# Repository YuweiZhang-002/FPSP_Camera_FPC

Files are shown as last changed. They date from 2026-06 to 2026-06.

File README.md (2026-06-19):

# FPSP_Camera_FPC

This repo contains FPC schematics of the newly developed FPSP camera project on an FPC board, aiming for super-high-speed parallel image processing.

## Repository Structure
| Directory | Use |
| --- | --- |
| archive_old/ | Archived initial design (**not working**) |
| custom_fp/ | Footprint from external libraries |
| docs/ | Documentation gathered from external sources |
| camera_bringup_min/ | RP2350 firmware: OV5640 driver and PIO heartbeat |

## TODO
- [x] RP2350 Power Supply Layout
- [ ] Add Proper Power Sequencing
- [ ] Source RP2354 A4
- [ ] Source B2B Connector
- [x] B2B Connector Pinout + Layout
- [x] HSTX Layout

## 12/12/2025 PCB ordering notes

- order FR-4 board with SMT assembly, run thru **functionality tests**
- order FPC without SMT assembly, test the **FPC characteristics and stiffener position**
- RP2345A and ICM45686 IMU ordered separately to test the functionality. Once it passes the prototype test, order at JLCPCB via **global sourcing** and prep for next assembly

### TODO
 - [x] Place JLCPCB order
 - [ ] functionality test, FR4 prototype
 - [ ] functionality test, FPC stiffener position
------ 
 - [ ] sourcing RP2345A
 - [ ] sourcing ICM45686
 - [ ] sourcing board-to-board connectors from Molex 

## Firmware

Camera (OV5640) bring-up firmware for the Raspberry Pi RP2350 (pico2 board).

### Build

Standard Raspberry Pi Pico SDK CMake project. Open it with the
**Raspberry Pi Pico** VS Code extension, or configure manually:

```sh
cmake -B build -G Ninja
cmake --build build
```

Target platform: `rp2350` / board `pico2` (set in `CMakeLists.txt`).

Key files: `main.c`, `camera_bringup_min/` (OV5640 driver + PIO heartbeat),
`CMakeLists.txt`, `pico_sdk_import.cmake`.

### Firmware dependencies

Depends on the [Raspberry Pi Pico SDK](https://github.com/raspberrypi/pico-sdk)
(v2.2.0), licensed under BSD-3-Clause. The SDK is **not** included in this
repository — install it via the Pico VS Code extension or set the
`PICO_SDK_PATH` environment variable to your local SDK checkout.

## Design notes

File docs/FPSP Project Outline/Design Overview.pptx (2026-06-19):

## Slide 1

Design Overview: one processing unit

Industrial CMOS sensor

(front-end integrated)

Options:
Sony: IMX273 / IMX287
OnSemi: python series
Teledyne: EV76C560 / EV76C570

one “pixel”

Vdd

MSPM0C1104 microcontroller

comp flag

global I/O

registers

enable flag

E

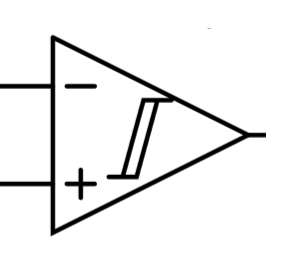
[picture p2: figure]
enter image description here

neighbour I/O & register values

A/D bus

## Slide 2

Design Overview: overall architecture

pixel unit

pixel processor

N pixels

···

···

···

···

···

···

Pixel array

···

···

N pixels

Himax HX6537-A
Pixel Array Microprocessor

···

···

A/D bus 1

···

A/D bus k

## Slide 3

Model | Resolution (pixels) | Pixel Size (µm) | Optical Format | Max Frame Rate (fps) | Output Interface(s) | Notes
Sony IMX273 | 1456 × 1088 (~1.58 MP) | 3.45 × 3.45 | 1/2.9″ (~6.3 mm) | ~226.5 (10-bit mode) | Sub-LVDS / MIPI (varies) | Low-noise, high-speed, common in inspection
Sony IMX287 | 728 × 544 (~0.4 MP) | 6.9 × 6.9 | 1/2.9″ (~6.3 mm) | ~436.9 (10-bit mode) | Sub-LVDS / MIPI (varies) | Large pixels, high sensitivity, good in NIR / low light
OnSemi PYTHON1300 | 1280 × 1024 (1.3 MP) | 4.8 × 4.8 | 1/2″ | ~210 (LVDS) / ~43 (parallel) | LVDS (multi-lane) / parallel | supports ROI, programmable gain, CDS.
OnSemi PYTHON5000 | 2592 × 2048 (~5.3 MP) | 4.8 × 4.8 | ~1″ | Up to ~100 (Zero ROT mode) | LVDS (e.g., 8-lane) | Higher resolution, suited for machine vision with high data bandwidth.
Teledyne EV76C560 | 1280 × 1024 (1.31 MP) | 5.3 × 5.3 | 1/1.8″ | ~60 full res (VGA/cropped >100) | Parallel 10-bit | Dual shutter modes, WDR/HDR, ROI, defect correction.
Teledyne EV76C570 | 1600 × 1200 (~2.0 MP) | 4.5 × 4.5 | 1/1.8″ | ~50 full res | Parallel 10-bit | 2 MP variant, good low-light and dynamic range features.

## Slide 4

Design Overview: overall architecture v2.0

OV5640

···

FPC

DVP

PIO

···

RP2354A

Inter-FPC connection

Strengthened FPC

Pin Header

FPGA board
(pynq / zynq)

PL: data receive
PS: data process

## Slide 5

Layout Overview

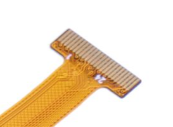
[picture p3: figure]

Main FPC

Strengthened FPC

BUCK/LDO

Pin Header to FPGA

OV5640
(front)

ZIF Connector

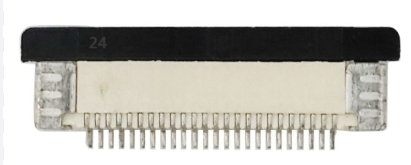
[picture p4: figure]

Vin

···

···

RP2354A
(back)

ASM330LHH
(back)

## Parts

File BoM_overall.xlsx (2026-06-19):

Part Name | Series Number / Description | Quantity | Source | Unit Price (GBP) | Order Code / Mouser No | Link
USB_B_Micro | USB_Micro-B_Molex_47346-0001 | 5 | Farnell | 1.2 | 1568026 | https://uk.farnell.com/molex/47346-0001/micro-usb-conn-2-0-type-b-r-a/dp/1568026
Conn_02x04_Counter_Clockwise | Molex_SlimStack_502430-0822_2x04_P0.40mm_Vertical | 5 | Mouser | 0.52 | 538-50243-00822 | https://www.mouser.co.uk/ProductDetail/Molex/502430-0822?qs=byeeYqUIh0ORWNduRUQWFQ%3D%3D
Conn_02x07_Counter_Clockwise | Molex_SlimStack_502430-1430_2x07_P0.40mm_Vertical | 10 | Farnell | 0.465 | 3911710 | https://uk.farnell.com/molex/502430-1430/mezzanine-conn-hdr-14pos-2row/dp/3911710
Conn_02x04_Counter_Clockwise | Molex_SlimStack_502426-0812_2x04_P0.40mm_Vertical | 5 | Mouser | 0.55 | 538-50242-60812 | https://www.mouser.co.uk/ProductDetail/Molex/502426-0812?qs=byeeYqUIh0O%252BW14PukUHXw%3D%3D
Conn_02x07_Counter_Clockwise | Molex_SlimStack_502426-1430_2x07_P0.40mm_Vertical | 10 | Farnell | 0.868 | 3500584 | https://uk.farnell.com/molex/502426-1430/mezzanine-conn-rcpt-14pos-2row/dp/3500584
SM03B-SRSS-TB | JST_SH_SM03B-SRSS-TB_1x03-1MP_P1.00mm_Horizontal | 5 | Farnell | 0.52 | 1679118 | https://uk.farnell.com/jst-japan-solderless-terminals/sm03b-srss-tb-lf-sn/header-r-a-3way/dp/1679118
IMU | ICM-45686 | 5 | Farnell | 7.884 | 4572492 | https://uk.farnell.com/tdk/icm-45686/mems-module-6-axis-1-71v-3-6v/dp/4572492
LDO | TLV73315PDRV | 5 | Mouser | 0.44 | 595-TLV73315PQDRVRQ1 | https://www.mouser.co.uk/ProductDetail/Texas-Instruments/TLV73315PQDRVRQ1?qs=Euq2YPj5ArIsMkihzFWY8w%3D%3D
MCU | RP2354A | 5 | Mouser | 0.751 | 358-SC151113 | https://www.mouser.co.uk/ProductDetail/Raspberry-Pi/SC151113-A4?qs=4dK74SdgGtxoqGOrTUEtvA%3D%3D
Mems | SiT8008BI-13-33E-12.000000G | 5 | Mouser | 0.721 | 788-8008BI1333E12G | https://www.mouser.co.uk/ProductDetail/SiTime/SiT8008BI-13-33E-12.000000G?qs=dMZC7um9hO8fSmv9H8HgEQ%3D%3D
FPC socket | molex 52435-2471 | 10 | Farnell | 2.352 | 2396220 | https://uk.farnell.com/molex/52435-2471/connector-ffc-fpc-24pos-1row-0/dp/2396220
Camera | OV5640 - 24pin fpc | 2 | Ali | N/A | N/A | https://www.aliexpress.com/p/tesla-landing/index.html?UTABTest=aliabtest125094_24784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
2.54mm pin header: from UCL
0603 R&C: from UCL

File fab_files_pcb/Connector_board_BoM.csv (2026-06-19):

Reference | Qty | Value | DNP | Exclude from BOM | Exclude from Board | Footprint | Datasheet
D1 | 1 | LED |  |  |  | Diode_SMD:D_0603_1608Metric | ~
J1 | 1 | USB_B_Micro |  |  |  | Connector_USB:USB_Micro-B_Molex_47346-0001 | ~
J2 | 1 | Conn_02x04_Counter_Clockwise |  |  |  | Connector_Molex:Molex_SlimStack_502430-0820_2x04_P0.40mm_Vertical | ~
J3 | 1 | Conn_02x06_Counter_Clockwise |  |  |  | Connector_PinHeader_2.54mm:PinHeader_2x06_P2.54mm_Vertical | ~
J4 | 1 | Conn_02x07_Counter_Clockwise |  |  |  | Connector_Molex:Molex_SlimStack_502430-1410_2x07_P0.40mm_Vertical | ~
J5 | 1 | SM03B-SRSS-TB |  |  |  | Connector_JST:JST_SH_SM03B-SRSS-TB_1x03-1MP_P1.00mm_Horizontal | ~
R1 | 1 | 10k |  |  |  | Resistor_SMD:R_0603_1608Metric_Pad0.98x0.95mm_HandSolder | ~

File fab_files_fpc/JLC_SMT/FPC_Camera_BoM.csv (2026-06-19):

Comment | Designator | Footprint | LCSC Part Number | Qty | DNP | Exclude from BOM | Exclude from Board
0.1u | C1,C2,C15,C16,C21,C22,C23 | Capacitor_SMD:C_0402_1005Metric | C60474 | 7
100n | C3,C5,C6,C7,C8,C9,C10,C11,C12,C13,C14,C25,C32 | Capacitor_SMD:C_0402_1005Metric | C60474 | 13
4.7u | C4,C17,C18,C19 | Capacitor_SMD:C_0402_1005Metric | C106859 | 4
100n | C20 | Capacitor_SMD:C_0603_1608Metric_Pad1.08x0.95mm_HandSolder | C1590 | 1 | DNP |  | Excluded from board
22pF | C24 | Capacitor_SMD:C_0402_1005Metric | C106203 | 1
1u | C26,C27,C28,C29,C30,C31 | Capacitor_SMD:C_0402_1005Metric | C106253 | 6
LED | D1,D2,D3,D4 | Diode_SMD:D_0603_1608Metric | C2286 | 4
MountingHole | H1,H2,H3,H4 | MountingHole:MountingHole_2.7mm_M2.5 | N/A | 4
Conn_01x24_Socket | J1 | Connector_FFC-FPC:TE_2-1734839-3_1x23-1MP_P0.5mm_Horizontal | C6668214 | 1
Conn_02x04_Counter_Clockwise | J2 | Connector_Molex:Molex_SlimStack_502426-0810_2x04_P0.40mm_Vertical | C563931 | 1
Conn_02x07_Counter_Clockwise | J3 | Connector_Molex:Molex_SlimStack_502426-1410_2x07_P0.40mm_Vertical | C563932 | 1
SM03B-SRSS-TB | J4 | Connector_JST:JST_SH_SM03B-SRSS-TB_1x03-1MP_P1.00mm_Horizontal | N/A | 1 | DNP |  | Excluded from board
USB_B_Micro | J5 | RP2350_60QFN_minimal:USB_Micro-B_Amphenol_10103594-0001LF_Horizontal_modified | N/A | 1 | DNP |  | Excluded from board
Conn_02x06_Odd_Even | J6 | Connector_PinHeader_2.54mm:PinHeader_2x06_P2.54mm_Vertical | N/A | 1 | DNP |  | Excluded from board
Conn_01x02 | J7 | Connector_PinHeader_2.54mm:PinHeader_1x02_P2.54mm_Vertical | C492401 | 1
SolderJumper_2_Open | JP1,JP2,JP3 | Jumper:SolderJumper-2_P1.3mm_Open_RoundedPad1.0x1.5mm | N/A | 3 |  | Excluded from BOM
3.3u | L1 | Inductor_SMD:L_pol_2016 | C42411119 | 1
10k | R1 | Resistor_SMD:R_0402_1005Metric_Pad0.72x0.64mm_HandSolder | C60489 | 1
33 | R2 | Resistor_SMD:R_0402_1005Metric | C15011 | 1
27 | R3,R4 | Resistor_SMD:R_0402_1005Metric | C15011 | 2
DNF | R5,R8 | Resistor_SMD:R_0603_1608Metric_Pad0.98x0.95mm_HandSolder | N/A | 2 | DNP |  | Excluded from board
1k | R6,R15 | Resistor_SMD:R_0402_1005Metric | C105637 | 2
0 | R7 | Resistor_SMD:R_0603_1608Metric_Pad0.98x0.95mm_HandSolder | N/A | 1 | DNP |  | Excluded from board
0R | R9,R11,R13 | Resistor_SMD:R_0402_1005Metric | C60485 | 3
DNF | R10 | Resistor_SMD:R_0402_1005Metric | N/A | 1
10k | R12,R14,R16,R17,R18,R19,R20,R21 | Resistor_SMD:R_0402_1005Metric | C60489 | 8
TestPoint | TP1 | TestPoint:TestPoint_Pad_D1.0mm | N/A | 1
ICM-45686 | U1 | ICM_45686:IC_ICM-45686 | N/A | 1
W25Q128JVS | U2 | Package_SO:SOIC-8_5.3x5.3mm_P1.27mm | N/A | 1 | DNP |  | Excluded from board
RP2354A_60QFN | U3 | projLib:RP2350-QFN-60-1EP_7x7_P0.4mm_EP3.4x3.4mm_ThermalVias | C41378174 | 1
TLV75533PDRV | U4 | Package_SON:WSON-6-1EP_2x2mm_P0.65mm_EP1x1.6mm | C2861750 | 1
TLV73328PDRV | U5 | Package_SON:WSON-6-1EP_2x2mm_P0.65mm_EP1x1.6mm | N/A | 1
TLV73315PDRV | U6 | Package_SON:WSON-6-1EP_2x2mm_P0.65mm_EP1x1.6mm | N/A | 1
SiT8008xx-1x-xxE | Y1 | Oscillator:Oscillator_SMD_SiT_PQFN-4Pin_2.5x2.0mm | C825127 | 1

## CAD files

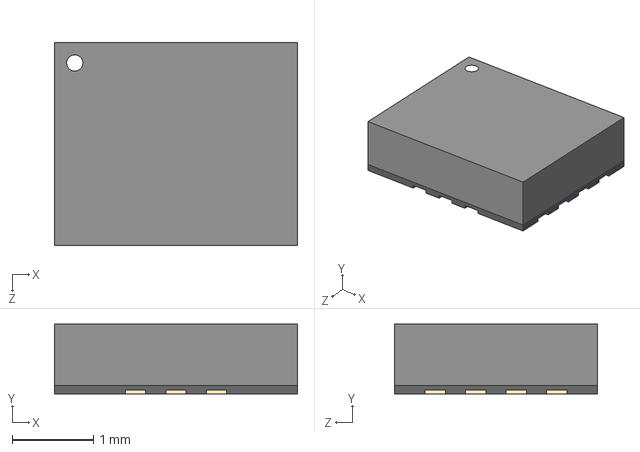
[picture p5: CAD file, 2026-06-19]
custom_fp/ICM_45686/ICM-45686.step
3.00 x 0.86 x 2.50 mm

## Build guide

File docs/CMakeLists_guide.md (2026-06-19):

# CMakeLists 编写与模块化构建指南

> 工程根目录：`D:\Cursor\New_Tests`
> 目标芯片：RP2350（Pico 2）
> SDK：本地路径 `pico-sdk-master`（version 2.2.0）
> 构建系统：CMake + Ninja，由 VS Code Raspberry Pi Pico 扩展驱动

---

## 1. 核心概念：CMake Target 导入机制（为什么能用 hardware_i2c）

这是理解整个 Pico SDK 构建的关键。

### 1.1 不是"#include 头文件"就能用库 —— 是"链接一个 CMake target"

用户容易混淆两个概念：

**❌ 错误认知：**
```
#include "hardware/i2c.h"        ← 这只是让 C 预处理器找到头文件
→ 系统就能用 i2c 库了
```

**✅ 正确流程：**
```
第1步（CMake 配置阶段）：
  └─ pico_sdk_init() 
     └─ 读取 pico-sdk-master/ 内部的 CMake 脚本
        └─ 定义一个虚拟的"target"叫 hardware_i2c
           ├─ 这个 target 包含：
           │   ├─ 源文件在哪（<SDK>/src/rp2_common/hardware_i2c/...）
           │   ├─ 头文件目录在哪（指向 hardware_i2c.h）
           │   └─ 依赖什么其他库（hardware_base, hardware_gpio, ...）
           └─ 在 CMake 全局作用域注册这个 target 的定义

第2步（编译阶段）：
  └─ 你写 target_link_libraries(new_tests_app PUBLIC hardware_i2c)
     └─ CMake 查全局 target 表，找到 hardware_i2c 的定义
        └─ 提取该 target 的：源文件 → 编译、头文件路径 → -I 选项、依赖 → 递归链接
        └─ 把这些信息传给编译器

第3步（代码编译）：
  └─ 编译 main.c
     └─ C 预处理器执行 #include "hardware/i2c.h"
        └─ 使用第2步 CMake 提供的 -I<path-to-header> 找到它
```

**一句话：** `target_link_libraries()` 是 CMake 层面的"声明依赖"，`#include` 是 C 层面的"查找头文件"，两者缺一不可，但发生在不同阶段。

### 1.2 pico-sdk-master 的三层结构

```
pico-sdk-master/
│
├─ pico_sdk_init.cmake           ← 核心：定义所有 target（hardware_i2c、pico_stdlib 等）
│  （被 pico_sdk_import.cmake 的 include() 语句触发）
│
├─ pico_sdk_import.cmake         ← 定位脚本：告诉 CMake "SDK 根在哪"
│  （你的工程根目录有一份副本，你 include() 的是那一份）
│
├─ CMakeLists.txt                ← 仅当 SDK 作为独立 CMake 项目时用
│  （你的工程不用它；它让 SDK 开发者能 cd pico-sdk-master && cmake . && make）
│
├─ src/rp2_common/
│  ├─ hardware_i2c/
│  │  ├─ i2c.c
│  │  └─ include/hardware/i2c.h
│  ├─ hardware_gpio/
│  │  ├─ gpio.c
│  │  └─ include/hardware/gpio.h
│  └─ ...
│
├─ external/
│  └─ pico_sdk_import.cmake       ← 模板原件（供用户复制）
│
└─ cmake/
   ├─ hardware_i2c.cmake          ← 定义 hardware_i2c target 的脚本
   ├─ hardware_gpio.cmake
   └─ ...（pico_sdk_init.cmake 会遍历这些文件）
```

### 1.3 执行流程图（从你的根 CMakeLists 到系统识别 hardware_i2c）

```mermaid
flowchart TD
    A["根 CMakeLists.txt<br/>include pico_sdk_import.cmake"] -->|1. 此时寻找 SDK 路径| B["pico_sdk_import.cmake<br/>读 PICO_SDK_PATH 环境变量/缓存"]
    B -->|2. 定位成功| C["pico_sdk_import.cmake<br/>include ${PICO_SDK_PATH}/pico_sdk_init.cmake"]
    C -->|3. 进入 SDK 初始化| D["pico_sdk_init.cmake<br/>遍历 cmake/ 目录"]
    D -->|4. 发现 hardware_i2c.cmake| E["hardware_i2c.cmake<br/>执行 add_library + include_dirs + source_dir"]
    E -->|5. 在全局 target 表注册| F["CMake 全局作用域<br/>现在有 hardware_i2c target"]
    
    G["后续你的代码<br/>target_link_libraries app hardware_i2c"] -->|6. 查询全局表| F
    F -->|7. 找到 target| H["CMake 提取：<br/>- 源文件位置<br/>- 头文件路径<br/>- 依赖关系"]
    H -->|8. 传给编译器| I["clang/gcc<br/>-I&lt;i2c.h 路径&gt; -l&lt;i2c lib&gt;"]
    
    J["你的 main.c<br/>#include 'hardware/i2c.h'"] -->|9. C 预处理| K["预处理器<br/>查找 -I 指定的路径"]
    K -->|10. 命中| L["找到文件<br/>include/hardware/i2c.h"]
```

---

## 2. 目录结构与分层职责

```text
New_Tests/                         ← 工程根
├─ CMakeLists.txt                  ← 顶层：定义最终可执行文件 + 组装模块
├─ pico_sdk_import.cmake           ← 工程自己的 SDK 定位脚本（从 SDK/external/ 复制）
├─ main.c                          ← 应用入口
│
├─ build/                          ← CMake 构建产物（可删）
│  └─ new_tests_app.uf2
│
├─ docs/
│  └─ CMakeLists_guide.md          ← 本文件
│
├─ camera_bringup_min/             ← 驱动层模块 1
│  ├─ CMakeLists.txt               ← 模块构建脚本
│  ├─ ov5640.c / ov5640.h
│  └─ heartbeat.pio
│
├─ imu_driver/                     ← 驱动层模块 2（示例）
│  ├─ CMakeLists.txt               ← 模块构建脚本
│  ├─ mpu6050.c / mpu6050.h
│  └─ ...
│
└─ pico-sdk-master/                ← Pico SDK（第三方，不动）
   ├─ pico_sdk_init.cmake          ← 定义所有 hardware_* target
   ├─ pico_sdk_import.cmake        ← 定位脚本副本
   ├─ CMakeLists.txt               ← SDK 自己的构建（你不用）
   ├─ src/rp2_common/
   └─ cmake/
```

| 层级 | CMakeLists 职责 | 禁忌 |
|---|---|---|
| **顶层（New_Tests/）** | ① 找 SDK (`include(pico_sdk_import.cmake)`) ② 初始化 SDK (`pico_sdk_init()`) ③ 注册所有子模块 (`add_subdirectory`) ④ 定义最终可执行文件 (`add_executable`) ⑤ 链接库 | 不要在这里写 `add_library(驱动库 ...)` |
| **模块层（camera_bringup_min/ 等）** | ① 定义该模块是静态库还是对象库 (`add_library`) ② 暴露自己的头文件目录 (`target_include_directories PUBLIC`) ③ 声明自己的依赖 (`target_link_libraries PUBLIC`) | 不要 `include(pico_sdk_import.cmake)` / `project()` / `pico_sdk_init()` |
| **SDK（pico-sdk-master/）** | 不写 | 完全不动 |

---

## 3. 顶层 `CMakeLists.txt` 完整模板与逐行解读

```cmake
# ========== 区块 A：VS Code 扩展样板（保持不动）==========
if(WIN32)
    set(USERHOME $ENV{USERPROFILE})
else()
    set(USERHOME $ENV{HOME})
endif()
set(sdkVersion 2.2.0)
set(toolchainVersion 14_2_Rel1)
set(picotoolVersion 2.2.0-a4)
set(picoVscode ${USERHOME}/.pico-sdk/cmake/pico-vscode.cmake)
if (EXISTS ${picoVscode})
    include(${picoVscode})
endif()
# 说明：VS Code 扩展启动时自动补充此段，包含交叉编译工具链路径
# ============================================================

# ========== 区块 B：CMake 基础设定 ==========
cmake_minimum_required(VERSION 3.13...3.27)

# 关键：在 project() 之前 include SDK 定位脚本
# 这样工具链才能及时切到 ARM 交叉编译
include(pico_sdk_import.cmake)

# 声明项目名 + 支持的语言
# C：C 代码
# CXX：C++ 代码  
# ASM：ARM 汇编（必要，不是可选）
project(new_tests C CXX ASM)

# 设置代码标准
set(CMAKE_C_STANDARD 11)
set(CMAKE_CXX_STANDARD 17)

# ========== 区块 C：芯片 / 板型选择（pico_sdk_init 之前）==========
if(NOT DEFINED PICO_PLATFORM)
    set(PICO_PLATFORM rp2350)  # RP2040 / RP2350 / RP2350-arm-s / RP2350-riscv
endif()
if(NOT DEFINED PICO_BOARD)
    set(PICO_BOARD pico2)      # pico / pico_w / pico2 / pico2_w
endif()

# ========== 区块 D：初始化 SDK（在这里把所有 target 导入到全局作用域）==========
# 这个函数会：
# 1. 遍历 pico-sdk-master/cmake/ 目录下所有 .cmake
# 2. 逐个执行，每个都调用 add_library() 定义一个 target
#    → hardware_i2c target、hardware_gpio target、pico_stdlib target ...
# 3. 把这些 target 注册到 CMake 全局 target 表
# 4. 后续 add_subdirectory() 和 add_executable() 都能看到这些 target
pico_sdk_init()

# ========== 区块 E：组装模块层（此时所有 SDK target 已就位）==========
# 每个 add_subdirectory() 都会：
# 1. 切换到那个目录的 CMakeLists.txt
# 2. 执行其中的 add_library()，新增一个用户定义的 target
# 3. 回到根 CMakeLists 继续
add_subdirectory(camera_bringup_min)
add_subdirectory(imu_driver)         # 新增模块示例

# ========== 区块 F：定义最终可执行文件 ==========
add_executable(new_tests_app
    main.c
)

# 处理 .pio 文件：编译为 .pio.h 并加入 include 路径
pico_generate_pio_header(new_tests_app
    ${CMAKE_CURRENT_LIST_DIR}/camera_bringup_min/heartbeat.pio
)

# 声明本 executable 的 include 搜索路径
# PRIVATE：这个 include 路径不会传递给链接本 target 的上游
# （这里用 PRIVATE 是对的，因为 main 是最终目标，没有上游）
target_include_directories(new_tests_app PRIVATE
    ${CMAKE_CURRENT_LIST_DIR}/camera_bringup_min
    ${CMAKE_CURRENT_LIST_DIR}/imu_driver
)

# ========== 区块 G：链接依赖（核心）==========
# target_link_libraries 是 CMake 从 target 表里提取依赖信息的地方
# PUBLIC：依赖会传递给链接本 target 的上游（新_tests_app 是最终目标，实际没上游）
# PRIVATE：依赖只给自己用，不向外传播
target_link_libraries(new_tests_app
    # SDK 标准库
    pico_stdlib                      # stdio_init_all, sleep_ms, printf 重定向
    
    # 硬件库（由 pico_sdk_init() 导入）
    hardware_pio                      # PIO 状态机
    
    # 用户定义的驱动模块（由 add_subdirectory() 注册）
    camera_bringup_min               # 调用其 CMakeLists 中的 add_library()
    imu_driver
)

# ========== 区块 H：stdio 配置 ==========
pico_enable_stdio_uart(new_tests_app 1)  # 1 = 启用；0 = 禁用
pico_enable_stdio_usb(new_tests_app 0)   # 本工程用 UART，不用 USB CDC

# ========== 区块 I：生成附加产物 ==========
# 只有 ELF 满足调试需求，还要生成：
# - .uf2：烧录格式（Pico 的 UF2 bootloader 认这个）
# - .hex：十六进制（某些烧录工具用）
# - .bin：纯二进制（无 header）
# - .map：链接器 map，看符号地址和段布局
# - .dis：反汇编，看生成的 arm 指令
pico_add_extra_outputs(new_tests_app)
```

### 关键顺序约束（红线规则）

```
❌ WRONG                          ✅ CORRECT
───────────────────────────────────────────────────────
project()                         include(pico_sdk_import.cmake)
include(sdk)                      project()
PICO_PLATFORM = ...               PICO_PLATFORM = ...
pico_sdk_init()                   pico_sdk_init()
                                  add_subdirectory()
pico_sdk_init()                   add_executable()
add_subdirectory()
```

---

## 4. 模块层 `CMakeLists.txt` 完整模板

**场景：** 你在 `camera_bringup_min/` 下写 CMakeLists.txt

```cmake
# ========== 模块基本信息 ==========
# 通常写成注释说明这个模块的用途
# camera_bringup_min: OV5640 相机 SCCB 初始化 + RGB565 配置
# 依赖：hardware_gpio, hardware_i2c, hardware_pwm, hardware_clocks

# ========== 定义静态库 ==========
# add_library(<库名> <库类型> <源文件>...)
# 库名：必须和顶层 CMakeLists 中 target_link_libraries 写的名字一致
# 库类型：
#   STATIC  - 静态库 .a（编译时链接，不是 DLL）
#   SHARED  - 动态库 .so/.dll（运行时加载）
#   OBJECT  - 对象库（仅作中间产物，不生成 .a）
#   INTERFACE - 仅头文件，不编译源代码
add_library(camera_bringup_min STATIC
    ov5640.c
)

# ========== 暴露头文件目录 ==========
# 目的：让调用方能写 #include "ov5640.h"（而不是 #include "camera_bringup_min/ov5640.h"）
# 作用域：
#   PUBLIC   - 调用方也能用这个 include 路径
#              （假设 ov5640.h 里有调用方需要的类型定义）
#   PRIVATE  - 只给自己用，不向外暴露
#   INTERFACE - 不给自己用，只暴露给调用方（纯头文件库用这个）
target_include_directories(camera_bringup_min PUBLIC
    ${CMAKE_CURRENT_LIST_DIR}
)

# ========== 声明依赖关系 ==========
# 目的：告诉 CMake 这个库需要什么
# 作用：
#   1. 编译 camera_bringup_min 时会获得这些依赖的编译选项（-I / -D 等）
#   2. 当上层 target_link_libraries(app camera_bringup_min) 时，
#      这些依赖会自动"传播"给 app（因为用的是 PUBLIC）
target_link_libraries(camera_bringup_min PUBLIC
    pico_stdlib                    # 使用 printf、sleep_ms
    hardware_gpio                  # gpio_init、gpio_set_dir
    hardware_i2c                   # i2c_init、i2c_write_blocking
    hardware_pwm                   # pwm_init（XCLK 输出）
    hardware_clocks                # clock_get_hz
)
```

### 为什么模块层不需要 `include(pico_sdk_import.cmake)`？

因为这个脚本只需要执行一次，就能把所有 target 注册到全局作用域。一旦执行过，所有 `add_subdirectory()` 的子模块都能看到。

```
顶层 CMakeLists：
  include(pico_sdk_import.cmake)    ← 一次性，全局生效
  pico_sdk_init()                   ← 把 hardware_i2c 等 target 写进全局表
  add_subdirectory(camera_bringup_min)
    ↓
    camera_bringup_min/CMakeLists：
      （不需要 include，hardware_i2c 已在全局表）
      target_link_libraries(camera_bringup_min PUBLIC hardware_i2c)
      ✅ 能找到 hardware_i2c
```

---

## 5. PUBLIC / PRIVATE / INTERFACE 三大作用域

这是 CMake 最容易踩坑的地方。表格说明：

| 关键字 | 自己编译时用 | 链接进自己时用 | 上游链接自己时用 |
|---|---|---|---|
| **PRIVATE** | ✅ | ✅ | ❌ |
| **PUBLIC** | ✅ | ✅ | ✅ |
| **INTERFACE** | ❌ | ❌ | ✅ |

### 实战例子

**模块 `camera_bringup_min`：**
```cmake
target_include_directories(camera_bringup_min PUBLIC
    ${CMAKE_CURRENT_LIST_DIR}
)
```
→ 为什么 PUBLIC？
  - camera_bringup_min 自己用 ov5640.h，需要这个 include 路径 ✅
  - main.c（上游）也要 `#include "ov5640.h"`，也需要这个路径 ✅
  - 所以必须是 PUBLIC

```cmake
target_link_libraries(camera_bringup_min PUBLIC
    hardware_i2c
)
```
→ 为什么 PUBLIC？
  - camera_bringup_min 编译时需要 hardware_i2c 的源文件和头文件 ✅
  - ov5640.h 里如果暴露了 i2c_inst_t 类型给调用方，main.c 包含它时编译器需要找到 hardware/i2c.h ✅
  - 所以必须是 PUBLIC

**应用 `new_tests_app`：**
```cmake
target_include_directories(new_tests_app PRIVATE
    ${CMAKE_CURRENT_LIST_DIR}/camera_bringup_min
)
```
→ 为什么 PRIVATE？
  - new_tests_app 本身是最终目标，没有上游链接它 ✅ PRIVATE 足矣
  - （即便用 PUBLIC，也不会有不同，因为没人链接 new_tests_app）

```cmake
target_link_libraries(new_tests_app
    camera_bringup_min
)
```
→ 作用域选择？
  - new_tests_app 是最终可执行文件，不会被其他 target 链接
  - 使用 PRIVATE 或 PUBLIC 都行，通常用 PRIVATE 表示"这是内部细节"

---

## 6. Pico SDK 核心函数速查

| 函数 | 何时用 | 用在哪 |
|---|---|---|
| `pico_sdk_init()` | 初始化 SDK，导入所有 hardware_* target | 顶层 CMakeLists，`project()` 之后 |
| `pico_generate_pio_header(<target> <file.pio>)` | 把 .pio 编译成 .pio.h | 顶层 CMakeLists，`add_executable()` 之后 |
| `pico_enable_stdio_uart(<target> 0/1)` | printf 走 UART 还是禁用 | 顶层 CMakeLists，`target_link_libraries()` 之后 |
| `pico_enable_stdio_usb(<target> 0/1)` | printf 走 USB CDC 还是禁用 | 同上 |
| `pico_add_extra_outputs(<target>)` | 生成 .uf2 / .hex / .bin / .map / .dis | 顶层 CMakeLists 末尾 |
| `pico_set_program_name(<target> <name>)` | 写名字到 ELF | 可选，`add_executable()` 之后 |

### 常用 SDK 库名

```cmake
target_link_libraries(app
    # 基础
    pico_stdlib           # printf, sleep_ms, stdio_init_all, stdlib 函数
    
    # GPIO / 时钟 / 电源
    hardware_gpio         # gpio_init, gpio_set_dir, gpio_get, gpio_put
    hardware_clocks       # clock_get_hz, set_sys_clock_*
    hardware_pll          # PLL 配置
    
    # 通信
    hardware_i2c          # I²C / SCCB
    hardware_spi          # SPI
    hardware_uart         # 直接 UART 控制（如果不用 stdio_uart）
    
    # 计时
    hardware_pwm          # PWM（包括 XCLK）
    hardware_timer        # 定时器中断
    
    # 数据搬运
    hardware_dma          # DMA 加速数据转移
    hardware_pio          # PIO 状态机（本工程的 heartbeat）
    
    # 其他
    hardware_adc          # ADC / 温度传感器
    pico_multicore        # 多核支持（core0 / core1）
    hardware_watchdog     # 看门狗
)
```

---

## 7. 一个完整的"生产级"多模块工程模板

### 目录结构

```
my_firmware/
├─ CMakeLists.txt                    (顶层)
├─ pico_sdk_import.cmake             (从 SDK 复制)
├─ src/
│   ├─ main.c                        (应用入口)
│   └─ app_config.h
│
├─ drivers/                          (驱动层)
│   ├─ CMakeLists.txt                (组织子模块)
│   ├─ camera/
│   │   ├─ CMakeLists.txt
│   │   ├─ ov5640.c
│   │   ├─ ov5640.h
│   │   └─ ov5640_regs.h
│   │
│   └─ imu/
│       ├─ CMakeLists.txt
│       ├─ mpu6050.c
│       ├─ mpu6050.h
│       └─ mpu6050_regs.h
│
├─ utils/                           (工具库)
│   ├─ CMakeLists.txt
│   ├─ ring_buffer.c
│   ├─ ring_buffer.h
│   └─ crc.c
│
├─ pio/
│   ├─ heartbeat.pio
│   └─ pwm_blink.pio
│
├─ build/                           (CMake 产物)
│   └─ firmware.uf2
│
└─ docs/
    └─ CMakeLists_guide.md
```

### 顶层 CMakeLists.txt

```cmake
cmake_minimum_required(VERSION 3.13...3.27)

if(WIN32)
    set(USERHOME $ENV{USERPROFILE})
else()
    set(USERHOME $ENV{HOME})
endif()
set(sdkVersion 2.2.0)
set(toolchainVersion 14_2_Rel1)
set(picoVscode ${USERHOME}/.pico-sdk/cmake/pico-vscode.cmake)
if (EXISTS ${picoVscode})
    include(${picoVscode})
endif()

include(pico_sdk_import.cmake)
project(my_firmware C CXX ASM)

set(CMAKE_C_STANDARD 11)
set(CMAKE_CXX_STANDARD 17)

set(PICO_PLATFORM rp2350)
set(PICO_BOARD pico2)

pico_sdk_init()

# 添加驱动层和工具层
add_subdirectory(drivers)
add_subdirectory(utils)

# 定义最终应用
add_executable(firmware
    src/main.c
)

pico_generate_pio_header(firmware
    ${CMAKE_CURRENT_LIST_DIR}/pio/heartbeat.pio
    ${CMAKE_CURRENT_LIST_DIR}/pio/pwm_blink.pio
)

target_include_directories(firmware PRIVATE
    ${CMAKE_CURRENT_LIST_DIR}/src
    ${CMAKE_CURRENT_LIST_DIR}/drivers
    ${CMAKE_CURRENT_LIST_DIR}/utils
    ${CMAKE_CURRENT_LIST_DIR}/pio
)

target_link_libraries(firmware
    pico_stdlib
    hardware_pio
    camera_driver
    imu_driver
    utils_lib
)

pico_enable_stdio_uart(firmware 1)
pico_enable_stdio_usb(firmware 0)

pico_add_extra_outputs(firmware)
```

### drivers/CMakeLists.txt（驱动层组织脚本）

```cmake
# drivers/ 本身不定义库，只是组织子模块
add_subdirectory(camera)
add_subdirectory(imu)
```

### drivers/camera/CMakeLists.txt

```cmake
add_library(camera_driver STATIC
    ov5640.c
)

target_include_directories(camera_driver PUBLIC
    ${CMAKE_CURRENT_LIST_DIR}
)

target_link_libraries(camera_driver PUBLIC
    pico_stdlib
    hardware_gpio
    hardware_i2c
    hardware_pwm
    hardware_clocks
)
```

### drivers/imu/CMakeLists.txt

```cmake
add_library(imu_driver STATIC
    mpu6050.c
)

target_include_directories(imu_driver PUBLIC
    ${CMAKE_CURRENT_LIST_DIR}
)

target_link_libraries(imu_driver PUBLIC
    pico_stdlib
    hardware_i2c
    hardware_gpio
)
```

### utils/CMakeLists.txt

```cmake
add_library(utils_lib STATIC
    ring_buffer.c
    crc.c
)

target_include_directories(utils_lib PUBLIC
    ${CMAKE_CURRENT_LIST_DIR}
)

target_link_libraries(utils_lib PUBLIC
    pico_stdlib
)
```

---

## 8. 常见扩展场景

### 场景 A：在已有模块里加新的 .c

修改 `drivers/camera/CMakeLists.txt`：
```cmake
add_library(camera_driver STATIC
    ov5640.c
    ov5640_calib.c      # ← 新增
    ov5640_colorbar.c   # ← 新增
)
```

### 场景 B：增加新驱动模块

1. 创建目录：`drivers/codec/`
2. 添加文件：`drivers/codec/CMakeLists.txt`、`drivers/codec/wm8960.c`、`drivers/codec/wm8960.h`
3. 编写 `drivers/codec/CMakeLists.txt`（照搬模板）
4. 修改 `drivers/CMakeLists.txt`：
   ```cmake
   add_subdirectory(camera)
   add_subdirectory(imu)
   add_subdirectory(codec)    # ← 新增
   ```
5. 修改根 `CMakeLists.txt`：
   ```cmake
   target_link_libraries(firmware
       ...
       codec_driver           # ← 新增
   )
   ```

### 场景 C：换芯片 / 板型

修改根 CMakeLists：
```cmake
set(PICO_PLATFORM rp2040)      # 改成 rp2040
set(PICO_BOARD pico)           # 改成 pico
```

**重要：** 删除 `build/` 目录重新 configure，否则 CMake 缓存会卡住。

### 场景 D：添加新的 .pio 文件

修改根 CMakeLists：
```cmake
pico_generate_pio_header(firmware
    ${CMAKE_CURRENT_LIST_DIR}/pio/heartbeat.pio
    ${CMAKE_CURRENT_LIST_DIR}/pio/pwm_blink.pio
    ${CMAKE_CURRENT_LIST_DIR}/pio/spi_master.pio    # ← 新增
)
```

### 场景 E：多个独立可执行文件（main + 测试工具）

```cmake
# 主程序
add_executable(firmware src/main.c)
target_link_libraries(firmware pico_stdlib camera_driver imu_driver)
pico_add_extra_outputs(firmware)

# I²C 扫描工具
add_executable(i2c_scan tools/i2c_scan.c)
target_link_libraries(i2c_scan pico_stdlib hardware_i2c)
pico_add_extra_outputs(i2c_scan)

# UART 回环测试
add_executable(uart_test tools/uart_test.c)
target_link_libraries(uart_test pico_stdlib hardware_uart)
pico_add_extra_outputs(uart_test)
```

每个都会生成独立的 .uf2，可以分别烧录。

---

## 9. CMake 变量速查表

| 变量 | 作用 | 设置时机 |
|---|---|---|
| `PICO_PLATFORM` | `rp2040` / `rp2350` 等芯片选择 | 顶层 CMakeLists，`pico_sdk_init()` 之前 |
| `PICO_BOARD` | `pico` / `pico2` / `pico_w` 等板型 | 同上 |
| `PICO_SDK_PATH` | SDK 根目录路径 | 环境变量或 VS Code 扩展注入（通常不手改） |
| `CMAKE_CURRENT_LIST_DIR` | 当前 CMakeLists 所在目录 | 自动 |
| `CMAKE_BUILD_TYPE` | `Debug` / `Release` / `MinSizeRel` | VS Code 扩展 UI 选择 |
| `CMAKE_C_STANDARD` | C 标准（11 / 99 / 17） | 顶层 CMakeLists，`project()` 之后 |
| `CMAKE_CXX_STANDARD` | C++ 标准 | 同上 |
| `CMAKE_C_COMPILER` | C 编译器路径 | 交叉编译工具链自动设置 |

---

## 10. 故障排查

| 症状 | 原因 | 修法 |
|---|---|---|
| `undefined reference to gpio_init` | 模块没链接 `hardware_gpio` | 检查 target_link_libraries PUBLIC 是否有 hardware_gpio |
| `pico_sdk_init: command not found` | SDK 没初始化，或顺序错了 | 确保 `include(pico_sdk_import.cmake)` 和 `pico_sdk_init()` 在正确位置 |
| `cannot open source file: "ov5640.h"` | include 路径不对 | 检查模块 CMakeLists 的 `target_include_directories PUBLIC` |
| `heartbeat.pio.h: No such file` | 没调用 `pico_generate_pio_header` | 在根 CMakeLists add_executable 后加上 pico_generate_pio_header |
| 改板子型号后还用旧工具链 | CMake 缓存 | `rm -rf build && cmake ..`（完全重新配置） |
| `target "camera_bringup_min" not found` | 模块没被 add_subdirectory | 检查根 CMakeLists 是否有 `add_subdirectory(camera_bringup_min)` |

---

## 11. 一句话原则

> **顶层负责"初始化 SDK + 组装模块"，模块负责"定义自己是什么库 + 暴露 API"，PUBLIC 关键字代表"这个依赖/路径会传给使用我的人"，删掉 build/ 重来是解决 99% 配置问题的万能药。**

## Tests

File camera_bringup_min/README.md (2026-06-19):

# camera_bringup_min

这是一个面向 RP2354 + OV5640 的最小化 Camera Bring-up 工程，目标不是完整图像接收，而是验证以下信号链是否工作：

- RP2354 是否正常运行
- SCCB(I2C) 是否可以成功配置 OV5640
- OV5640 是否输出 PCLK
- VSYNC / HREF 是否出现跳变
- D0 是否存在数据跳变

## 工程特点

- 使用 Pico SDK
- 不使用 DMA
- 不使用 FIFO
- 不实现完整 RGB565 图像接收
- 不依赖 Linux / OpenCV / V4L2
- 通过 `printf` 输出 bring-up 结果

## 目录说明

- `main.c`：主程序，负责 XCLK、GPIO 输入检测和状态打印
- `ov5640.c` / `ov5640.h`：OV5640 的 SCCB(I2C) 初始化、上电时序、ID 读取、最小 RGB565/DVP 配置
- `heartbeat.pio`：PIO 单引脚心跳，用于验证 RP2354 + PIO 子系统正常运行
- `CMakeLists.txt`：Pico SDK 构建入口

## 正确的运行方式

这个工程不是直接在 bash 里执行一个 `.exe`。Pico SDK 工程通常要先编译，再把生成的 `.uf2` 烧录到开发板。

推荐流程如下：

```bash
cmake -S . -B build
cmake --build build
```

编译完成后，会在 `build/` 下生成 `.uf2` / `.elf` 等文件。把 `.uf2` 拖到 RP2354 的 USB 盘里即可运行。

## 常见错误

如果你在终端里看到类似下面的报错：

```text
bash: enter program name, for example D:\Cursor\project\pico-sdk-master/a.exe: No such file or directory
```

这表示你把 VS Code / 终端里的占位提示当成了真实命令。它不是程序名，也不是可执行文件路径。

原因通常是：

- 还没有完成编译
- 运行配置里的 program 路径为空
- 把提示文本原样输入到了终端

## 默认引脚

引脚已依据 `docs/FPSP Camera.kicad_sch` 实际网表对齐。如果板级连线不同，请修改 `main.c` 和 `ov5640.h` 中的宏定义。

- XCLK: `GPIO26`（INT_XCLK，经 R13 接到相机 XCLK；GP21 实为 DATA6 数据线）
- VSYNC: `GPIO7`
- HREF: `GPIO16`（HSYNC）
- PCLK: `GPIO27`
- D0 差分（IMAGE_OUT_1）正极: `GPIO15` / 负极: `GPIO12`
- D1 差分（IMAGE_OUT_2）正极: `GPIO14` / 负极: `GPIO13`
- I2C SDA: `GPIO10`
- I2C SCL: `GPIO9`
- RESETB: `GPIO8`
- PWDN: 未接到 RP2354（硬件固定到 GND），软件不控制
- 心跳/指示: `GPIO5`（空闲脚；本板无 GPIO 用户 LED，D1~D4 为电源指示灯）

## 串口输出

工程默认启用 UART stdio。上电后可看到类似输出：

- `camera detected`
- `pclk active`
- `href detected`
- `vsync detected`
- `data toggling`

## 备注

当前实现使用了内置 color bar 测试图样，目的是让 DVP 输出更容易被观察和验证。如果你希望改成真实图像输出，可以再把测试图样关闭。

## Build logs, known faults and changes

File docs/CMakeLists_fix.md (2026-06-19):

# CMakeLists & VS Code 配置修复说明（方法 B：CMakeLists 单一事实来源）

修改日期：2026-05-26
项目目标硬件：**Pico 2（RP2350，Cortex-M33 / Arm Secure）**

本次修复采用「方法 B」：把目标芯片/板子的选择权固化在 `CMakeLists.txt` 里，让 Pi Pico VS Code 插件的状态栏选择无法静默覆盖编译目标，彻底消除「json 显示一套、CMake 实际编另一套」的不同步问题。

---

## 一、CMake 配置失败 `exited with code: 1` 的根因分析

CMake Tools 触发的命令（节选）：
```
cmake -DCMAKE_BUILD_TYPE=Debug
      -DCMAKE_C_COMPILER=.../arm-none-eabi-gcc.exe
      -DCMAKE_CXX_COMPILER=.../arm-none-eabi-g++.exe
      -DPython3_EXECUTABLE=d:/Python/python.exe
      -S D:/Cursor/New_Tests  -B d:/Cursor/New_Tests/build  -G Ninja
```
注意：**这条命令没有传 `-DPICO_PLATFORM` 也没有传 `-DPICO_BOARD`**。

### 直接证据：`build/CMakeCache.txt` 与 `build_rp2350/CMakeCache.txt` 对比

| 变量 | `build/`（失败的那个） | `build_rp2350/`（健康的） |
|---|---|---|
| `PICO_PLATFORM` | `rp2350`（未解析为具体子目标） | `rp2350-arm-s`（正确） |
| `PICO_BOARD` | `pico2` | `pico2` |
| `CMAKE_C_FLAGS` | **`-mcpu=cortex-m0plus -mthumb`** ← RP2040 标志 | `-mcpu=cortex-m33 -mthumb -march=armv8-m.main+fp+dsp -mfloat-abi=softfp -mcmse` |
| `CMAKE_CXX_FLAGS` | 同上，cortex-m0plus | 同上，cortex-m33 |
| `CMAKE_ASM_FLAGS` | 同上，cortex-m0plus | 同上，cortex-m33 |
| `CMAKE_BUILD_TYPE` | Debug | Release |

### 失败链路

1. `build/` 这个目录最早是在 `PICO_PLATFORM` 还是 RP2040（默认或被插件初始化为 RP2040）时第一次 configure 出来的，因此 CMake 把 `-mcpu=cortex-m0plus -mthumb` **写进了缓存**。
2. 后来 `CMakeLists.txt` 改成了 `set(PICO_PLATFORM rp2350)`，再次 configure 时：
   - `PICO_PLATFORM` 局部变量更新为 `rp2350`
   - 但缓存里的 `CMAKE_C_FLAGS / CMAKE_CXX_FLAGS / CMAKE_ASM_FLAGS` 是 **CMake 顶级缓存条目，不会因为 `PICO_PLATFORM` 改变而自动重置**（Pico SDK 只在「第一次」根据平台决定这些 flags）
3. CMake 用旧的 cortex-m0plus 标志去编 RP2350 的 SDK 源码 → 编译期断言 / 头文件条件编译失败 / `try_compile` 不通过 → configure 阶段直接退出 `1`。
4. 又因为 `CMake Tools` 子进程**不继承** `settings.json → terminal.integrated.env.windows` 里的 `PICO_SDK_PATH / PICO_TOOLCHAIN_PATH`，依赖这些环境变量的辅助逻辑也可能再绊一脚（但本次主因是上面的 flags 失配）。

### 修复

- **必做**：删除 `build/` 目录（缓存已损坏，无法自愈），让下一次 configure 从零生成。
- **配套**：本次把 `CMakeLists.txt` 里的 `set(PICO_PLATFORM …)` 改成 `CACHE STRING … FORCE`，并放在 `pico_sdk_import.cmake` **之前**，这样以后即使再次出现缓存值漂移，每次 configure 都会被强制刷回正确值。

> 顺手把 `build_pico2/` 也删了；它和 `build_rp2350/` 一样是历史残留，统一构建目录之后不需要保留。如果想留一份能用的 uf2 当备份，先把 `build_rp2350/new_tests_app.uf2` 复制到别处再删。

---

## 二、本次修改的文件清单

### 1. `CMakeLists.txt`
**变更内容**：把 `set(PICO_PLATFORM ...)` 和 `set(PICO_BOARD ...)` 提前到 `include(pico_sdk_import.cmake)` 之前，并改成 `CACHE STRING ... FORCE`。

```cmake
# === Single source of truth for target chip / board (Plan B) ===
# Hardcoded BEFORE pico_sdk_import so the SDK's toolchain selection picks the
# correct cortex-m33 / armv8-m.main flags on first configure.
# CACHE ... FORCE re-asserts the value on every configure, so a stale cache
# entry (e.g. from a previous rp2040 build) cannot win.
# Do NOT use `if(NOT DEFINED ...)` guards here: a stale CACHE value counts as
# defined and would silently keep the wrong target.
set(PICO_PLATFORM rp2350 CACHE STRING "Pico Platform" FORCE)
set(PICO_BOARD    pico2  CACHE STRING "Pico Board"    FORCE)

include(pico_sdk_import.cmake)

project(new_tests C CXX ASM)
```

为什么这样写：
- 必须在 `include(pico_sdk_import.cmake)` 和 `project()` **之前**——SDK 是在 `project()` 触发的工具链初始化阶段读 `PICO_PLATFORM` 来决定 `-mcpu` 等编译参数的，晚于这个时刻设值就来不及。
- 用 `CACHE ... FORCE` 而不是简单 `set(PICO_PLATFORM rp2350)`：FORCE 每次 configure 都会把缓存条目改写成我们要的值，不会被「上一次 configure 把脏值写进 CMakeCache」长期污染。
- **明确不加 `if(NOT DEFINED PICO_PLATFORM)` 守卫**：缓存里有值就算 "defined"，守卫会让脏缓存继续生效——和我们 plan B 的初衷相反。

### 2. `.vscode/settings.json`
**变更内容**：新增一行
```json
"cmake.buildDirectory": "${workspaceFolder}/build",
```
原本没有显式设置 `cmake.buildDirectory`，CMake Tools 走默认 `${workspaceFolder}/build`，但 `tasks.json` / `launch.json` 都指向 `build_rp2350`，IntelliSense (`c_cpp_properties.json`) 又指向 `build` —— 形成三套构建目录互相错位。显式设置以后所有工具都从同一个目录读写。

### 3. `.vscode/tasks.json`
**变更内容**：
- 把所有 `build_rp2350` 替换为 `build`（统一构建目录）
- `Run Project` 任务的主 `command` 字段把 `${env:HOME}` 改成 `${userHome}`（Windows 下 `HOME` 通常未定义，会让 picotool 启动直接失败；虽然 `windows` 字段会兜底，但主字段是无效占位符就不应保留）
- `Flash` 任务里 `target/${command:raspberry-pi-pico.getTarget}.cfg` 替换为字面量 `target/rp2350.cfg`
- `Rescue Reset` 任务里 `target/${command:raspberry-pi-pico.getChip}-rescue.cfg` 替换为字面量 `target/rp2350-rescue.cfg`
- 删掉了 `Flash` / `Rescue Reset` 中尾随的多余逗号（JSON 严格语法虽然 VS Code 容忍，但有些 CI 工具会报错）

为什么把 `${command:...}` 改字面量：这些命令本质上读插件状态栏的当前选择，正好就是「json 和 cmake 不同步」的另一半根源。Plan B 既然钉死了硬件，这里也跟着钉死。

### 4. `.vscode/launch.json`
**变更内容**：
- 所有 `build_rp2350` → `build`
- `${command:raspberry-pi-pico.getGDBPath}` → `${userHome}/.pico-sdk/toolchain/14_2_Rel1/bin/arm-none-eabi-gdb.exe`
- `${command:raspberry-pi-pico.getChipUppercase}` → `RP2350`
- `${command:raspberry-pi-pico.getTarget}` → `rp2350`
- `${command:raspberry-pi-pico.getChip}` → `rp2350`（SVD 路径里）

理由同 `tasks.json`：调试器目标 / SVD 文件 / GDB 路径都钉死在 RP2350 Arm 工具链。

### 5. `.vscode/c_cpp_properties.json`
**变更内容**：`cppStandard` 从 `c++14` 改为 `c++17`，与 `CMakeLists.txt` 里 `set(CMAKE_CXX_STANDARD 17)` 一致。`compileCommands` 和 `forcedInclude` 已经指向 `${workspaceFolder}/build/...`，统一构建目录之后无需再改。

### 6. 未改动但要留意的文件
- `.vscode/cmake-kits.json`：仍使用 `${command:raspberry-pi-pico.getCompilerPath}` 等。当前 toolchain 目录是 `14_2_Rel1`（ARM 工具链），插件命令返回的就是 `arm-none-eabi-gcc`，与 Plan B 一致，因此**不动**。如果未来想完全脱离插件，可再把 `cmake-kits.json` 里的 `${command:...}` 也替换为字面路径。
- `pico_sdk_import.cmake`：SDK 标准模板，不动。

---

## 三、修复后必须执行的操作

> 这一步是为了清掉那个污染的 build 缓存。**直到你做完这步，CMake configure 仍然会失败。**

PowerShell：
```powershell
Remove-Item -Recurse -Force D:\Cursor\New_Tests\build
Remove-Item -Recurse -Force D:\Cursor\New_Tests\build_pico2
# build_rp2350 可选：如果你想保留上次的 uf2，先复制再删
Remove-Item -Recurse -Force D:\Cursor\New_Tests\build_rp2350
```

然后在 VS Code 里：
1. `Ctrl+Shift+P` → **CMake: Delete Cache and Reconfigure** （触发一次干净的 configure）
2. 或者直接重新跑 `Compile Project` 任务

预期：configure 通过，生成 `D:/Cursor/New_Tests/build/new_tests_app.{elf,uf2,bin,hex,dis,map}`，且 `build/CMakeCache.txt` 里 `PICO_PLATFORM=rp2350-arm-s`、`CMAKE_C_FLAGS` 含 `cortex-m33`。

---

## 四、回滚指引

如果将来想换回「跟随插件」模式（方法 A），步骤反过来即可：
1. `CMakeLists.txt`：删除 `set(PICO_PLATFORM ... FORCE)` 和 `set(PICO_BOARD ... FORCE)` 两行
2. `.vscode/tasks.json` / `launch.json`：把 `rp2350` / `RP2350` / 显式 GDB 路径恢复成 `${command:raspberry-pi-pico.getTarget}` / `${command:raspberry-pi-pico.getChipUppercase}` / `${command:raspberry-pi-pico.getGDBPath}`
3. `.vscode/settings.json`：可选删除 `cmake.buildDirectory`（让插件管）
4. 删 `build/`，重新 configure

---

## 五、Run Project 报 `No accessible RP-series devices in BOOTSEL mode were found` 的解决

这个错和 CMake 配置无关，是 picotool 找不到设备。最稳的恢复路径：

1. **按住板上的 BOOTSEL 键，插 USB，松开**——设备直接进入 BOOTSEL 模式
2. 用 Zadig 把 `RP2 Boot` 接口装成 WinUSB 驱动（只需要做一次，之后系统都认）
3. 再次执行 `Run Project` 任务

之后只要你刷入的固件里启用了 `pico_enable_stdio_usb(... 1)`（本项目已启用），picotool 就能通过 USB 重启接口自动把设备切到 BOOTSEL，下次起不再需要手按按键。

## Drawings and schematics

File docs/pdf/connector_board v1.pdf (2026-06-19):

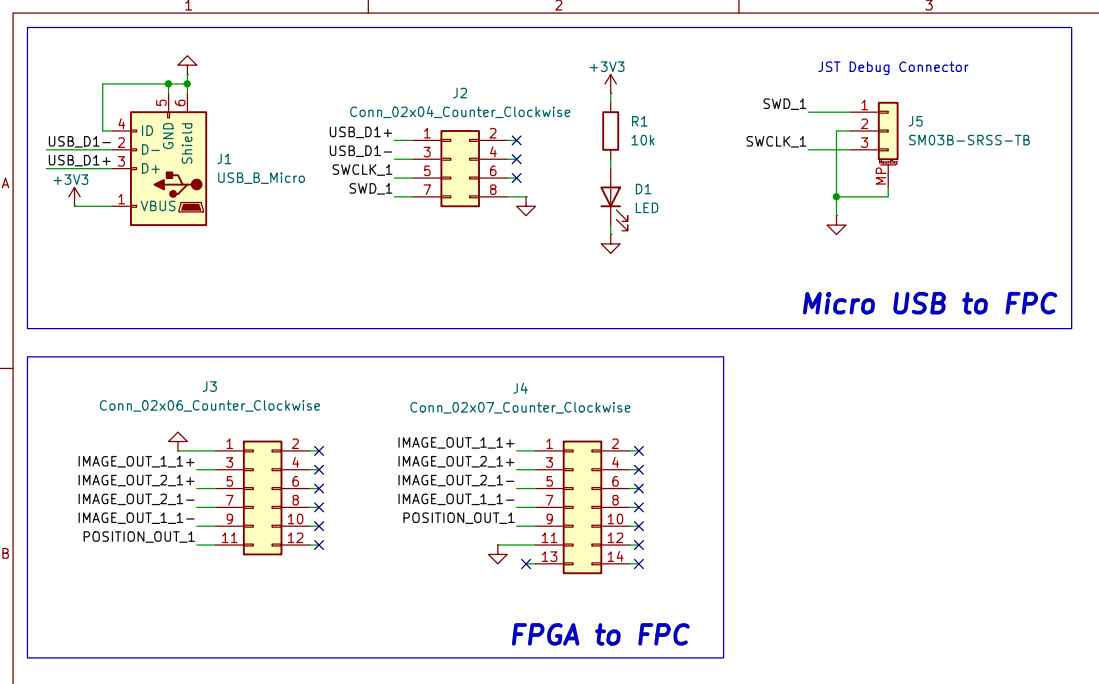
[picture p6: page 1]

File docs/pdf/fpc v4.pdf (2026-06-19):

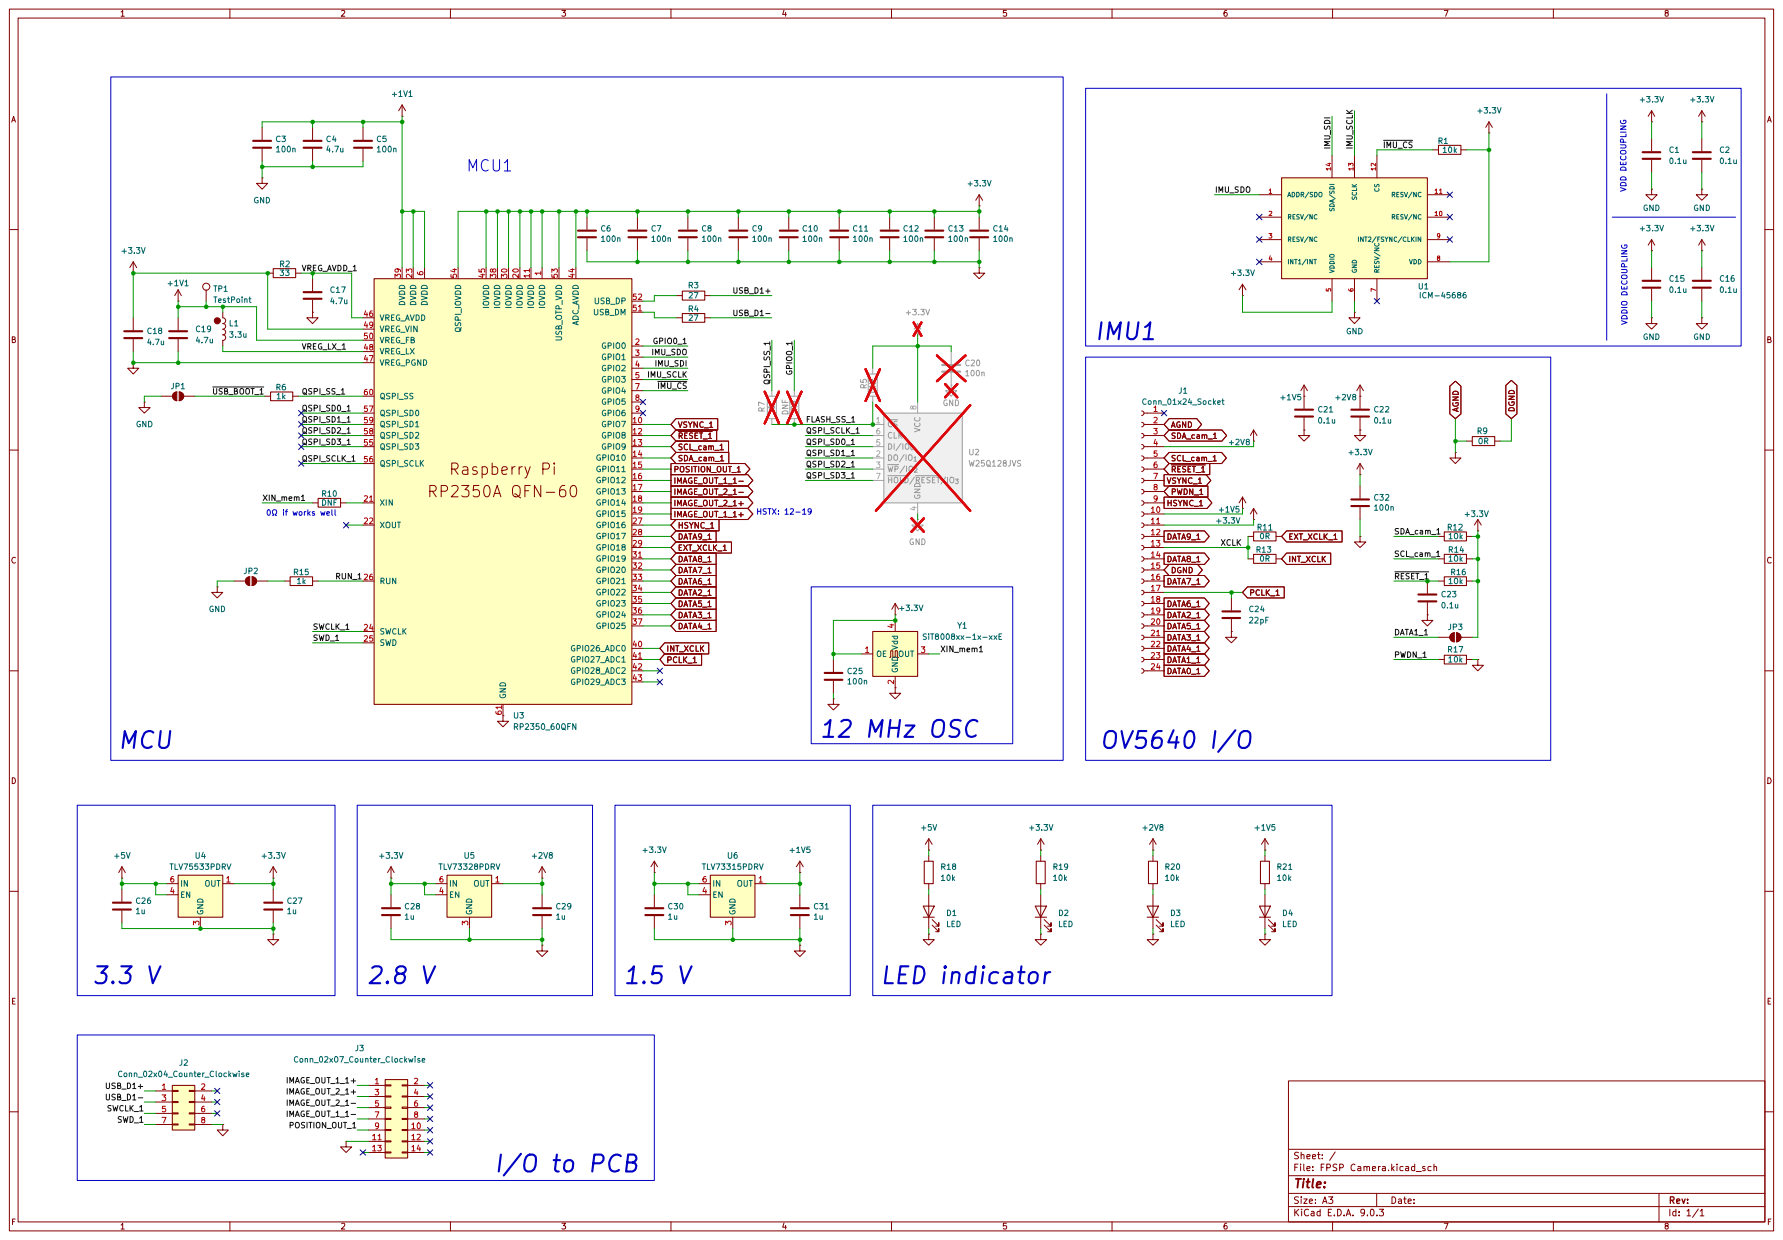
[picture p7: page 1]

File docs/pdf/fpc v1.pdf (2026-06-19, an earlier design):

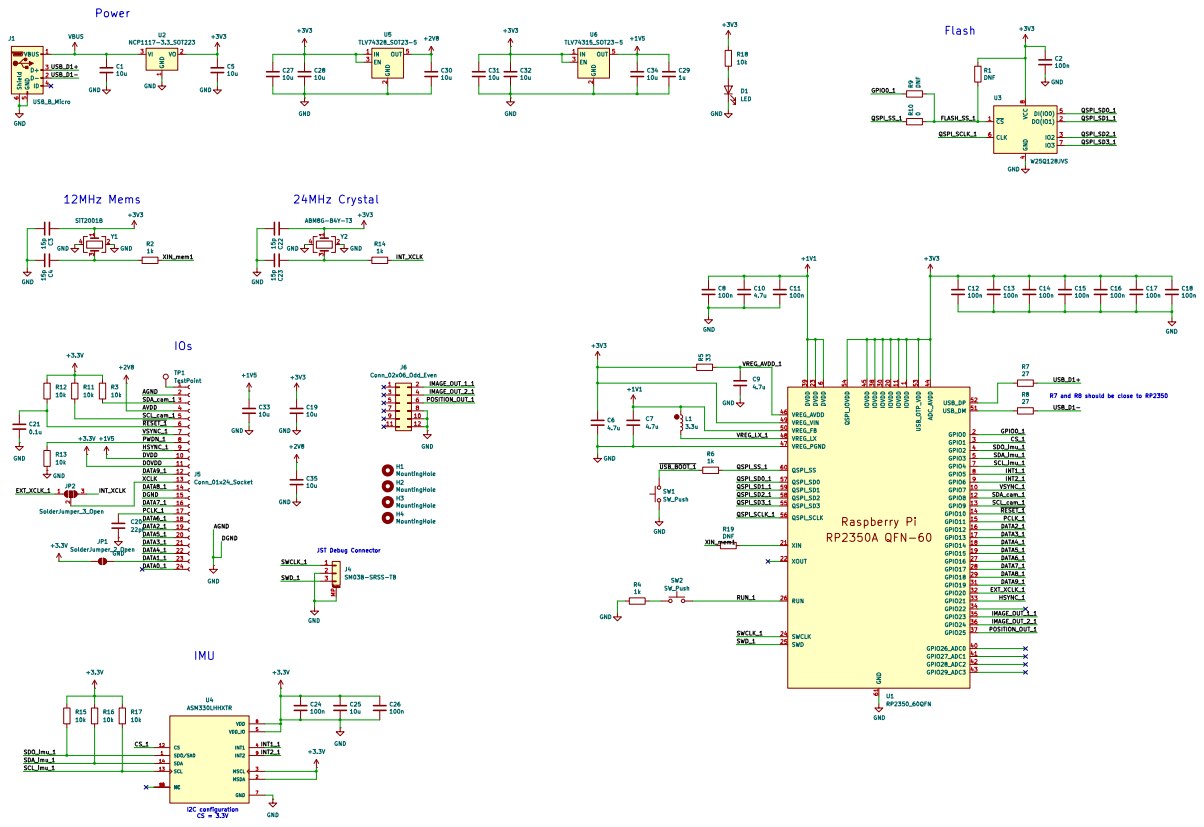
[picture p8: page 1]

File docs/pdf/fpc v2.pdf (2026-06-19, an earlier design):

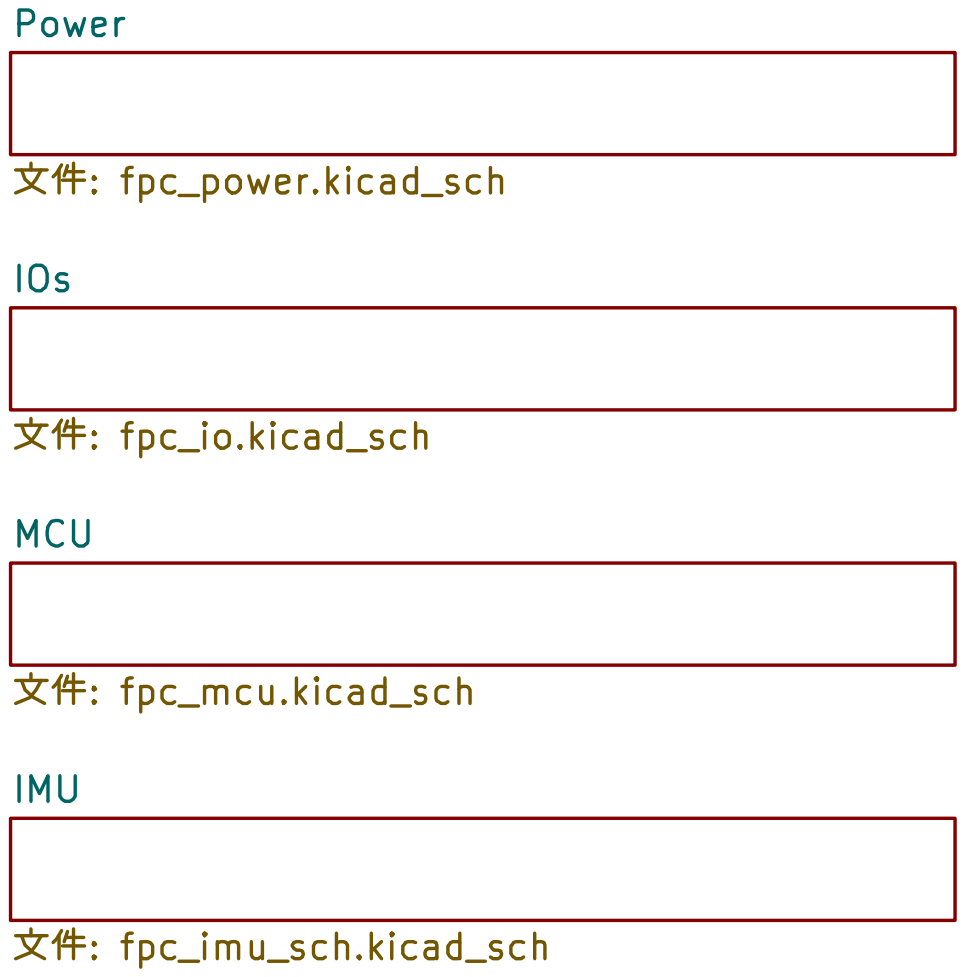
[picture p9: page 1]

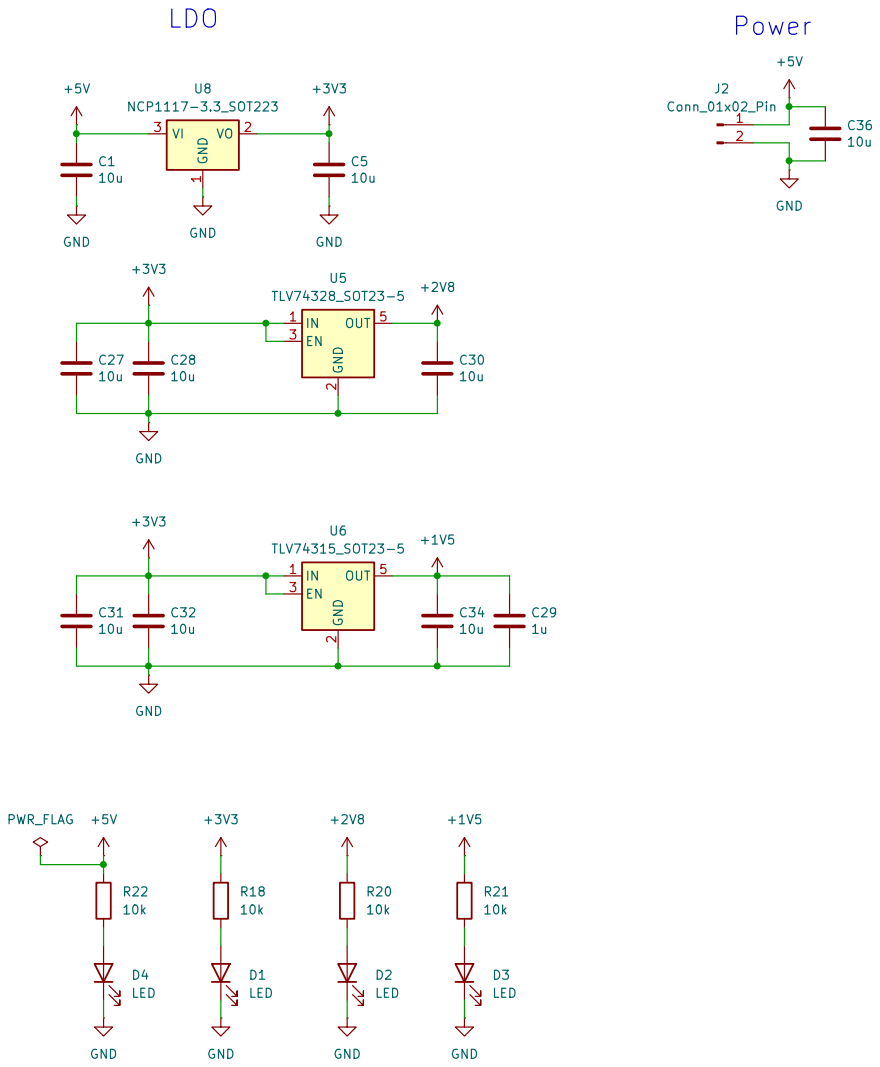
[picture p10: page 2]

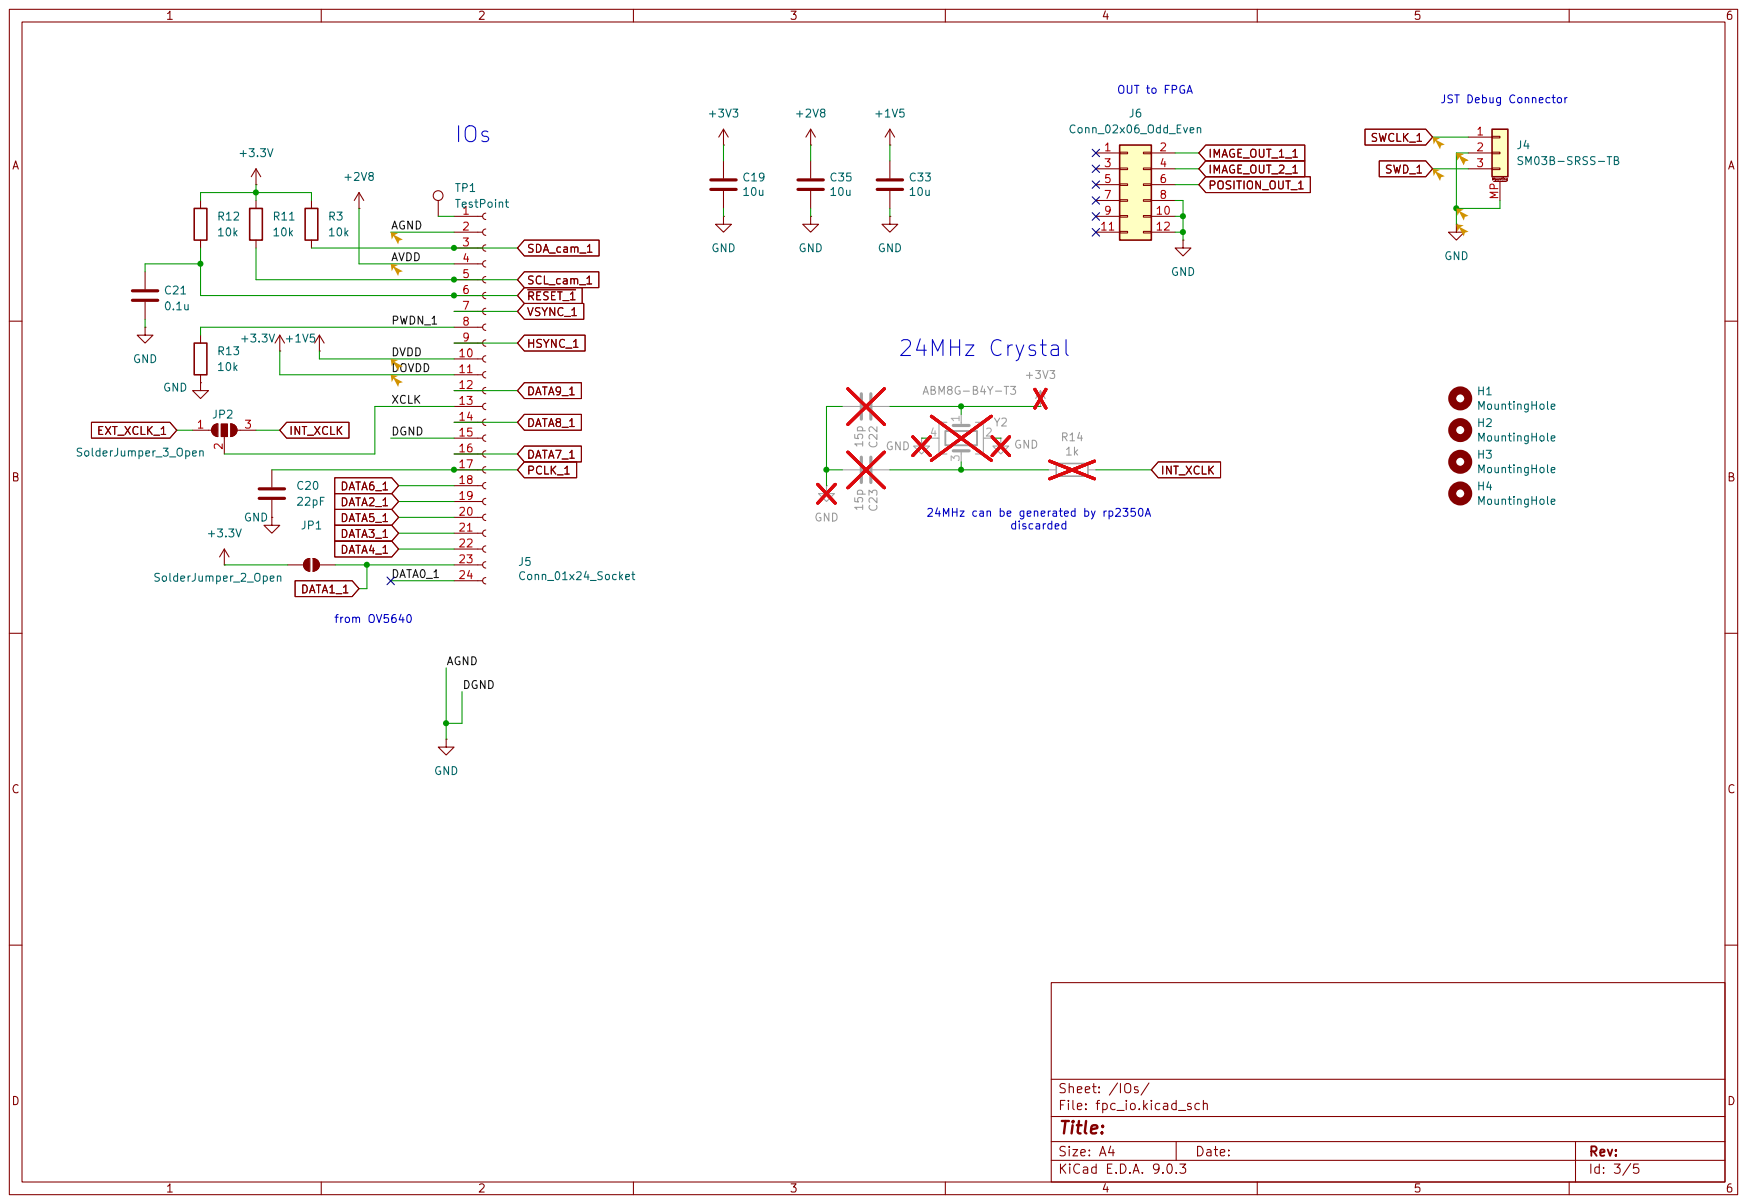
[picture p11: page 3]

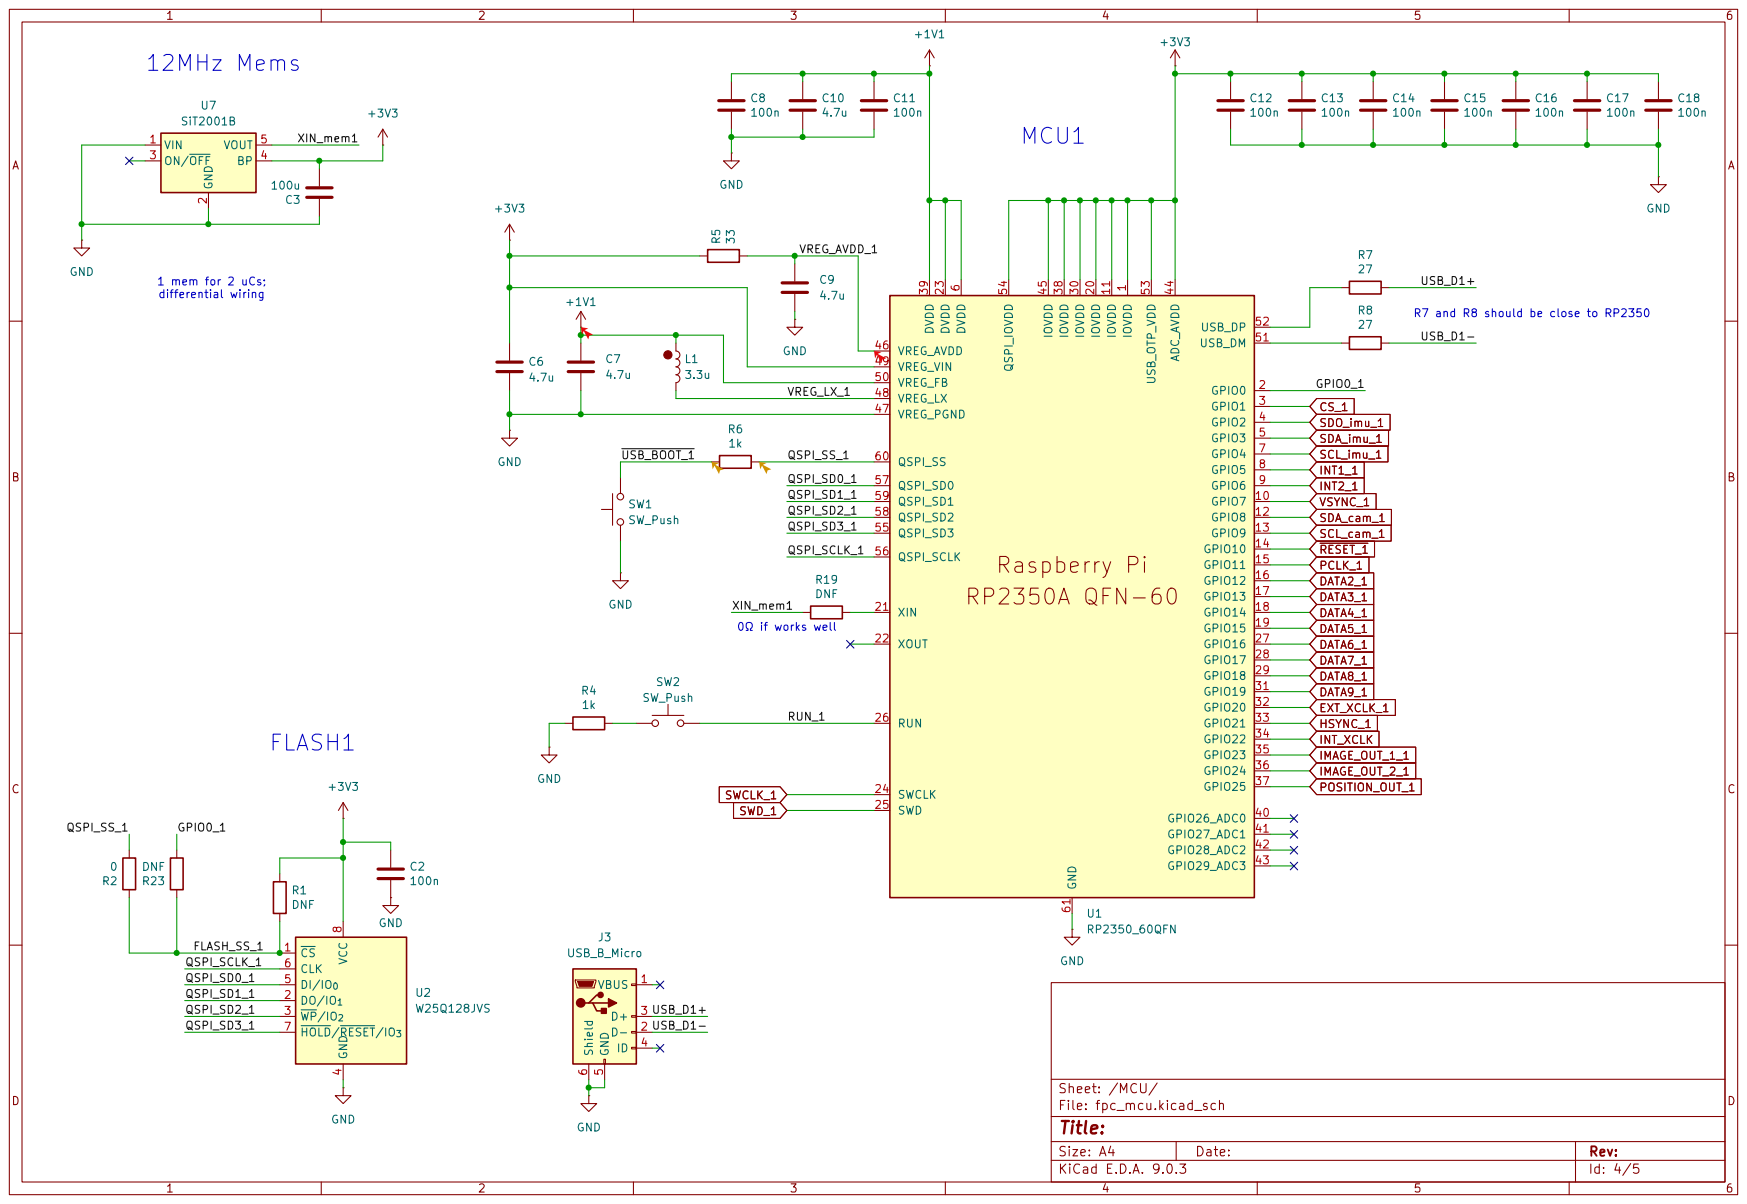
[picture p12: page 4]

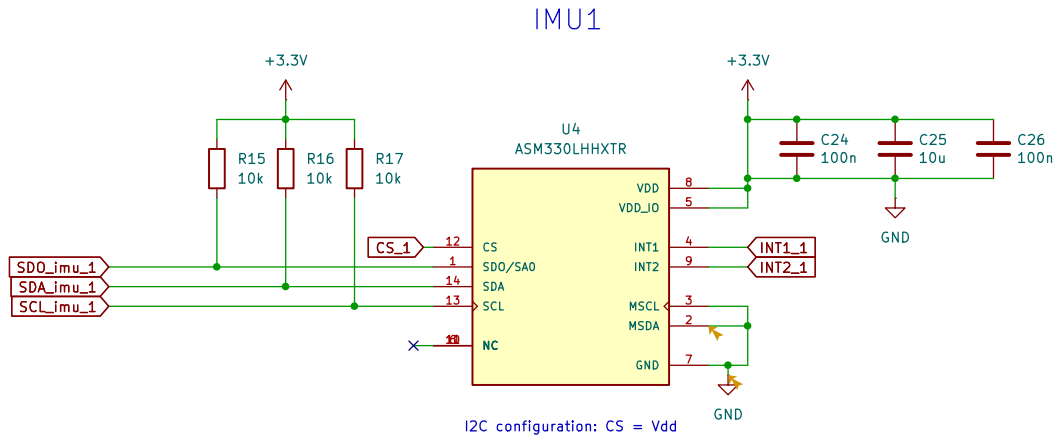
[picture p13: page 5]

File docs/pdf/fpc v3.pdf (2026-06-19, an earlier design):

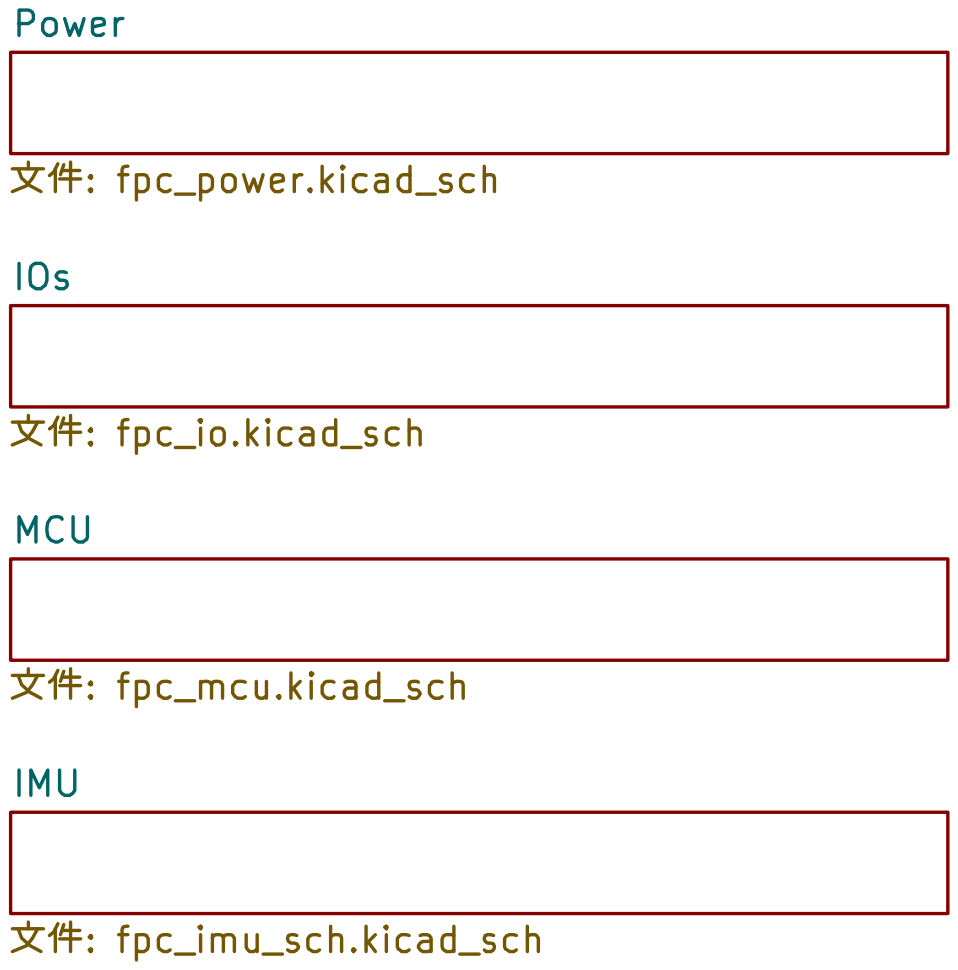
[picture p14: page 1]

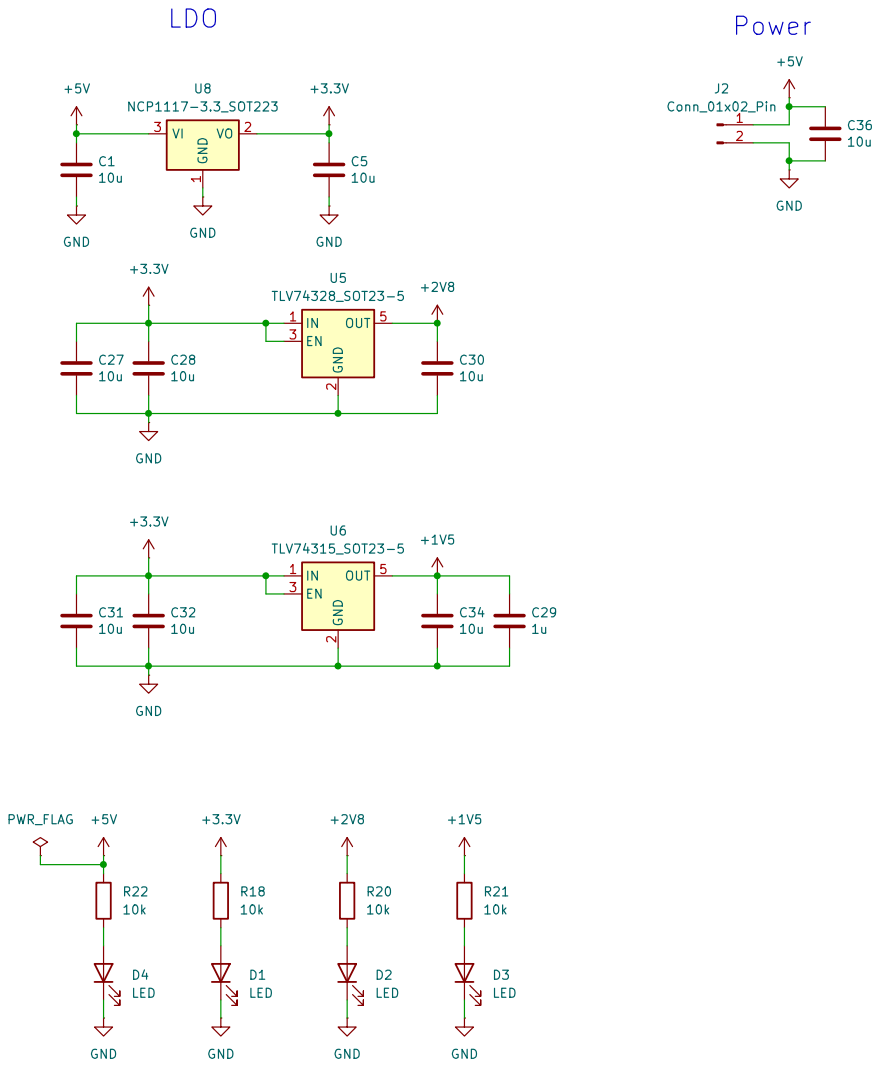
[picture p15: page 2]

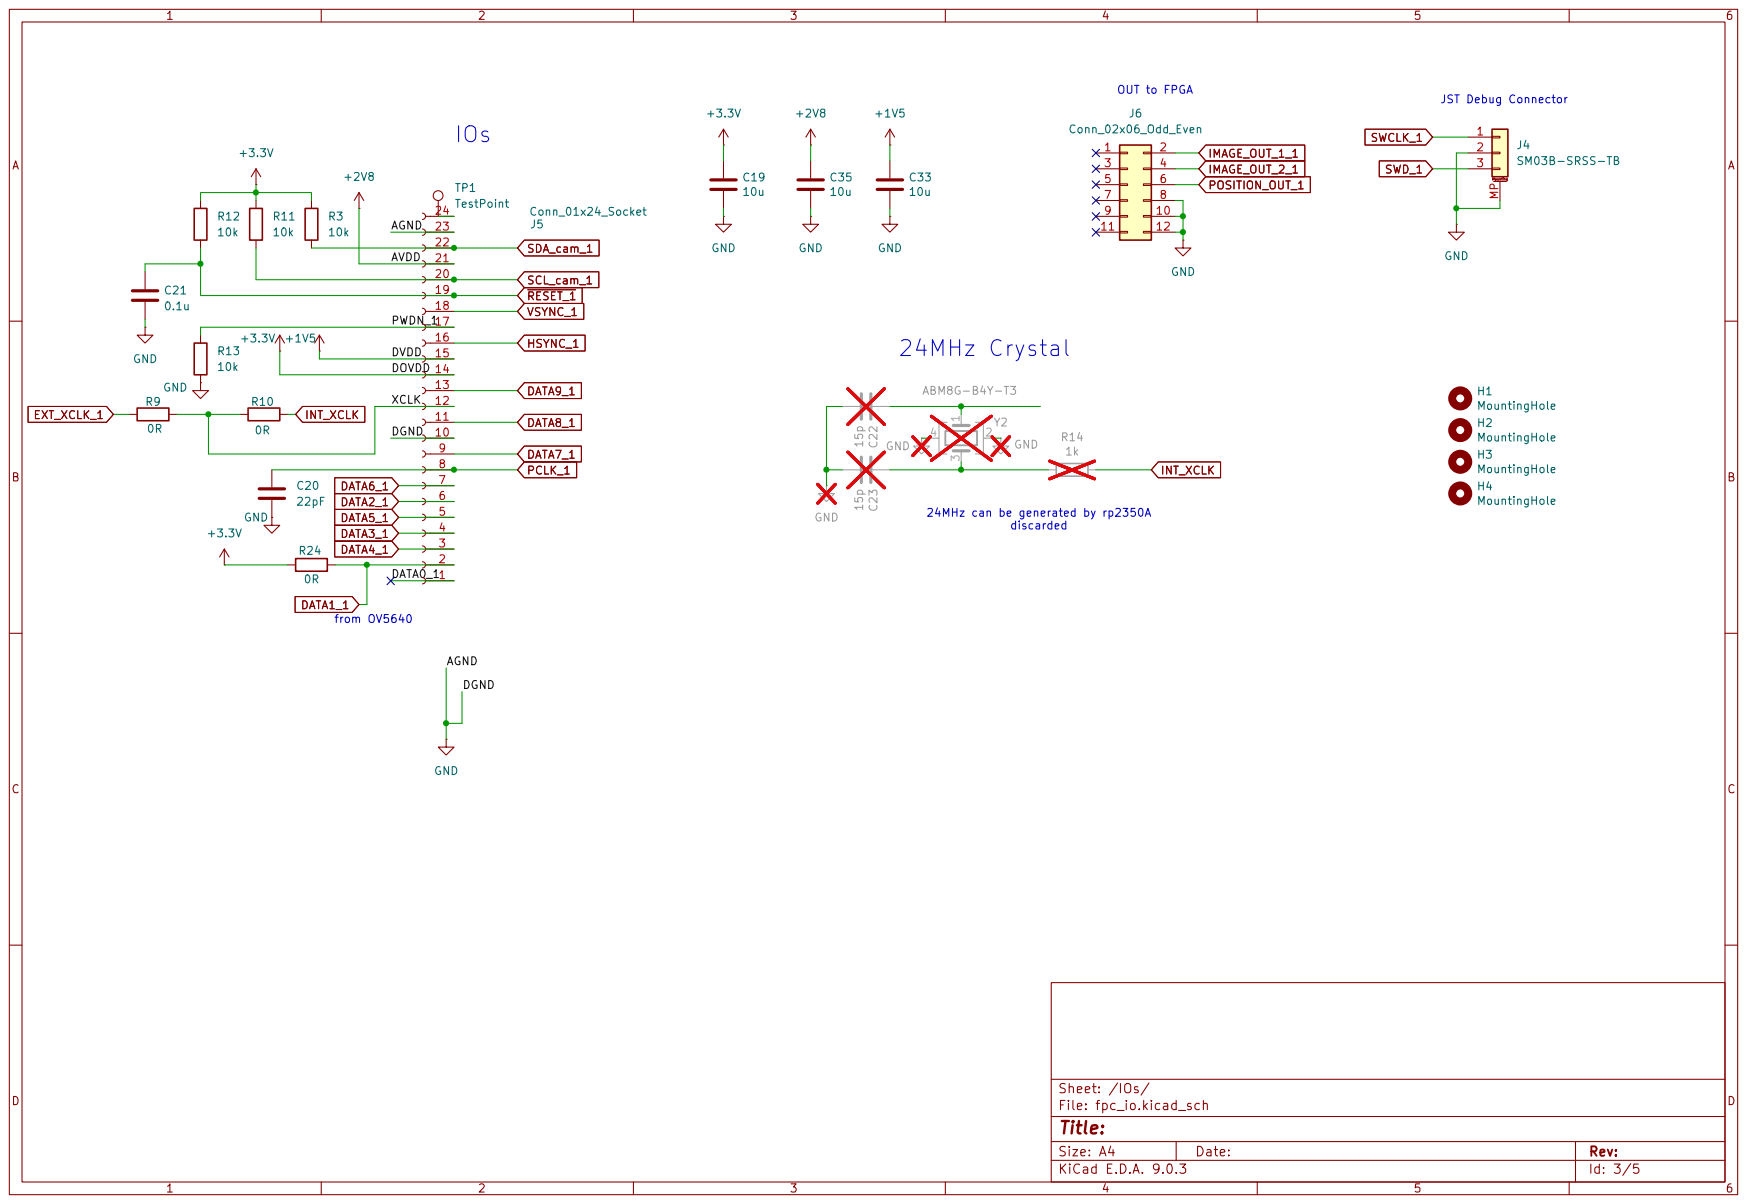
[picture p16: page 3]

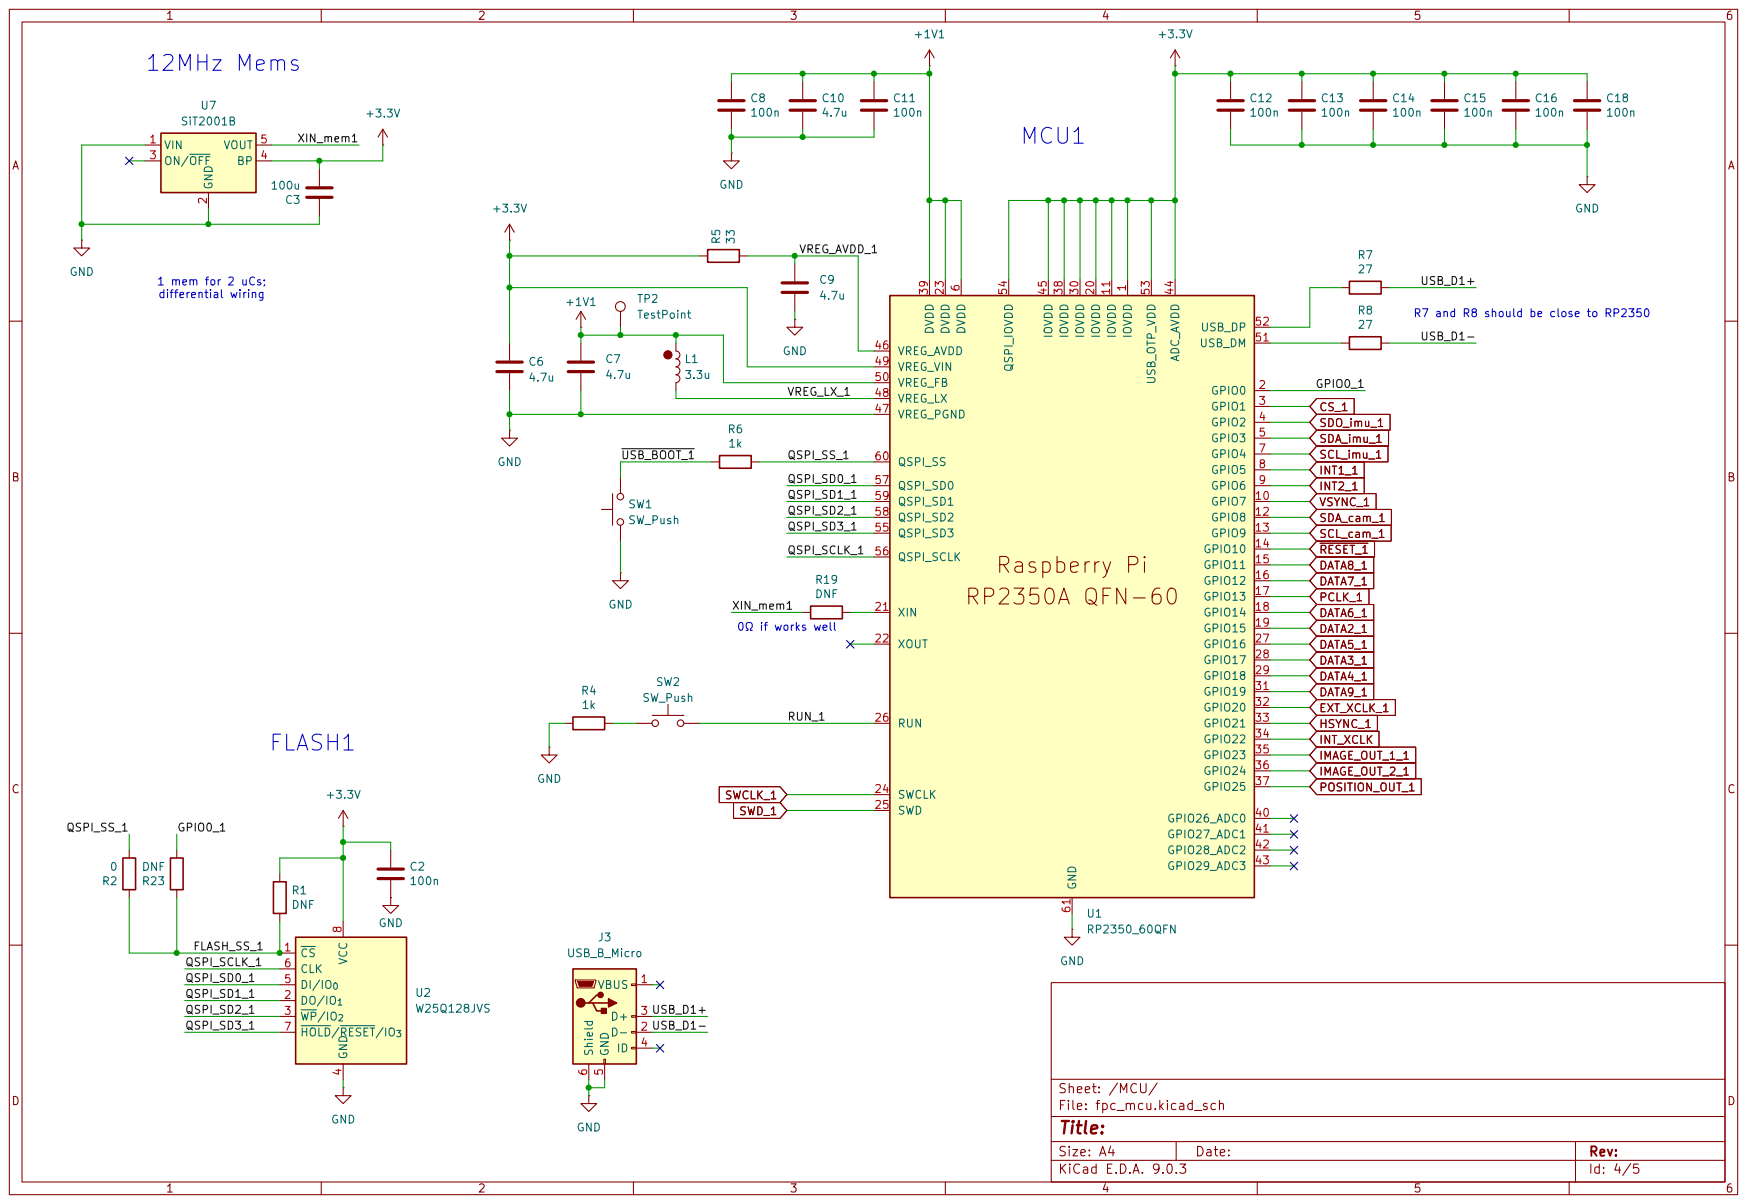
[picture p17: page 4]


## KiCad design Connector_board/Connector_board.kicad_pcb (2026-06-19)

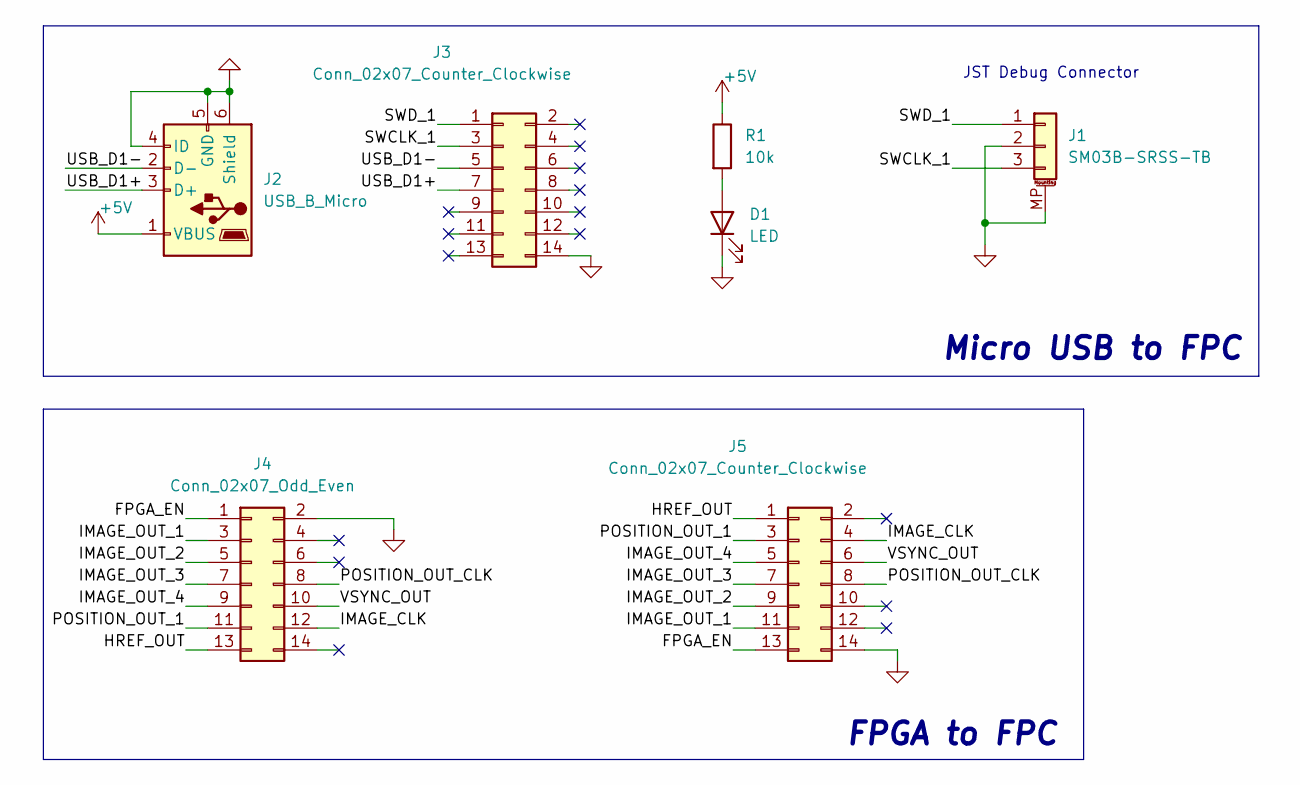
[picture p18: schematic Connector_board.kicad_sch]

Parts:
D1: LED; D_0603_1608Metric
J1: SM03B-SRSS-TB; JST_SH_SM03B-SRSS-TB_1x03-1MP_P1.00mm_Horizontal
J2: USB_B_Micro; USB_Micro-B_Molex_47346-0001
J3, J5: Conn_02x07_Counter_Clockwise; Molex_SlimStack_502430-1410_2x07_P0.40mm_Vertical
J4: Conn_02x07_Odd_Even; PinHeader_2x07_P2.54mm_Vertical
R1: 10k; R_0603_1608Metric_Pad0.98x0.95mm_HandSolder

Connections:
+5V: J2.1 (VBUS), R1.1
/FPGA_EN: J4.1, J5.13
/HREF_OUT: J4.13, J5.1
/IMAGE_CLK: J4.12, J5.4
/IMAGE_OUT_1: J4.3, J5.11
/IMAGE_OUT_2: J4.5, J5.9
/IMAGE_OUT_3: J4.7, J5.7
/IMAGE_OUT_4: J4.9, J5.5
/POSITION_OUT_1: J4.11, J5.3
/POSITION_OUT_CLK: J4.8, J5.8
/SWCLK_1: J1.3, J3.3
/SWD_1: J1.1, J3.1
/USB_D1+: J2.3 (D+), J3.7
/USB_D1-: J2.2 (D-), J3.5
/VSYNC_OUT: J4.10, J5.6
GND: D1.1 (K), J1.2, J1.MP (MountPin), J2.4 (ID), J2.5 (GND), J2.6 (Shield), J3.14, J3.15, J4.2, J5.14, J5.15
unnamed: D1.2 (A), R1.2

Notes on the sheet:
FPGA to FPC
Micro USB to FPC
JST Debug Connector

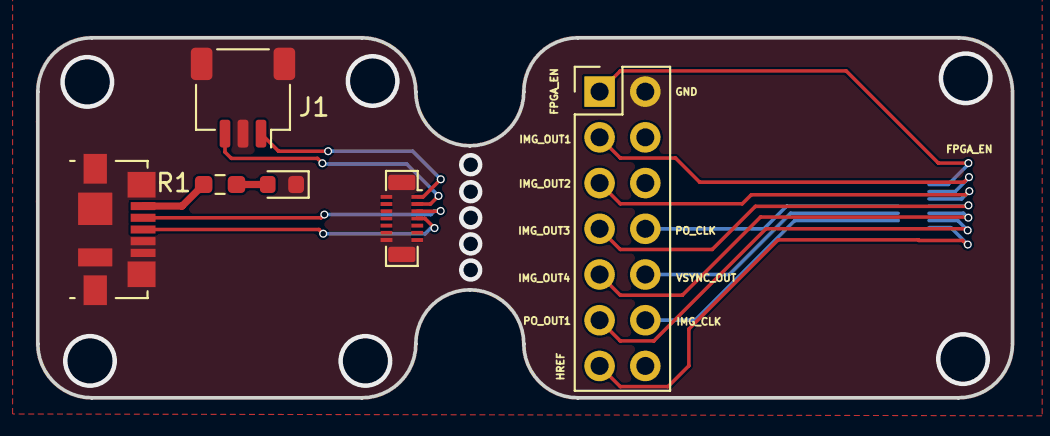
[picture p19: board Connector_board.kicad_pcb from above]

Board: 2 copper layers, 54.2 x 20.0 mm, 7 parts (1 on the bottom side), 17 nets.

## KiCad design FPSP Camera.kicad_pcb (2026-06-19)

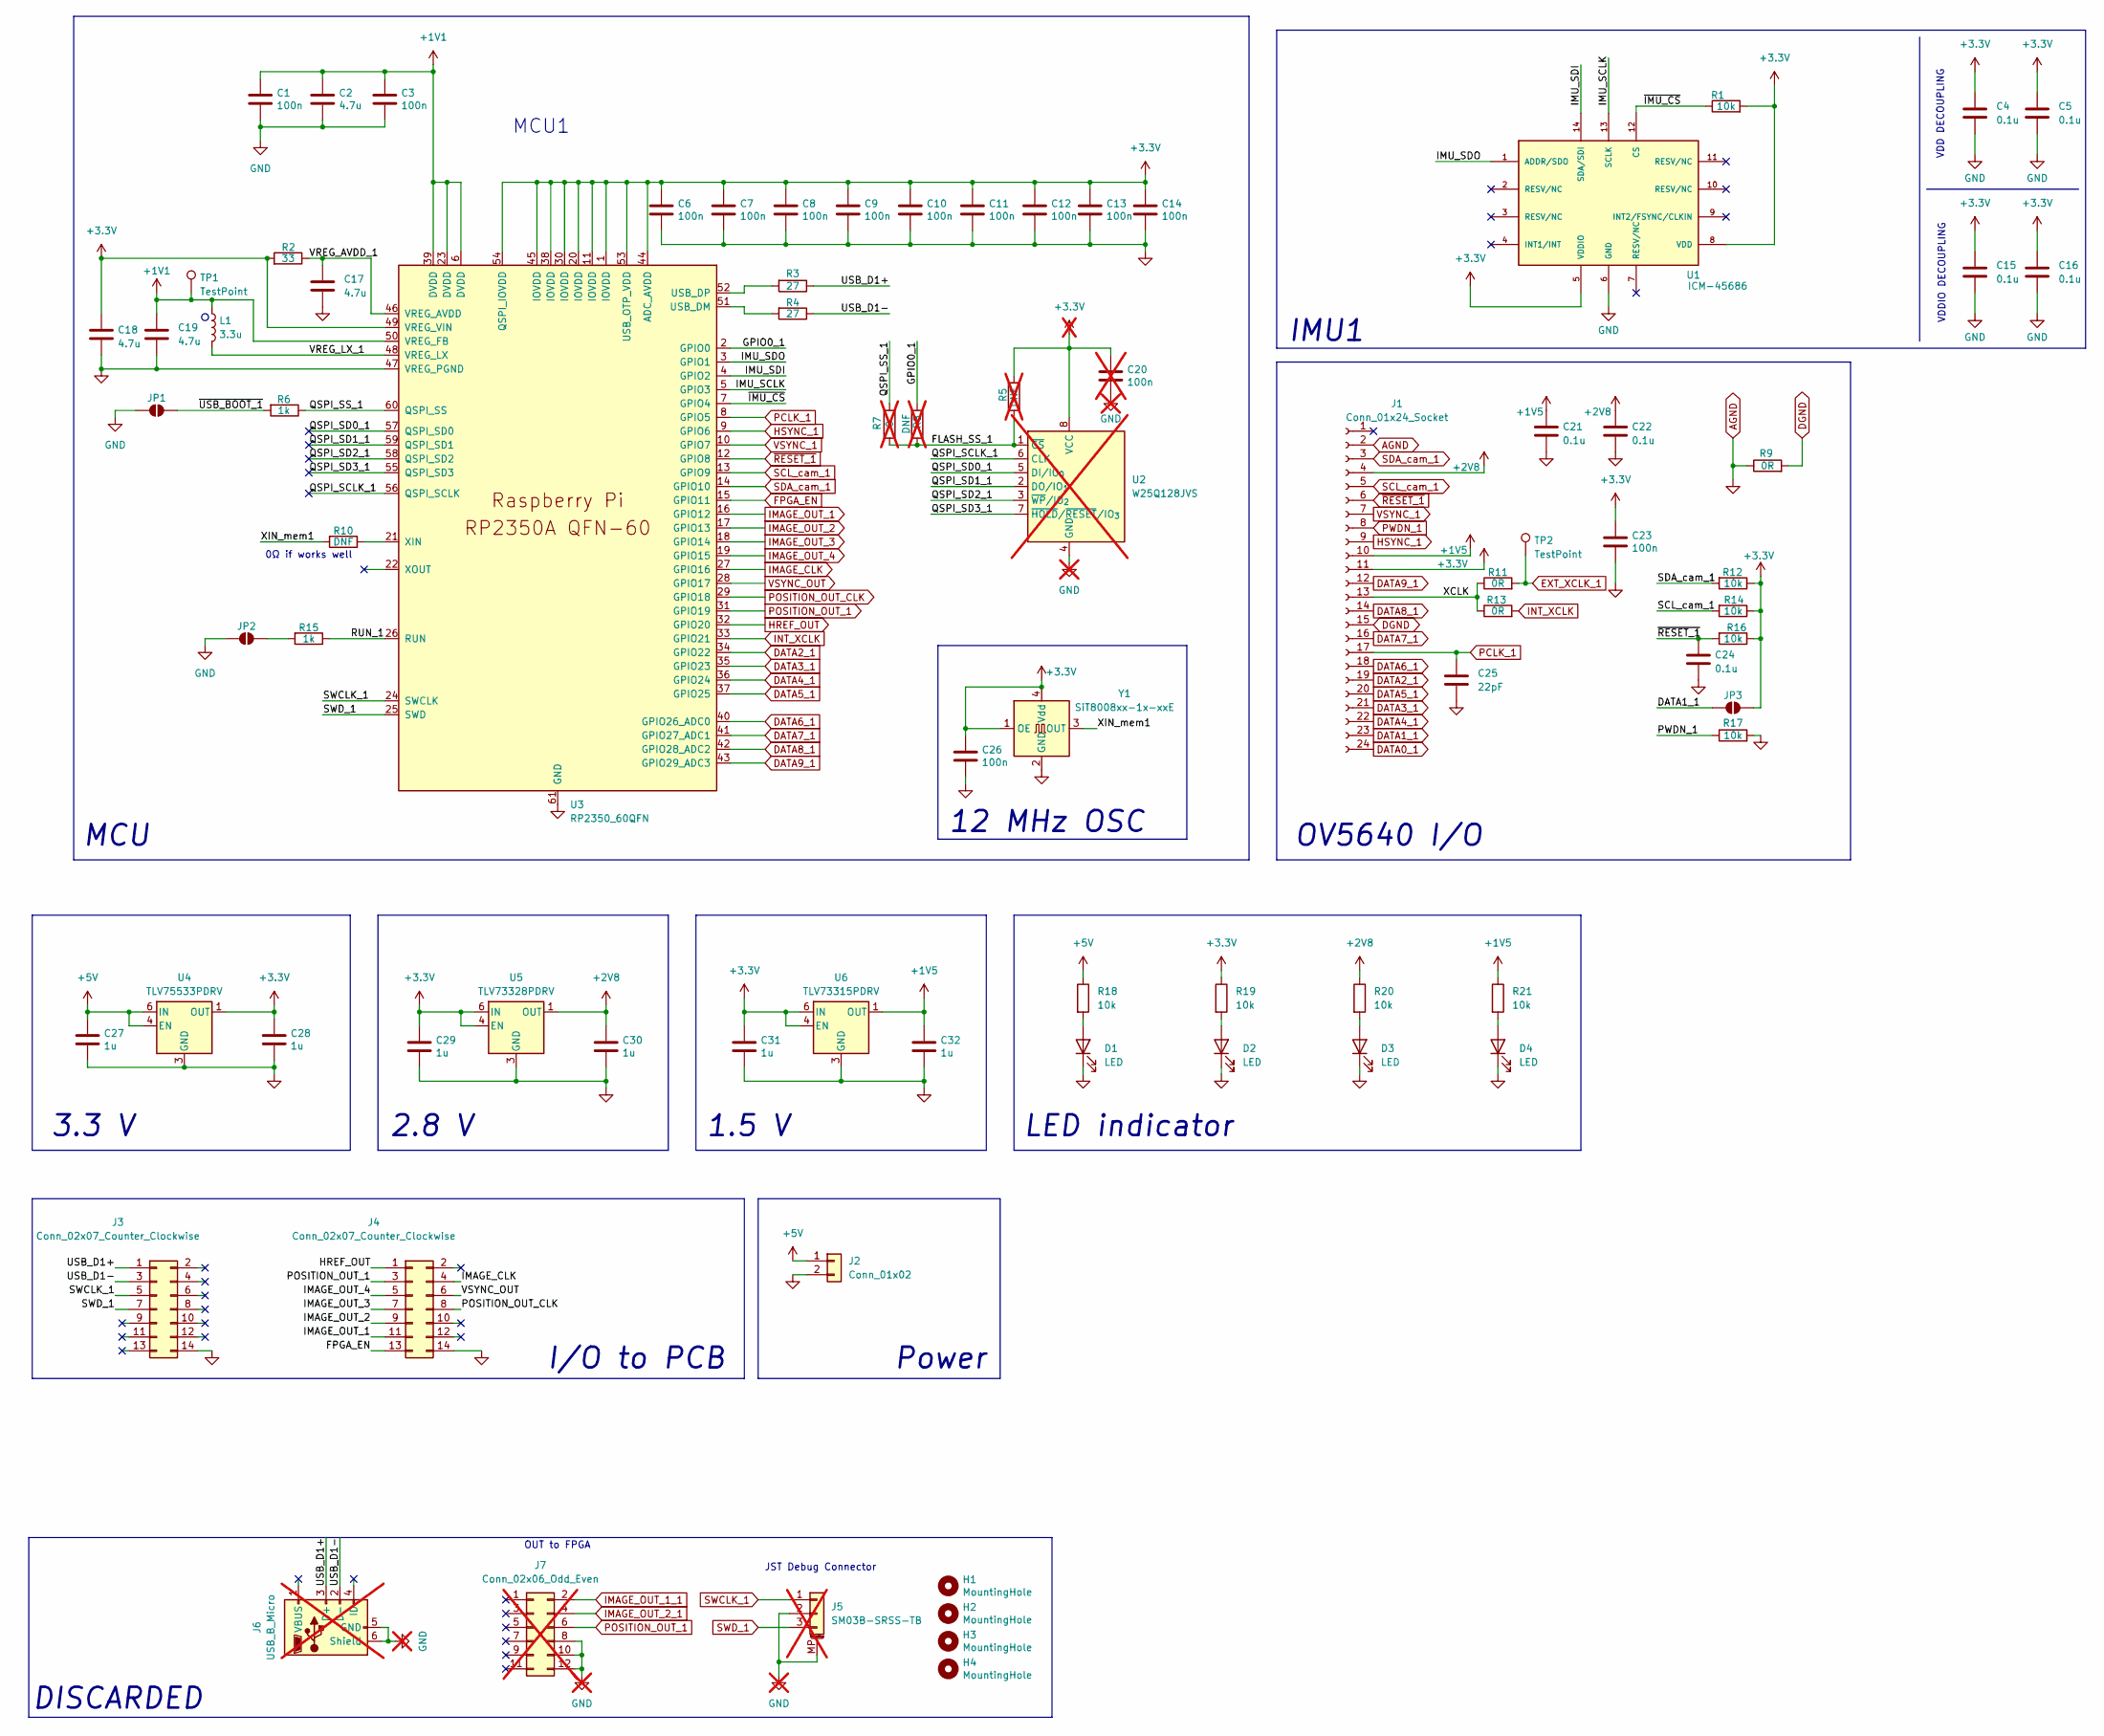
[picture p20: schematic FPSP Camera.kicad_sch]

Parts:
C1, C3, C6, C7, C8, C9, C10, C11, C12, C13, C14, C23, C26: 100n; C_0402_1005Metric
C2, C17, C18, C19: 4.7u; C_0402_1005Metric
C4, C5, C15, C16, C21, C22, C24: 0.1u; C_0402_1005Metric
C20: 100n; C_0603_1608Metric_Pad1.08x0.95mm_HandSolder; not fitted
C25: 22pF; C_0402_1005Metric
C27, C28, C29, C30, C31, C32: 1u; C_0402_1005Metric
D1, D2, D3, D4: LED; D_0603_1608Metric
H1, H2, H3, H4: MountingHole; MountingHole_2.7mm_M2.5
J1: Conn_01x24_Socket; MOLEX_52435-2471
J2: Conn_01x02; PinHeader_1x02_P2.54mm_Vertical
J3, J4: Conn_02x07_Counter_Clockwise; Molex_SlimStack_502426-1410_2x07_P0.40mm_Vertical
J5: SM03B-SRSS-TB; JST_SH_SM03B-SRSS-TB_1x03-1MP_P1.00mm_Horizontal; not fitted
J6: USB_B_Micro; USB_Micro-B_Amphenol_10103594-0001LF_Horizontal_modified; not fitted
J7: Conn_02x06_Odd_Even; PinHeader_2x06_P2.54mm_Vertical; not fitted
JP1, JP2, JP3: SolderJumper_2_Open; SolderJumper-2_P1.3mm_Open_RoundedPad1.0x1.5mm
L1: 3.3u; L_pol_2016
R1: 10k; R_0402_1005Metric_Pad0.72x0.64mm_HandSolder
R2: 33; R_0402_1005Metric
R3, R4: 27; R_0402_1005Metric
R5, R8: DNF; R_0603_1608Metric_Pad0.98x0.95mm_HandSolder; not fitted
R6, R15: 1k; R_0402_1005Metric
R7: 0; R_0603_1608Metric_Pad0.98x0.95mm_HandSolder; not fitted
R9, R11, R13: 0R; R_0402_1005Metric
R10: DNF; R_0402_1005Metric
R12, R14, R16, R17, R18, R19, R20, R21: 10k; R_0402_1005Metric
TP1, TP2: TestPoint; TestPoint_Pad_D1.0mm
U1: ICM-45686; IC_ICM-45686; PARTREV 0.2
U2: W25Q128JVS; SOIC-8_5.3x5.3mm_P1.27mm; not fitted
U3: RP2350_60QFN; RP2350-QFN-60-1EP_7x7_P0.4mm_EP3.4x3.4mm_ThermalVias
U4: TLV75533PDRV; WSON-6-1EP_2x2mm_P0.65mm_EP1x1.6mm
U5: TLV73328PDRV; WSON-6-1EP_2x2mm_P0.65mm_EP1x1.6mm
U6: TLV73315PDRV; WSON-6-1EP_2x2mm_P0.65mm_EP1x1.6mm
Y1: SiT8008xx-1x-xxE; Oscillator_SMD_SiT_PQFN-4Pin_2.5x2.0mm

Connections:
+1V1: C1.1, C2.1, C3.1, C19.1, L1.1, TP1.1 (1_1), U3.6 (DVDD), U3.23 (DVDD), U3.39 (DVDD), U3.50 (VREG_FB)
+1V5: C21.1, C32.1, J1.10, R21.1, U6.1 (OUT)
+2V8: C22.1, C30.1, J1.4, R20.1, U5.1 (OUT)
+3.3V: C4.1, C5.1, C6.1, C7.1, C8.1, C9.1, C10.1, C11.1, C12.1, C13.1, C14.1, C15.1, C16.1, C18.1, C20.1, C23.1, C26.1, C28.1, C29.1, C31.1, J1.11, JP3.2 (B), R1.2, R2.2, R5.1, R12.1, R14.1, R16.1, R19.1, U1.5 (VDDIO), U1.8 (VDD), U2.8 (VCC), U3.1 (IOVDD), U3.11 (IOVDD), U3.20 (IOVDD), U3.30 (IOVDD), U3.38 (IOVDD), U3.44 (ADC_AVDD), U3.45 (IOVDD), U3.49 (VREG_VIN), U3.53 (USB_OTP_VDD), U3.54 (QSPI_IOVDD), U4.1 (OUT), U5.4 (EN), U5.6 (IN), U6.4 (EN), U6.6 (IN), Y1.1 (OE), Y1.4 (Vdd)
+5V: C27.1, J2.1, R18.1, U4.4 (EN), U4.6 (IN)
/GPIO0_1: R8.2, U3.2 (GPIO0)
/IMU_SCLK: U1.13 (SCLK), U3.5 (GPIO3)
/IMU_SDI: U1.14 (SDA/SDI), U3.4 (GPIO2)
/IMU_SDO: U1.1 (ADDR/SDO), U3.3 (GPIO1)
/QSPI_SCLK_1: U2.6 (CLK), U3.56 (QSPI_SCLK)
/QSPI_SD0_1: U2.5 (DI/IO_{0}), U3.57 (QSPI_SD0)
/QSPI_SD1_1: U2.2 (DO/IO_{1}), U3.59 (QSPI_SD1)
/QSPI_SD2_1: U2.3 (~WP/IO_{2}), U3.58 (QSPI_SD2)
/QSPI_SD3_1: U2.7 (~HOLD/~RESET/IO_{3}), U3.55 (QSPI_SD3)
/QSPI_SS_1: R6.1, R7.2, U3.60 (QSPI_SS)
/RUN_1: R15.1, U3.26 (RUN)
/USB_D1+: J3.1, J6.3 (D+), R3.1
/USB_D1-: J3.3, J6.2 (D-), R4.1
/VREG_AVDD_1: C17.1, R2.1, U3.46 (VREG_AVDD)
/VREG_LX_1: L1.2, U3.48 (VREG_LX)
/XCLK: J1.13, R11.1, R13.1
/XIN_mem1: R10.2, Y1.3 (OUT)
/~IMU_CS: R1.1, U1.12 (CS), U3.7 (GPIO4)
/~USB_BOOT_1: JP1.2 (B), R6.2
AGND: C1.2, C2.2, C3.2, C4.2, C5.2, C6.2, C7.2, C8.2, C9.2, C10.2, C11.2, C12.2, C13.2, C14.2, C15.2, C16.2, C17.2, C18.2, C19.2, C20.2, C21.2, C22.2, C23.2, C24.2, C25.2, C26.2, C27.2, C28.2, C29.2, C30.2, C31.2, C32.2, D1.1 (K), D2.1 (K), D3.1 (K), D4.1 (K), J1.2, J1.MP, J2.2, J3.14, J3.15, J3.16, J4.14, J4.15, J4.16, J5.2, J5.MP (MountPin), J6.5 (GND), J6.6 (Shield), J7.8, J7.10, J7.12, JP1.1 (A), JP2.1 (A), R9.1, R17.2, U1.6 (GND), U2.4 (GND), U3.47 (VREG_PGND), U3.61 (GND), U4.3 (GND), U4.7 (GND), U5.3 (GND), U5.7 (GND), U6.3 (GND), U6.7 (GND), Y1.2 (GND)
DATA0_1: J1.24
DATA1_1: J1.23, JP3.1 (A)
DATA2_1: J1.19, U3.34 (GPIO22)
DATA3_1: J1.21, U3.35 (GPIO23)
DATA4_1: J1.22, U3.36 (GPIO24)
DATA5_1: J1.20, U3.37 (GPIO25)
DATA6_1: J1.18, U3.40 (GPIO26_ADC0)
DATA7_1: J1.16, U3.41 (GPIO27_ADC1)
DATA8_1: J1.14, U3.42 (GPIO28_ADC2)
DATA9_1: J1.12, U3.43 (GPIO29_ADC3)
DGND: J1.15, R9.2
EXT_XCLK_1: R11.2, TP2.1 (1_1)
FPGA_EN: J4.13, U3.15 (GPIO11)
HREF_OUT: J4.1, U3.32 (GPIO20)
HSYNC_1: J1.9, U3.9 (GPIO6)
IMAGE_CLK: J4.4, U3.27 (GPIO16)
IMAGE_OUT_1: J4.11, U3.16 (GPIO12)
IMAGE_OUT_2: J4.9, U3.17 (GPIO13)
IMAGE_OUT_3: J4.7, U3.18 (GPIO14)
IMAGE_OUT_4: J4.5, U3.19 (GPIO15)
INT_XCLK: R13.2, U3.33 (GPIO21)
unnamed: D1.2 (A), R18.2
unnamed: D2.2 (A), R19.2
unnamed: D3.2 (A), R20.2
unnamed: D4.2 (A), R21.2
unnamed: JP2.2 (B), R15.2
unnamed: R5.2, R7.1, R8.1, U2.1 (~CS)
unnamed: R4.2, U3.51 (USB_DM)
unnamed: R3.2, U3.52 (USB_DP)
unnamed: R10.1, U3.21 (XIN)
PCLK_1: C25.1, J1.17, U3.8 (GPIO5)
POSITION_OUT_1: J4.3, J7.6, U3.31 (GPIO19)
POSITION_OUT_CLK: J4.8, U3.29 (GPIO18)
PWDN_1: J1.8, R17.1
SCL_cam_1: J1.5, R14.2, U3.13 (GPIO9)
SDA_cam_1: J1.3, R12.2, U3.14 (GPIO10)
SWCLK_1: J3.5, U3.24 (SWCLK)
SWD_1: J3.7, U3.25 (SWD)
VSYNC_1: J1.7, U3.10 (GPIO7)
VSYNC_OUT: J4.6, U3.28 (GPIO17)
~RESET_1: C24.1, J1.6, R16.2, U3.12 (GPIO8)

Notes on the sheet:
I/O to PCB
0Ω if works well
IMU1
3.3 V
MCU
MCU1
12 MHz OSC
Power
2.8 V
VDD DECOUPLING
LED indicator
1.5 V
VDDIO DECOUPLING
OV5640 I/O
DISCARDED
JST Debug Connector
OUT to FPGA

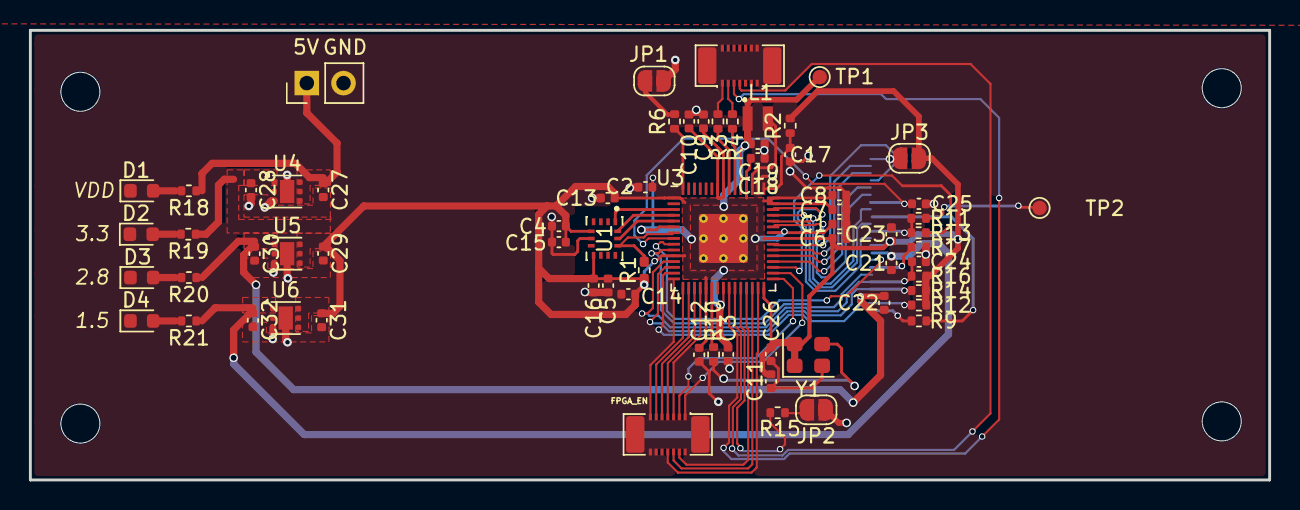
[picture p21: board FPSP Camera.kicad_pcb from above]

Board: 4 copper layers, 85.7 x 31.1 mm, 73 parts (1 on the bottom side), 58 nets.

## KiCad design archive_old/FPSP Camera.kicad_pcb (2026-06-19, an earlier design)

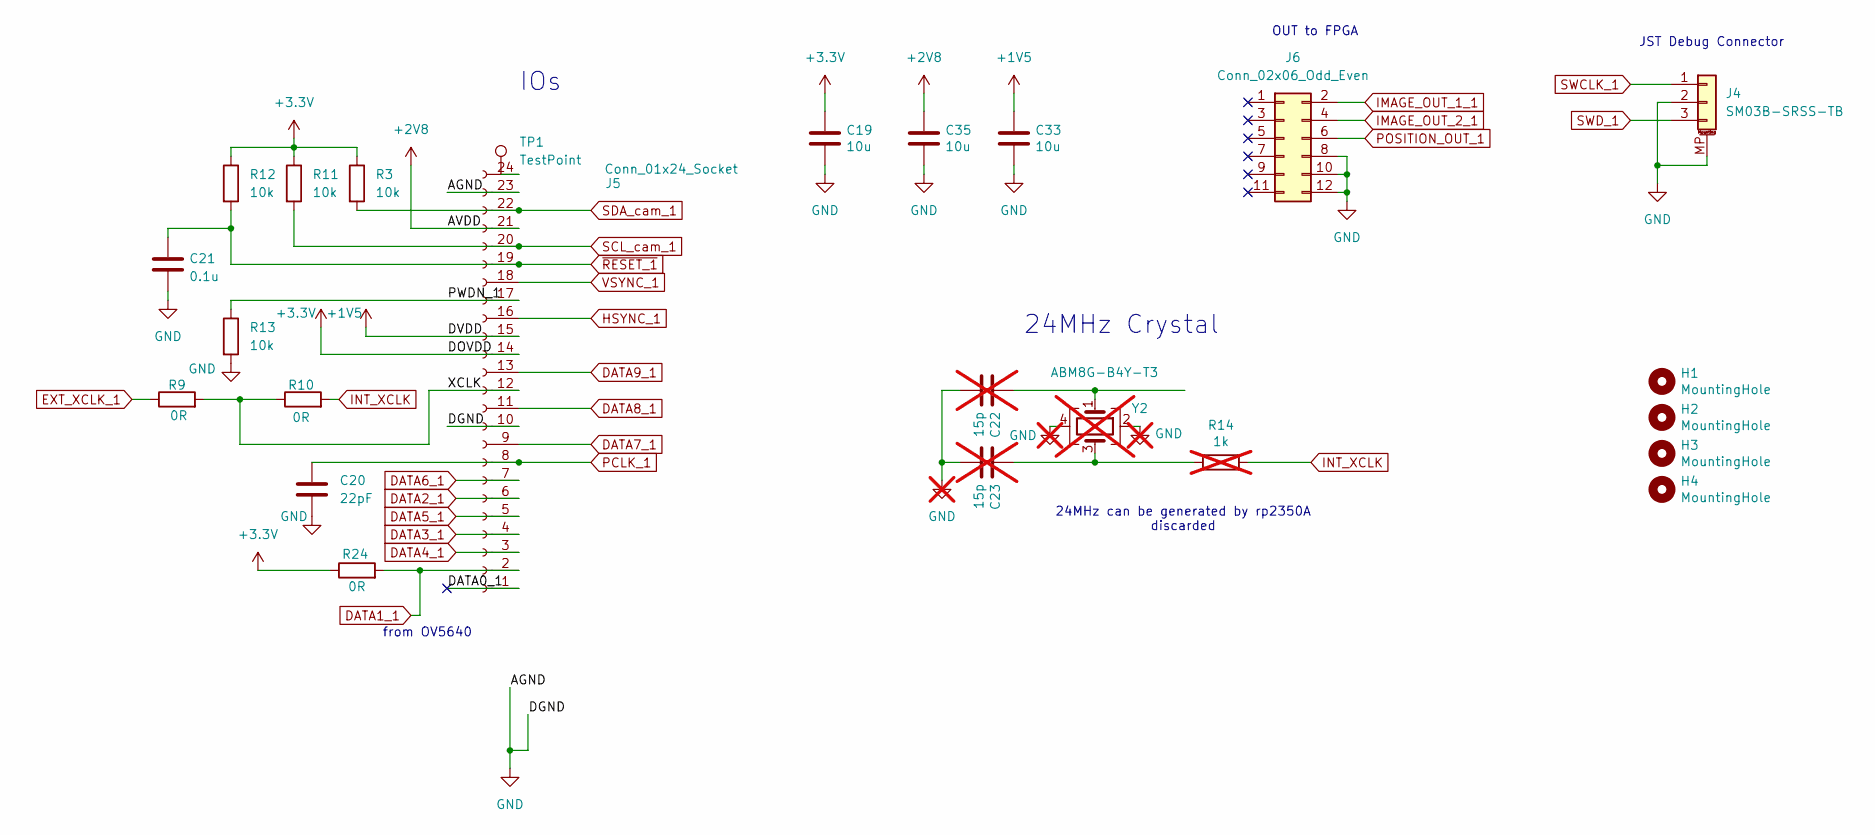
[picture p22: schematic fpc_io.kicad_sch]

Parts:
C19, C33, C35: 10u; C_0603_1608Metric_Pad1.08x0.95mm_HandSolder
C20: 22pF; C_0603_1608Metric_Pad1.08x0.95mm_HandSolder
C21: 0.1u; C_0603_1608Metric_Pad1.08x0.95mm_HandSolder
C22, C23: 15p; C_0603_1608Metric_Pad1.08x0.95mm_HandSolder; not fitted
H1, H2, H3, H4: MountingHole; MountingHole_2.7mm_M2.5
J4: SM03B-SRSS-TB; JST_SH_SM03B-SRSS-TB_1x03-1MP_P1.00mm_Horizontal
J5: Conn_01x24_Socket; TE_2-84952-4_1x24-1MP_P1.0mm_Horizontal
J6: Conn_02x06_Odd_Even; PinHeader_2x06_P2.54mm_Vertical
R3, R11, R12, R13: 10k; R_0603_1608Metric_Pad0.98x0.95mm_HandSolder
R9, R10, R24: 0R; R_0603_1608Metric_Pad0.98x0.95mm_HandSolder
R14: 1k; R_0603_1608Metric_Pad0.98x0.95mm_HandSolder; not fitted
TP1: TestPoint; TestPoint_Pad_D1.0mm
Y2: ABM8G-B4Y-T3; Crystal_SMD_3225-4Pin_3.2x2.5mm; not fitted

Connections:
+1V5: C33.1, J5.15; also elsewhere on the board
+2V8: C35.1, J5.21; also elsewhere on the board
+3.3V: C19.1, J5.14, R3.1, R11.1, R12.1, R24.1; also elsewhere on the board
/IOs/DATA0_1: J5.1
/IOs/PWDN_1: J5.17, R13.1
/IOs/XCLK: J5.12, R9.2, R10.1
DATA1_1: J5.2, R24.2
DATA2_1: J5.6; also elsewhere on the board
DATA3_1: J5.4; also elsewhere on the board
DATA4_1: J5.3; also elsewhere on the board
DATA5_1: J5.5; also elsewhere on the board
DATA6_1: J5.7; also elsewhere on the board
DATA7_1: J5.9; also elsewhere on the board
DATA8_1: J5.11; also elsewhere on the board
DATA9_1: J5.13; also elsewhere on the board
EXT_XCLK_1: R9.1; also elsewhere on the board
GND: C19.2, C20.2, C21.2, C22.2, C23.2, C33.2, C35.2, J4.2, J4.MP (MountPin), J5.10, J5.23, J6.8, J6.10, J6.12, R13.2, Y2.2, Y2.4; also elsewhere on the board
HSYNC_1: J5.16; also elsewhere on the board
IMAGE_OUT_1_1: J6.2; also elsewhere on the board
IMAGE_OUT_2_1: J6.4; also elsewhere on the board
INT_XCLK: R10.2, R14.1; also elsewhere on the board
unnamed: C22.1, Y2.1
unnamed: C23.1, R14.2, Y2.3
unnamed: J5.24, TP1.1
PCLK_1: C20.1, J5.8; also elsewhere on the board
POSITION_OUT_1: J6.6; also elsewhere on the board
SCL_cam_1: J5.20, R11.2; also elsewhere on the board
SDA_cam_1: J5.22, R3.2; also elsewhere on the board
SWCLK_1: J4.1; also elsewhere on the board
SWD_1: J4.3; also elsewhere on the board
VSYNC_1: J5.18; also elsewhere on the board
~RESET_1: C21.1, J5.19, R12.2; also elsewhere on the board

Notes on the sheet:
from OV5640
24MHz Crystal
24MHz can be generated by rp2350A discarded
OUT to FPGA
IOs
JST Debug Connector

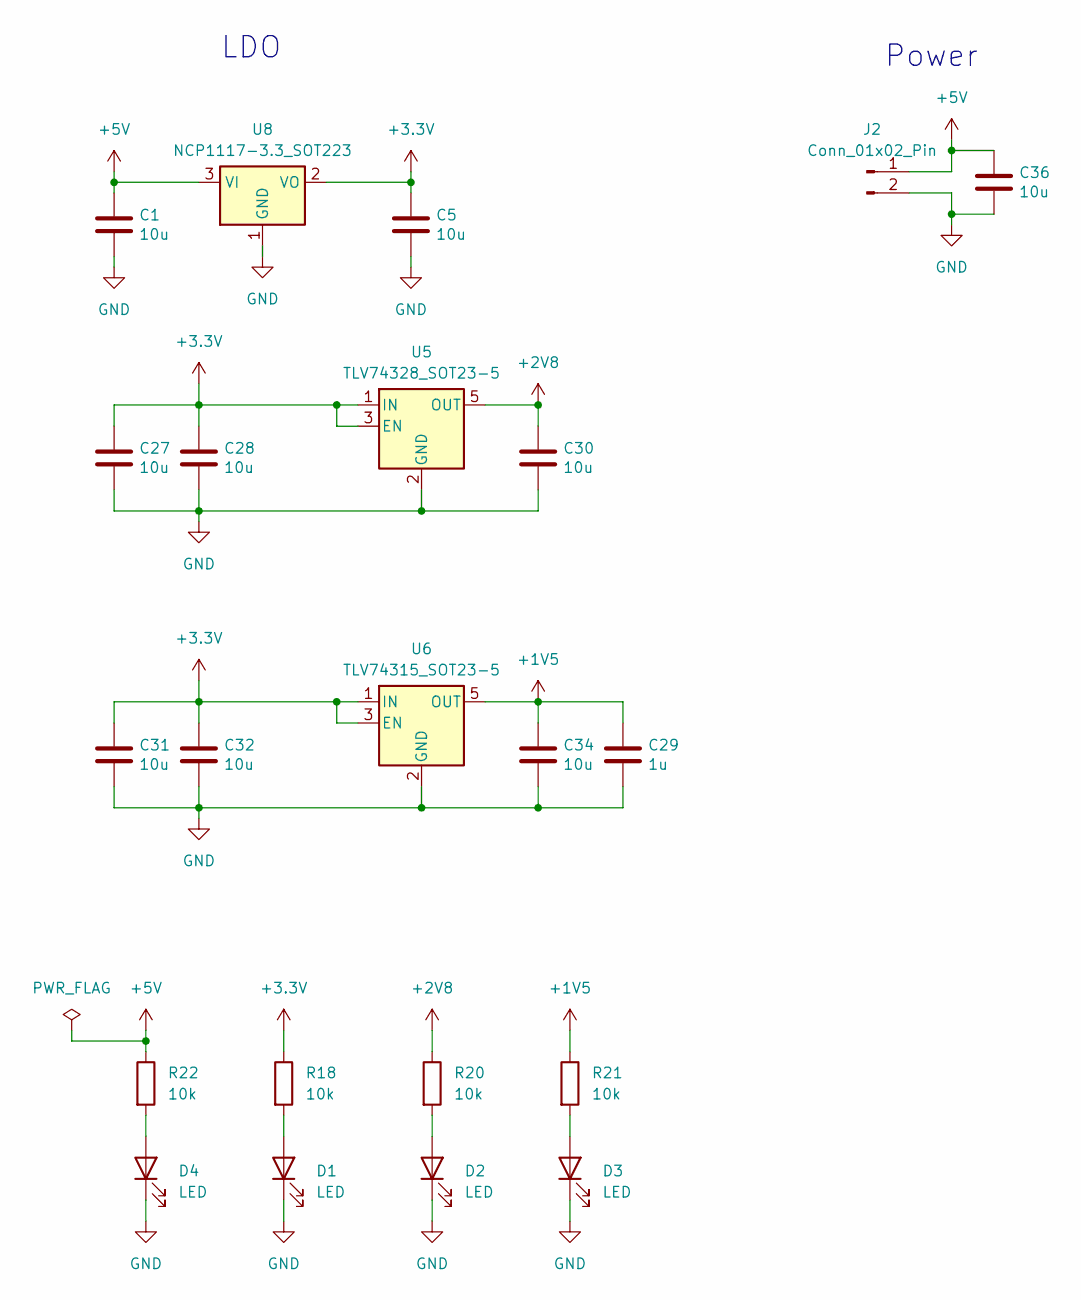
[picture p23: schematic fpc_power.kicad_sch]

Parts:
C1, C5, C27, C28, C30, C31, C32, C34: 10u; C_0603_1608Metric_Pad1.08x0.95mm_HandSolder
C29: 1u; C_0603_1608Metric_Pad1.08x0.95mm_HandSolder
C36: 10u; CP_Radial_D8.0mm_P2.50mm
D1, D2, D3, D4: LED; D_0603_1608Metric
J2: Conn_01x02_Pin; TerminalBlock_MaiXu_MX126-5.0-02P_1x02_P5.00mm
R18, R20, R21, R22: 10k; R_0603_1608Metric_Pad0.98x0.95mm_HandSolder
U5: TLV74328_SOT23-5; SOT-23-5
U6: TLV74315_SOT23-5; SOT-23-5
U8: NCP1117-3.3_SOT223; SOT-223-3_TabPin2

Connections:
+1V5: C29.1, C34.1, R21.1, U6.5 (OUT); also elsewhere on the board
+2V8: C30.1, R20.1, U5.5 (OUT); also elsewhere on the board
+3.3V: C5.1, C27.1, C28.1, C31.1, C32.1, R18.1, U5.1 (IN), U5.3 (EN), U6.1 (IN), U6.3 (EN), U8.2 (VO); also elsewhere on the board
+5V: C1.1, C36.1, J2.1, R22.1, U8.3 (VI)
GND: C1.2, C5.2, C27.2, C28.2, C29.2, C30.2, C31.2, C32.2, C34.2, C36.2, D1.1 (K), D2.1 (K), D3.1 (K), D4.1 (K), J2.2, U5.2 (GND), U6.2 (GND), U8.1 (GND); also elsewhere on the board
unnamed: D1.2 (A), R18.2
unnamed: D2.2 (A), R20.2
unnamed: D3.2 (A), R21.2
unnamed: D4.2 (A), R22.2

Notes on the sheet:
LDO
Power

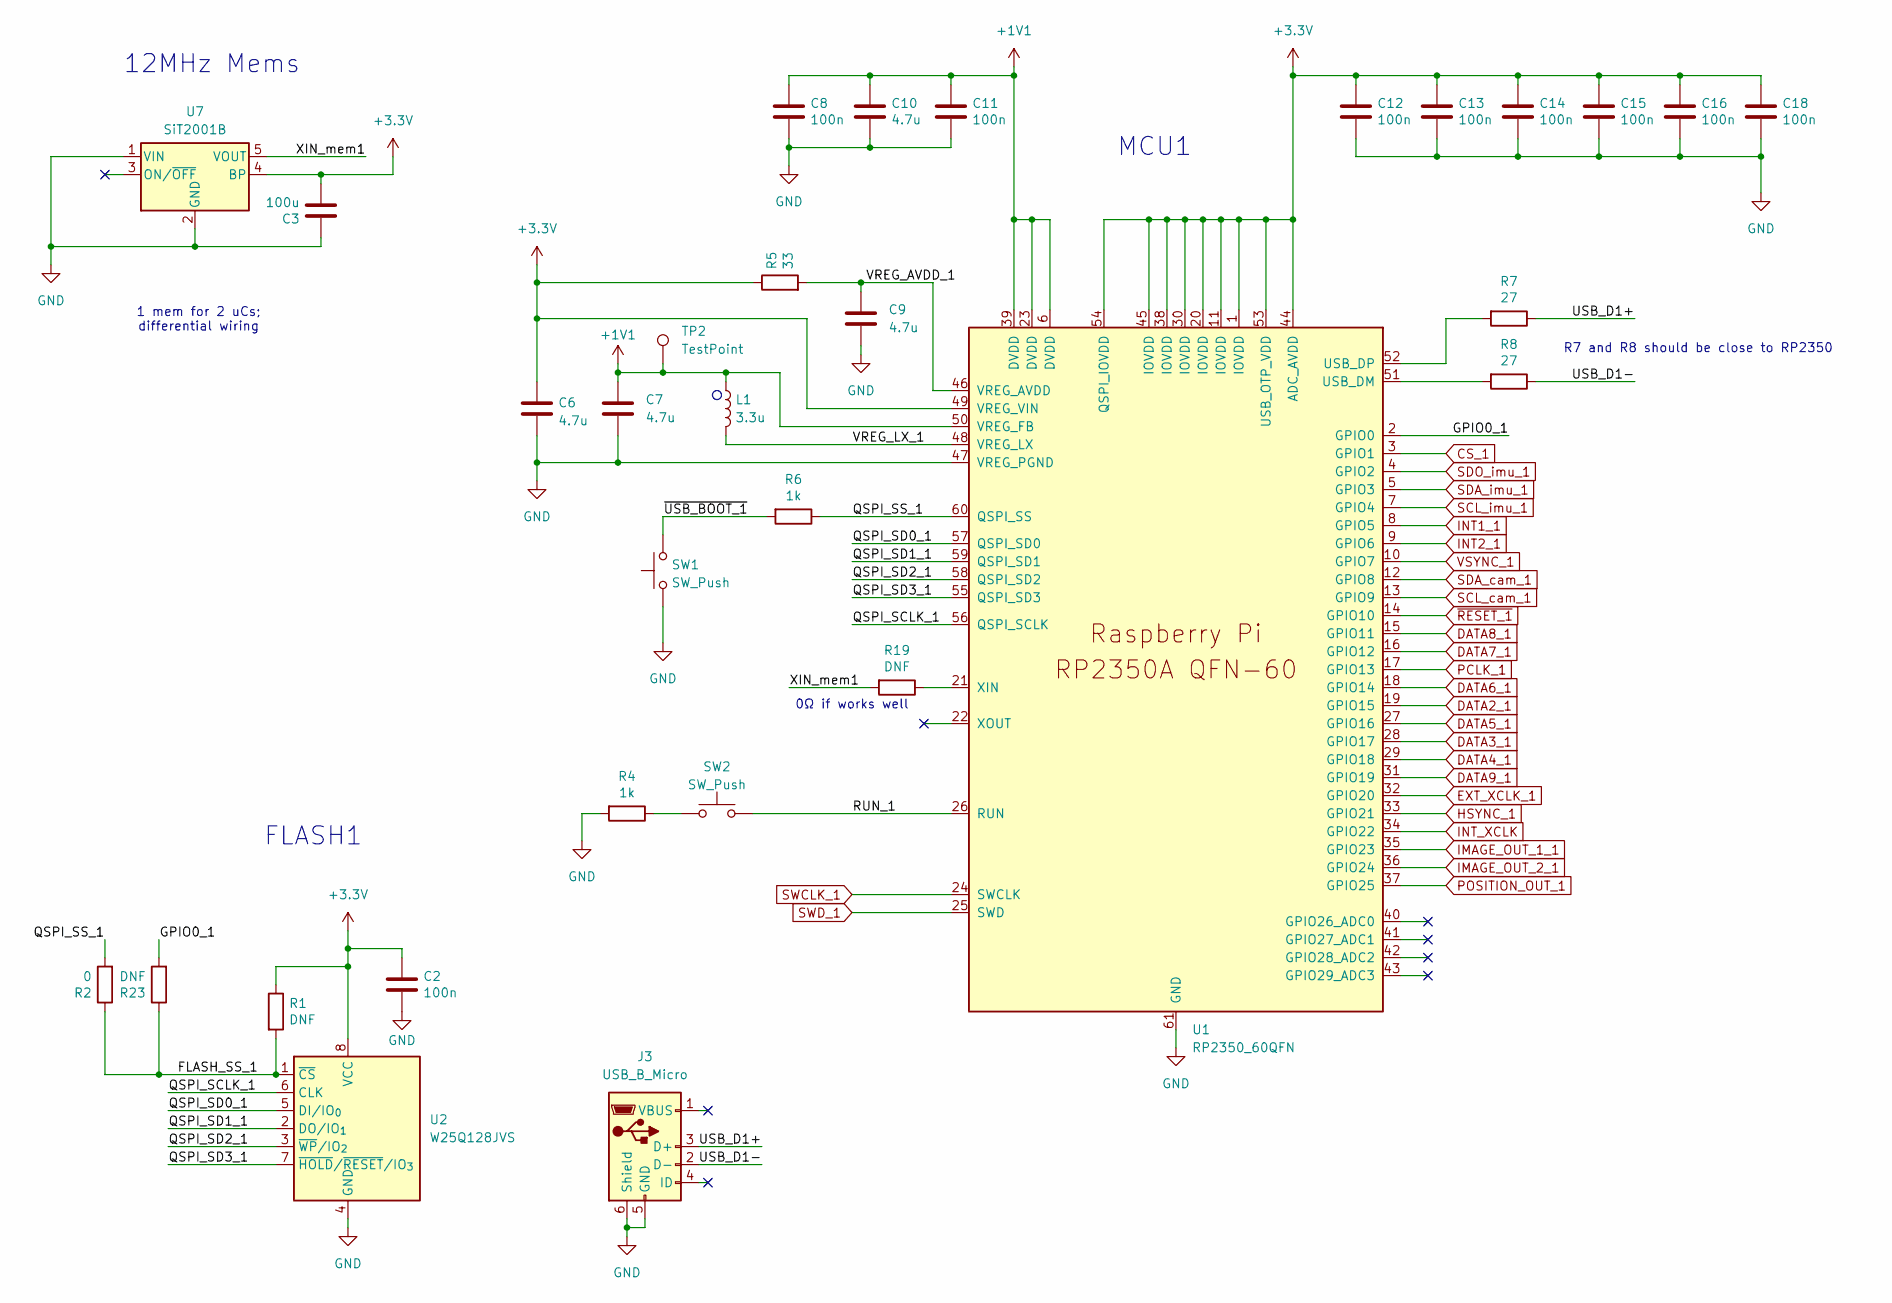
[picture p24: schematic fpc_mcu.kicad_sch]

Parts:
C2, C8, C11, C12, C13, C14, C15, C16, C18: 100n; C_0603_1608Metric_Pad1.08x0.95mm_HandSolder
C3: 100u; C_0603_1608Metric_Pad1.08x0.95mm_HandSolder
C6, C7, C9, C10: 4.7u; C_0603_1608Metric_Pad1.08x0.95mm_HandSolder
J3: USB_B_Micro; USB_Micro-B_Amphenol_10103594-0001LF_Horizontal_modified
L1: 3.3u; L_pol_2016
R1, R19, R23: DNF; R_0603_1608Metric_Pad0.98x0.95mm_HandSolder
R2: 0; R_0603_1608Metric_Pad0.98x0.95mm_HandSolder
R4, R6: 1k; R_0603_1608Metric_Pad0.98x0.95mm_HandSolder
R5: 33; R_0603_1608Metric_Pad0.98x0.95mm_HandSolder
R7, R8: 27; R_0603_1608Metric_Pad0.98x0.95mm_HandSolder
SW1, SW2: SW_Push; SW_Push_1P1T_NO_Vertical_Wuerth_434133025816
TP2: TestPoint; TestPoint_Pad_D1.0mm
U1: RP2350_60QFN; RP2350-QFN-60-1EP_7x7_P0.4mm_EP3.4x3.4mm_ThermalVias
U2: W25Q128JVS; SOIC-8_5.3x5.3mm_P1.27mm
U7: SiT2001B; SOT-23-5

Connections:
+1V1: C7.1, C8.1, C10.1, C11.1, L1.1, TP2.1, U1.6 (DVDD), U1.23 (DVDD), U1.39 (DVDD), U1.50 (VREG_FB)
+3.3V: C2.1, C3.2, C6.1, C12.1, C13.1, C14.1, C15.1, C16.1, C18.1, R1.1, R5.1, U1.1 (IOVDD), U1.11 (IOVDD), U1.20 (IOVDD), U1.30 (IOVDD), U1.38 (IOVDD), U1.44 (ADC_AVDD), U1.45 (IOVDD), U1.49 (VREG_VIN), U1.53 (USB_OTP_VDD), U1.54 (QSPI_IOVDD), U2.8 (VCC), U7.4 (BP); also elsewhere on the board
/MCU/FLASH_SS_1: R1.2, R2.1, R23.1, U2.1 (~CS)
/MCU/GPIO0_1: R23.2, U1.2 (GPIO0)
/MCU/QSPI_SCLK_1: U1.56 (QSPI_SCLK), U2.6 (CLK)
/MCU/QSPI_SD0_1: U1.57 (QSPI_SD0), U2.5 (DI/IO_{0})
/MCU/QSPI_SD1_1: U1.59 (QSPI_SD1), U2.2 (DO/IO_{1})
/MCU/QSPI_SD2_1: U1.58 (QSPI_SD2), U2.3 (~WP/IO_{2})
/MCU/QSPI_SD3_1: U1.55 (QSPI_SD3), U2.7 (~HOLD/~RESET/IO_{3})
/MCU/QSPI_SS_1: R2.2, R6.1, U1.60 (QSPI_SS)
/MCU/RUN_1: SW2.2, U1.26 (RUN)
/MCU/USB_D1+: J3.3 (D+), R7.1
/MCU/USB_D1-: J3.2 (D-), R8.1
/MCU/VREG_AVDD_1: C9.1, R5.2, U1.46 (VREG_AVDD)
/MCU/VREG_LX_1: L1.2, U1.48 (VREG_LX)
/MCU/XIN_mem1: R19.2, U7.5 (VOUT)
/MCU/~USB_BOOT_1: R6.2, SW1.2
CS_1: U1.3 (GPIO1); also elsewhere on the board
DATA2_1: U1.19 (GPIO15); also elsewhere on the board
DATA3_1: U1.28 (GPIO17); also elsewhere on the board
DATA4_1: U1.29 (GPIO18); also elsewhere on the board
DATA5_1: U1.27 (GPIO16); also elsewhere on the board
DATA6_1: U1.18 (GPIO14); also elsewhere on the board
DATA7_1: U1.16 (GPIO12); also elsewhere on the board
DATA8_1: U1.15 (GPIO11); also elsewhere on the board
DATA9_1: U1.31 (GPIO19); also elsewhere on the board
EXT_XCLK_1: U1.32 (GPIO20); also elsewhere on the board
GND: C2.2, C3.1, C6.2, C7.2, C8.2, C9.2, C10.2, C11.2, C12.2, C13.2, C14.2, C15.2, C16.2, C18.2, J3.5 (GND), J3.6 (Shield), R4.2, SW1.1, U1.47 (VREG_PGND), U1.61 (GND), U2.4 (GND), U7.1 (VIN), U7.2 (GND); also elsewhere on the board
HSYNC_1: U1.33 (GPIO21); also elsewhere on the board
IMAGE_OUT_1_1: U1.35 (GPIO23); also elsewhere on the board
IMAGE_OUT_2_1: U1.36 (GPIO24); also elsewhere on the board
INT1_1: U1.8 (GPIO5); also elsewhere on the board
INT2_1: U1.9 (GPIO6); also elsewhere on the board
INT_XCLK: U1.34 (GPIO22); also elsewhere on the board
unnamed: R4.1, SW2.1
unnamed: R8.2, U1.51 (USB_DM)
unnamed: R7.2, U1.52 (USB_DP)
unnamed: R19.1, U1.21 (XIN)
PCLK_1: U1.17 (GPIO13); also elsewhere on the board
POSITION_OUT_1: U1.37 (GPIO25); also elsewhere on the board
SCL_cam_1: U1.13 (GPIO9); also elsewhere on the board
SCL_imu_1: U1.7 (GPIO4); also elsewhere on the board
SDA_cam_1: U1.12 (GPIO8); also elsewhere on the board
SDA_imu_1: U1.5 (GPIO3); also elsewhere on the board
SDO_imu_1: U1.4 (GPIO2); also elsewhere on the board
SWCLK_1: U1.24 (SWCLK); also elsewhere on the board
SWD_1: U1.25 (SWD); also elsewhere on the board
VSYNC_1: U1.10 (GPIO7); also elsewhere on the board
~RESET_1: U1.14 (GPIO10); also elsewhere on the board

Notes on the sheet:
0Ω if works well
MCU1
FLASH1
12MHz Mems
R7 and R8 should be close to RP2350
1 mem for 2 uCs; differential wiring

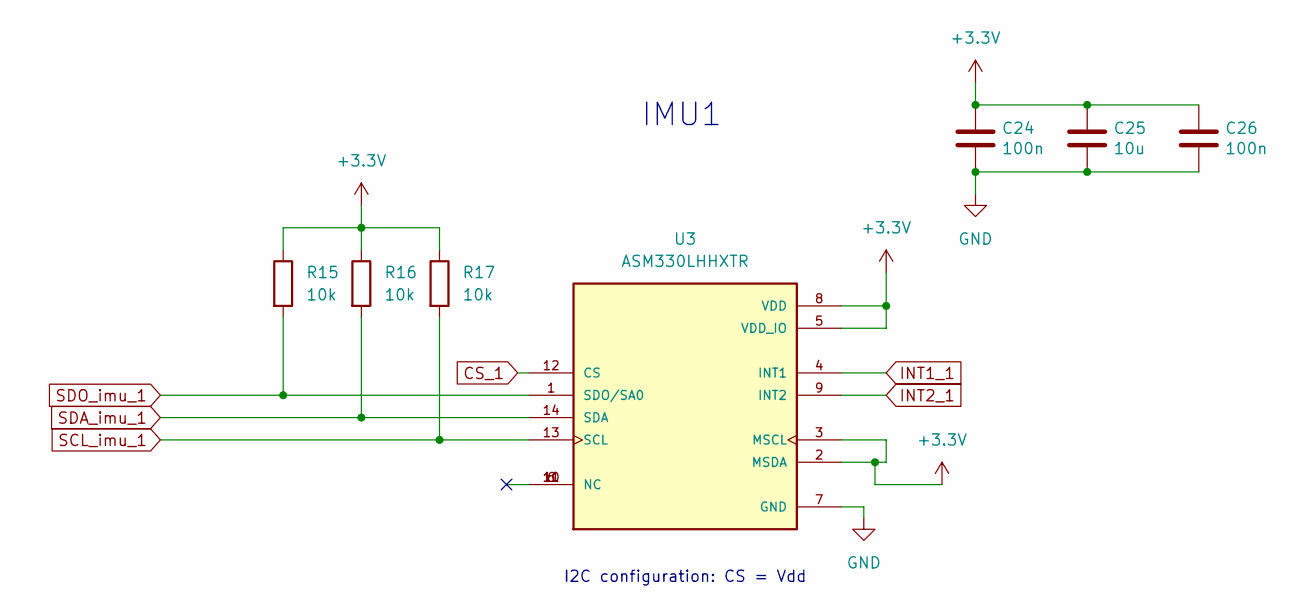
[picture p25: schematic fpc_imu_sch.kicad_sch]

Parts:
C24, C26: 100n; C_0603_1608Metric_Pad1.08x0.95mm_HandSolder
C25: 10u; C_0603_1608Metric_Pad1.08x0.95mm_HandSolder
R15, R16, R17: 10k; R_0603_1608Metric_Pad0.98x0.95mm_HandSolder
U3: ASM330LHHXTR; XDCR_ASM330LHHXTR; PARTREV 8

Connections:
+3.3V: C24.1, C25.1, C26.1, R15.1, R16.1, R17.1, U3.2 (MSDA), U3.3 (MSCL), U3.5 (VDD_IO), U3.8 (VDD); also elsewhere on the board
CS_1: U3.12 (CS); also elsewhere on the board
GND: C24.2, C25.2, C26.2, U3.7 (GND); also elsewhere on the board
INT1_1: U3.4 (INT1); also elsewhere on the board
INT2_1: U3.9 (INT2); also elsewhere on the board
SCL_imu_1: R17.2, U3.13 (SCL); also elsewhere on the board
SDA_imu_1: R16.2, U3.14 (SDA); also elsewhere on the board
SDO_imu_1: R15.2, U3.1 (SDO/SA0); also elsewhere on the board

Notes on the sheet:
I2C configuration: CS = Vdd
IMU1

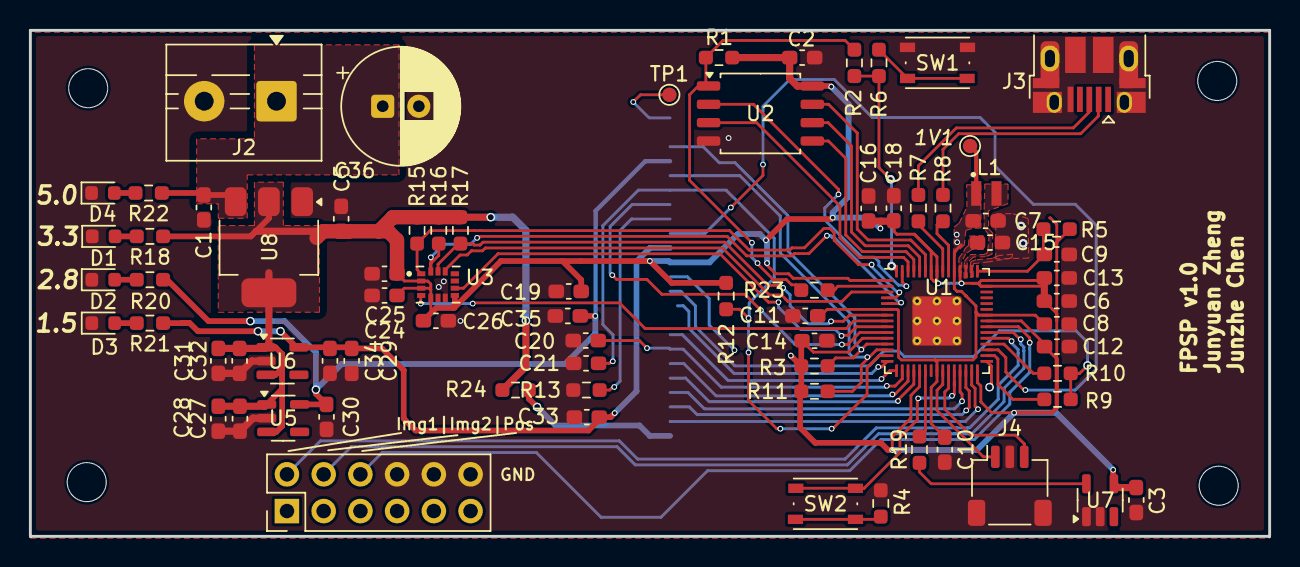
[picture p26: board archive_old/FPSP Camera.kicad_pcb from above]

Board: 4 copper layers, 85.7 x 35.0 mm, 80 parts (1 on the bottom side), 60 nets.

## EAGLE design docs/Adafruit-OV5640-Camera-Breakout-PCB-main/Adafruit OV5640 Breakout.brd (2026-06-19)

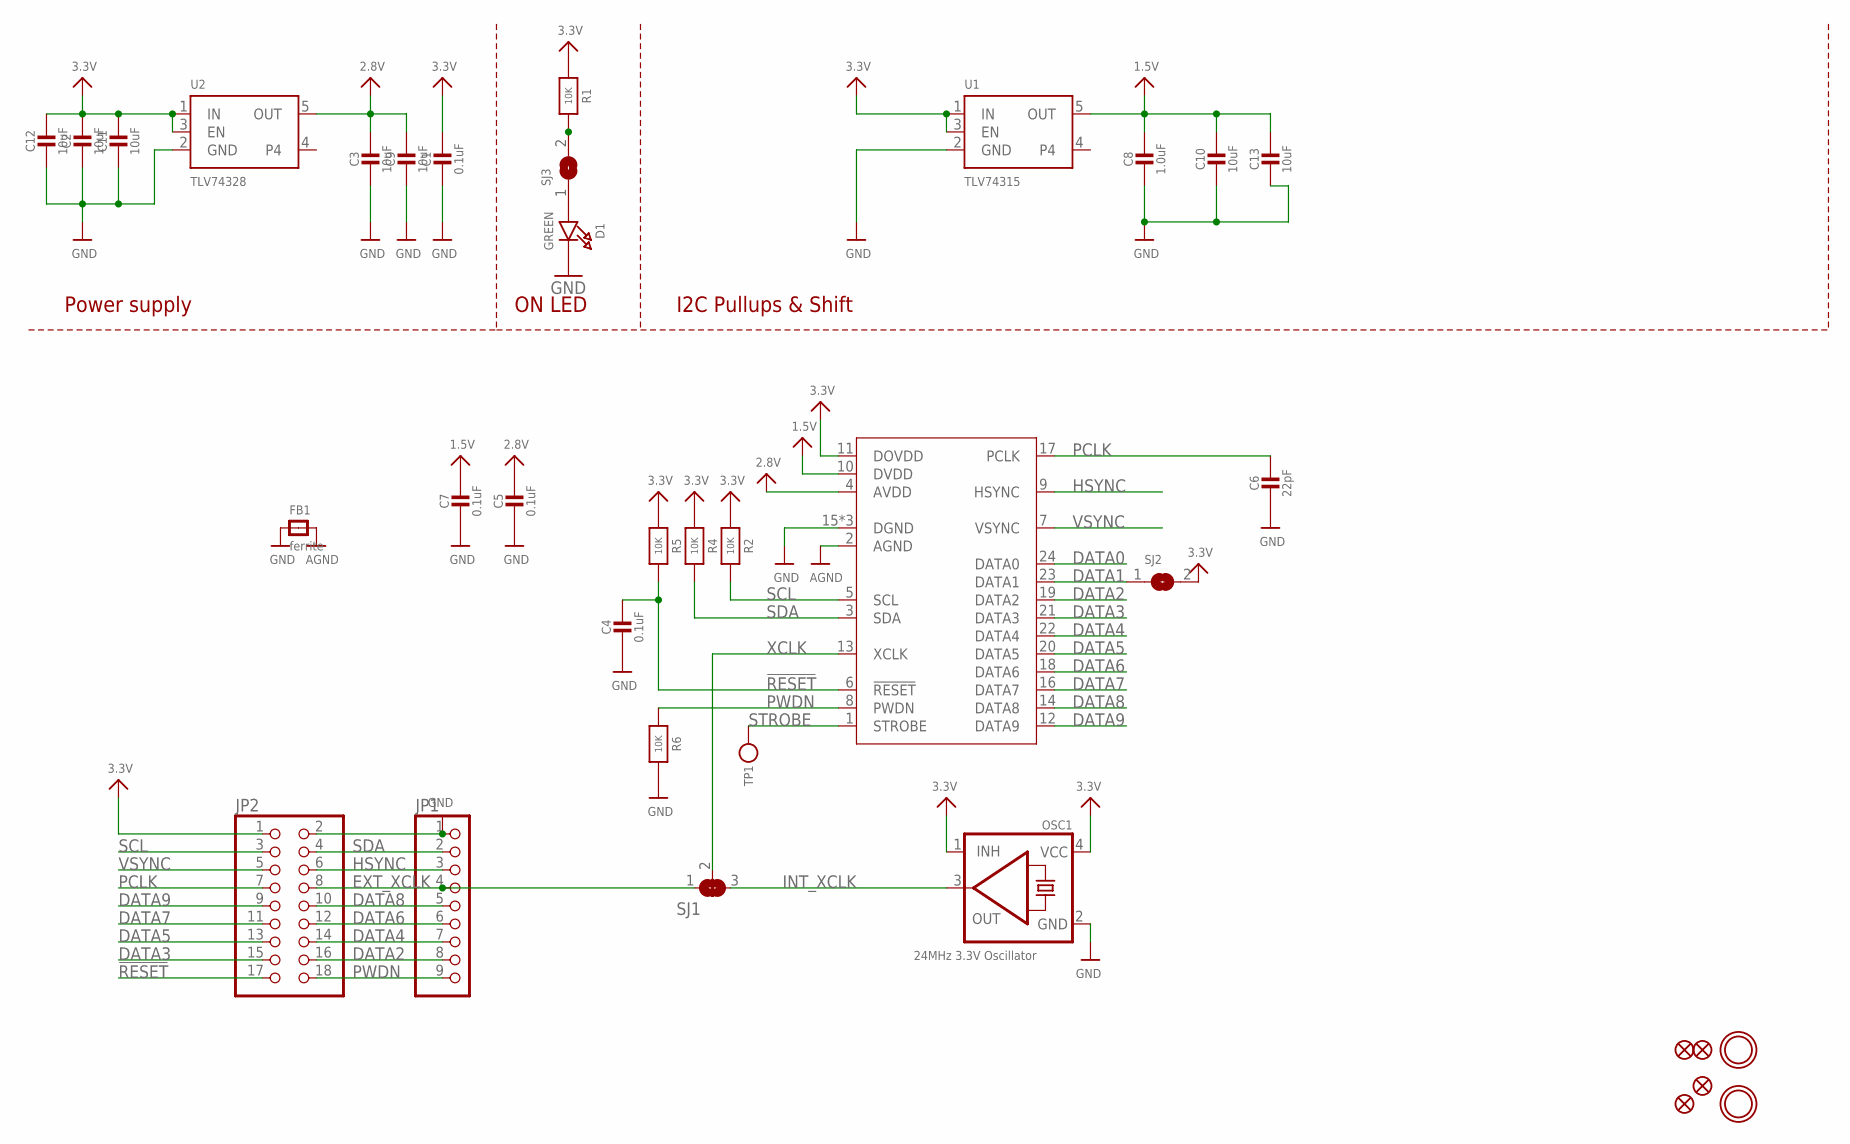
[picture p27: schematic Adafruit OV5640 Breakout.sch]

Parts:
C1, C4, C5, C7: 0.1uF; 0603-NO
C2, C3, C9, C10, C11, C12, C13: 10uF; 0805-NO
C6: 22pF; 0603-NO
C8: 1.0uF; 0603-NO
D1: GREEN; CHIPLED_0603_NOOUTLINE
FB1: ferrite; 0603-NO
FID1, FID2, FID3, FID4: FIDUCIAL_1MM
JP1: HEADER-1X970MIL; 1X09_ROUND_70
JP2: PINHD-2X9-BIG; 2X09-BIG
OSC1: 24MHz 3.3V Oscillator; OSC_3.2X2.5MM
R1, R2, R4, R5, R6: 10K; 0603-NO
SJ1: SOLDERJUMPER_2WAY; SOLDERJUMPER_2WAY_OPEN_NOPASTE
SJ2: SOLDERJUMPER; SOLDERJUMPER_ARROW_NOPASTE
SJ3: SOLDERJUMPERCLOSED; SOLDERJUMPER_CLOSEDWIRE
TP1: TESTPOINTROUND1.5MM; TESTPOINT_ROUND_1.5MM
U1: TLV74315; SOT23-5; JLC_ROTATION 0
U2: TLV74328; SOT23-5; JLC_ROTATION 0
U$1, U$17: MOUNTINGHOLE3.0THIN; MOUNTINGHOLE_3.0_PLATEDTHIN
X1: CAMERA_OV2640; OV2640FSL

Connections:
1.5V: C7.1, C8.1, C10.1, C13.1, U1.5 (OUT), X1.10 (DVDD)
2.8V: C3.1, C5.1, C9.1, U2.5 (OUT), X1.4 (AVDD)
3.3V: C1.1, C2.1, C11.1, C12.1, JP2.1, OSC1.1 (INH), OSC1.4 (VCC), R1.1, R2.1, R4.1, R5.1, SJ2.2, U1.1 (IN), U1.3 (EN), U2.1 (IN), U2.3 (EN), X1.11 (DOVDD)
!RESET: C4.1, JP2.17, R5.2, X1.6 (!RESET)
AGND: FB1.2, X1.2 (AGND)
DATA0: X1.24 (DATA0)
DATA1: SJ2.1, X1.23 (DATA1)
DATA2: JP1.8, JP2.16, X1.19 (DATA2)
DATA3: JP2.15, X1.21 (DATA3)
DATA4: JP1.7, JP2.14, X1.22 (DATA4)
DATA5: JP2.13, X1.20 (DATA5)
DATA6: JP1.6, JP2.12, X1.18 (DATA6)
DATA7: JP2.11, X1.16 (DATA7)
DATA8: JP1.5, JP2.10, X1.14 (DATA8)
DATA9: JP2.9, X1.12 (DATA9)
EXT_XCLK: JP1.4, JP2.8, SJ1.1
GND: C1.2, C2.2, C3.2, C4.2, C5.2, C6.2, C7.2, C8.2, C9.2, C10.2, C11.2, C12.2, C13.2, D1.C, FB1.1, JP1.1, JP2.2, OSC1.2 (GND), R6.2, U1.2 (GND), U2.2 (GND), X1.15 (DGND), X1.SPRT1 (DGND), X1.SPRT2 (DGND)
HSYNC: JP1.3, JP2.6, X1.9 (HSYNC)
INT_XCLK: OSC1.3 (OUT), SJ1.3
unnamed: R1.2, SJ3.2
unnamed: D1.A, SJ3.1
PCLK: C6.1, JP2.7, X1.17 (PCLK)
PWDN: JP1.9, JP2.18, R6.1, X1.8 (PWDN)
SCL: JP2.3, R2.2, X1.5 (SCL)
SDA: JP1.2, JP2.4, R4.2, X1.3 (SDA)
STROBE: TP1.P$1, X1.1 (STROBE)
VSYNC: JP2.5, X1.7 (VSYNC)
XCLK: SJ1.2, X1.13 (XCLK)

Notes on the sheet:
I2C Pullups & Shift
ON LED
Power supply

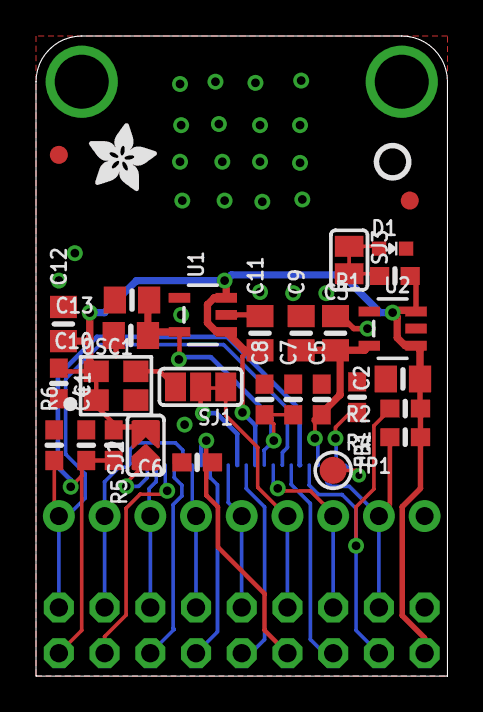
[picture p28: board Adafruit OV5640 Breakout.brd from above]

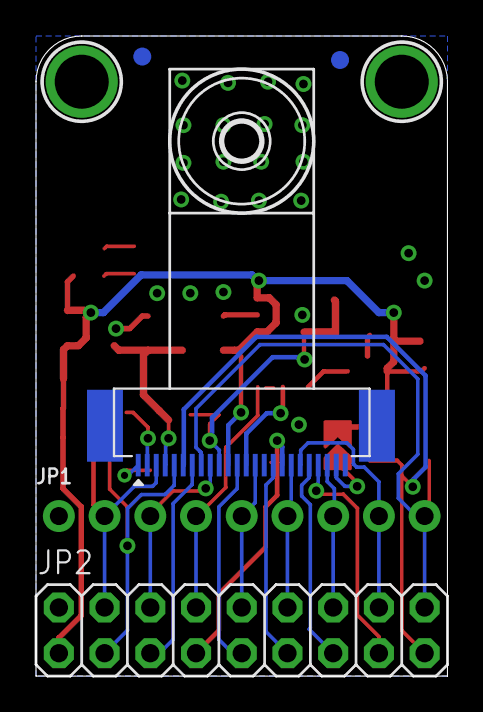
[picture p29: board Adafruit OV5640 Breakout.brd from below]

Board: 2 copper layers, 22.9 x 35.6 mm, 64 parts (27 on the bottom side), 27 nets.

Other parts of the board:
PLABEL0: PLABEL0
PLABEL1: PLABEL1
PLABEL2: PLABEL2
PLABEL3: PLABEL3
PLABEL4: PLABEL4
PLABEL5: PLABEL5
PLABEL6: PLABEL6
PLABEL7: PLABEL7
PLABEL8: PLABEL8
PLABEL9: PLABEL9
PLABEL10: PLABEL10
PLABEL11: PLABEL11
PLABEL12: PLABEL12
PLABEL13: PLABEL13
PLABEL14: PLABEL14
PLABEL15: PLABEL15
PLABEL16: PLABEL16
PLABEL17: PLABEL17
PLABEL18: PLABEL18
PLABEL19: PLABEL19
PLABEL20: PLABEL20
PLABEL21: PLABEL21
PLABEL22: PLABEL22
PLABEL23: PLABEL23
PLABEL24: PLABEL24
PLABEL25: PLABEL25
U$22: ADAFRUIT_3.5MM
U$25: PCBFEAT-REV-040

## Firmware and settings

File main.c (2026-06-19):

/* ============================================================================
 *  main.c  -  RP2354 + OV5640 最小化 Camera Bring-up
 * ----------------------------------------------------------------------------
 *  本工程目的并 *不* 是完整接收图像，只是用最少的逻辑验证：
 *
 *      1. RP2354 是否正常运行                  -> PIO 心跳 + printf
 *      2. SCCB(I2C) 是否能配置 OV5640           -> 写寄存器返回值
 *      3. OV5640 是否输出 PCLK                  -> GPIO 边沿计数
 *      4. VSYNC / HREF 是否正常出现             -> GPIO 边沿计数
 *      5. 任意一个 DATA GPIO (D0) 是否跳变      -> GPIO 边沿计数
 *
 *  工程模块化：
 *      - heartbeat.pio       : PIO 单引脚心跳 (验证 RP2354 + PIO)
 *      - ov5640.c / ov5640.h : SCCB 驱动 + RGB565/DVP 配置 + color bar
 *      - main.c              : XCLK / GPIO / 主循环
 *
 *  约束 (按用户要求)：
 *      - 不使用 DMA
 *      - 不使用 FIFO
 *      - 不实现完整 RGB565 接收
 *      - 不验证 MPU6050 / IMU
 *      - PIO 仅占用 1 个引脚 (heartbeat) , 不参与图像采集
 * ============================================================================ */

#include <stdbool.h>
#include <stddef.h>
#include <stdio.h>

#include "hardware/clocks.h"
#include "hardware/gpio.h"
#include "hardware/pio.h"
#include "hardware/pwm.h"
#include "pico/stdlib.h"

#include "ov5640.h"
#include "heartbeat.pio.h"   /* pico_generate_pio_header 产物 */

/* ---------------------------------------------------------------------------
 *  引脚分配 - 依据 docs/FPSP Camera.kicad_sch 实际网表
 * ---------------------------------------------------------------------------
 *  单端信号：
 *      XCLK    : GP26 (INT_XCLK), RP2354 -> R13 -> XCLK 网络 -> OV5640 主时钟 (PWM)
 *                注意: 相机时钟脚并不在 GP21 (GP21 是 DATA6 数据线)。
 *      VSYNC   : GP7  (VSYNC),  OV5640 -> RP2354, 帧同步
 *      HREF    : GP16 (HSYNC),  OV5640 -> RP2354, 行有效
 *      PCLK    : GP27 (PCLK),   OV5640 -> RP2354, 像素时钟
 *
 *  差分对信号（P/N 接收, 对应原理图 IMAGE_OUT_1 / IMAGE_OUT_2 = 数据位 D1/D0）：
 *      差分对1 (IMAGE_OUT_1): GP15(+) / GP12(-)
 *      差分对2 (IMAGE_OUT_2): GP14(+) / GP13(-)
 *      ※ 当前阶段差分发送端未启用, 这两对脚不会出现有效差分翻转。
 *
 *  其他：
 *      HEARTBEAT_PIN : GP5, 空闲脚。本板无 GPIO 用户 LED (D1~D4 为电源指示灯),
 *                      此脚仅作示波器 / 外接 LED 观测点, 不占用相机数据线。
 * --------------------------------------------------------------------------- */
#define CAM_PIN_XCLK         26u   /* INT_XCLK (PWM 输出) */
#define CAM_PIN_VSYNC         7u   /* 单端 VSYNC */
#define CAM_PIN_HREF         16u   /* 单端 HSYNC */
#define CAM_PIN_PCLK         27u   /* 单端 PCLK */

#define CAM_PIN_D0_P         15u   /* IMAGE_OUT_1 正极 */
#define CAM_PIN_D0_N         12u   /* IMAGE_OUT_1 负极 */
#define CAM_PIN_D1_P         14u   /* IMAGE_OUT_2 正极 */
#define CAM_PIN_D1_N         13u   /* IMAGE_OUT_2 负极 */

#define HEARTBEAT_PIN         5u   /* 空闲脚 (本板无板载 LED) */

/* ---------------------------------------------------------------------------
 *  GPIO 边沿采样参数
 *
 *  说明：
 *      OV5640 在 24 MHz XCLK + 标准 QVGA 输出时, VSYNC 是几十 Hz 量级、
 *      HREF 是若干 kHz, PCLK 是 MHz 量级。我们用裸 polling 不可能跟上 PCLK,
 *      但只要 PCLK 在跳, 多次采样必然能看见 0 -> 1 -> 0 翻转, 所以这里
 *      只要求 "在 N 次采样内出现 ≥ K 次边沿" 就判定为活跃。
 *
 *      SAMPLE_COUNT 取大一些以覆盖 VSYNC 完整帧周期。
 * --------------------------------------------------------------------------- */
#define SAMPLE_COUNT         120000u
#define MIN_EDGES_VSYNC          2u
#define MIN_EDGES_HREF           4u
#define MIN_EDGES_PCLK          50u
#define MIN_EDGES_D0             6u

/* ===========================================================================
 *  XCLK : PWM 输出 ~24 MHz 给 OV5640
 * ---------------------------------------------------------------------------
 *  公式：  f_pwm = clk_sys / ((TOP + 1) * div)
 *  默认 clk_sys = 150 MHz (RP2350 系列), TOP=1, div=3.125
 *      -> 150e6 / (2 * 3.125) = 24 MHz
 *
 *  即使 clk_sys 不是 150 MHz, 频率会有偏差, 但 OV5640 对 XCLK 的允许范围
 *  是 6 ~ 27 MHz, 不影响 Bring-up 验证。
 * =========================================================================== */
static void xclk_init_pwm_approx_24mhz(void) {
    gpio_set_function(CAM_PIN_XCLK, GPIO_FUNC_PWM);

    uint slice = pwm_gpio_to_slice_num(CAM_PIN_XCLK);
    uint chan  = pwm_gpio_to_channel(CAM_PIN_XCLK);

    pwm_config cfg = pwm_get_default_config();
    pwm_config_set_wrap(&cfg, 1u);
    pwm_config_set_clkdiv_int_frac(&cfg, 3u, 2u);   /* 3 + 2/16 = 3.125 */

    pwm_init(slice, &cfg, false);
    pwm_set_chan_level(slice, chan, 1u);            /* 占空比 50% */
    pwm_set_enabled(slice, true);
}

/* ===========================================================================
 *  Camera 信号脚初始化 - 支持单端+差分混合模式
 * ---------------------------------------------------------------------------
 *  所有脚均配置为输入，关闭上下拉，让 OV5640 自由驱动。
 *  差分脚对 (P/N) 独立读取，进行软件差分解码。
 * =========================================================================== */
static void camera_signal_gpio_init(void) {
    /* 单端信号脚 */
    const uint single_pins[] = {
        CAM_PIN_VSYNC,
        CAM_PIN_HREF,
        CAM_PIN_PCLK,
    };

    for (size_t i = 0; i < sizeof(single_pins) / sizeof(single_pins[0]); ++i) {
        gpio_init(single_pins[i]);
        gpio_set_dir(single_pins[i], GPIO_IN);
        gpio_disable_pulls(single_pins[i]);
    }

    /* 差分对脚 */
    const uint diff_pins[] = {
        CAM_PIN_D0_P, CAM_PIN_D0_N,
        CAM_PIN_D1_P, CAM_PIN_D1_N,
    };

    for (size_t i = 0; i < sizeof(diff_pins) / sizeof(diff_pins[0]); ++i) {
        gpio_init(diff_pins[i]);
        gpio_set_dir(diff_pins[i], GPIO_IN);
        gpio_disable_pulls(diff_pins[i]);
    }
}

/* ===========================================================================
 *  PIO 心跳: 仅用 1 个引脚驱动 LED, 用于肉眼判定 RP2354 在跑
 * =========================================================================== */
static void heartbeat_pio_start(void) {
    PIO  pio = pio0;
    uint sm  = 0;
    uint offset = pio_add_program(pio, &heartbeat_program);
    heartbeat_program_init(pio, sm, offset, HEARTBEAT_PIN);
}

/* ===========================================================================
 *  边沿检测：单端信号
 * ---------------------------------------------------------------------------
 *  通过密集 polling 在固定窗口内统计 0<->1 翻转次数。
 * =========================================================================== */
static bool detect_toggling(uint pin, uint32_t sample_count, uint32_t min_edges) {
    uint32_t edges = 0;
    bool     prev  = gpio_get(pin);

    for (uint32_t i = 0; i < sample_count; ++i) {
        bool now = gpio_get(pin);
        if (now != prev) {
            ++edges;
            prev = now;
            if (edges >= min_edges) {
                return true;   /* 提前结束, 缩短主循环延迟 */
            }
        }
    }
    return false;
}

/* ===========================================================================
 *  差分信号检测：P/N 对
 * ---------------------------------------------------------------------------
 *  差分信号逻辑：取 P & ~N，即正极高且负极低时为有效逻辑 1。
 *  检测差分对是否在切换。
 * =========================================================================== */
static bool detect_differential_toggling(uint pin_p, uint pin_n,
                                         uint32_t sample_count,
                                         uint32_t min_edges) {
    uint32_t edges = 0;
    bool prev = (gpio_get(pin_p) && !gpio_get(pin_n));

    for (uint32_t i = 0; i < sample_count; ++i) {
        bool now = (gpio_get(pin_p) && !gpio_get(pin_n));
        if (now != prev) {
            ++edges;
            prev = now;
            if (edges >= min_edges) {
                return true;
            }
        }
    }
    return false;
}

/* ===========================================================================
 *  main
 * =========================================================================== */
int main(void) {
    stdio_init_all();
    sleep_ms(1500);   /* 等待 UART 终端稳定 */

    printf("\n");
    printf("================================================\n");
    printf(" RP2354 + OV5640 minimal camera bring-up\n");
    printf("================================================\n");

    /* ----- 1) 先启动 PIO 心跳, 让 LED 立刻闪 -> RP2354 + PIO OK ----- */
    heartbeat_pio_start();
    printf("[boot] heartbeat PIO running on GP%u\n", HEARTBEAT_PIN);

    /* ----- 2) 给 OV5640 提供 XCLK ---------------------------------- */
    xclk_init_pwm_approx_24mhz();
    printf("[boot] XCLK PWM on GP%u (~24 MHz)\n", CAM_PIN_XCLK);

    /* ----- 3) 准备相机信号 GPIO 为输入 ----------------------------- */
    camera_signal_gpio_init();
    printf("[boot] camera signals initialized:\n");
    printf("       VSYNC=GP%u HREF=GP%u PCLK=GP%u (single-ended)\n",
           CAM_PIN_VSYNC, CAM_PIN_HREF, CAM_PIN_PCLK);
    printf("       D0_diff: GP%u(+)/GP%u(-), D1_diff: GP%u(+)/GP%u(-)\n",
           CAM_PIN_D0_P, CAM_PIN_D0_N, CAM_PIN_D1_P, CAM_PIN_D1_N);

    /* ----- 4) 初始化 SCCB 并跑上电时序 ----------------------------- */
    ov5640_i2c_init();
    ov5640_powerup_sequence();

    /* ----- 5) 读 OV5640 Chip ID 验证 SCCB 通路 --------------------- */
    ov5640_id_t id = {0};
    bool id_ok = ov5640_read_id(&id);
    if (!id_ok) {
        printf("[err ] SCCB read failed -- check wiring / pull-ups\n");
    } else {
        uint16_t chip_id = ((uint16_t)id.high << 8) | id.low;
        printf("[i2c ] OV5640 ID = 0x%04X\n", chip_id);
        if (id.high == 0x56u && id.low == 0x40u) {
            printf("camera detected\n");
        } else {
            printf("[warn] unexpected chip id\n");
        }
    }

    /* ----- 6) 配 RGB565/DVP + color bar ---------------------------- */
    if (!ov5640_init_rgb565_dvp()) {
        printf("[err ] RGB565/DVP configuration failed\n");
    } else {
        printf("[ok  ] OV5640 streaming on, color bar enabled\n");
    }

    /* ----- 7) 主循环: 周期性检测各信号是否仍在跳 -------------------- */
    bool printed_vsync = false;
    bool printed_href  = false;
    bool printed_pclk  = false;
    bool printed_data  = false;

    while (true) {
        if (!printed_pclk &&
            detect_toggling(CAM_PIN_PCLK, SAMPLE_COUNT, MIN_EDGES_PCLK)) {
            printf("pclk active\n");
            printed_pclk = true;
        }

        if (!printed_vsync &&
            detect_toggling(CAM_PIN_VSYNC, SAMPLE_COUNT, MIN_EDGES_VSYNC)) {
            printf("vsync detected\n");
            printed_vsync = true;
        }

        if (!printed_href &&
            detect_toggling(CAM_PIN_HREF, SAMPLE_COUNT, MIN_EDGES_HREF)) {
            printf("href detected\n");
            printed_href = true;
        }

        if (!printed_data &&
            detect_differential_toggling(CAM_PIN_D0_P, CAM_PIN_D0_N,
                                         SAMPLE_COUNT, MIN_EDGES_D0)) {
            printf("data toggling\n");
            printed_data = true;
        }

        /* 全部通过, 打印总结并复位标志, 周期性再验证一次 */
        if (printed_vsync && printed_href && printed_pclk && printed_data) {
            printf("------------------------------------------------\n");
            printf(" CAMERA BRING-UP CHECKS PASSED\n");
            printf("------------------------------------------------\n");
            printed_vsync = false;
            printed_href  = false;
            printed_pclk  = false;
            printed_data  = false;
            sleep_ms(2000);
        }

        sleep_ms(20);
    }
}

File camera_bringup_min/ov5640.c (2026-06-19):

/* ============================================================================
 *  ov5640.c
 * ----------------------------------------------------------------------------
 *  OV5640 SCCB 最小驱动 - Bring-up 用
 *
 *  本文件刻意 *不* 实现完整 RGB565 接收 / DMA / FIFO / 帧缓存，
 *  只完成以下 4 件事：
 *      (1) i2c0 引脚 + 100 kHz 速率初始化
 *      (2) PWDN/RESETB 控制完成上电时序
 *      (3) 16-bit 地址寄存器读 / 写
 *      (4) 写入一个极简寄存器表，开启 RGB565 DVP 输出 + 内置 color bar
 *
 *  写入 color bar 的原因：
 *      OV5640 默认上电后传感器阵列输出未必稳定，若 AEC/AGC/ISP
 *      未配置，可能导致 D0/HREF 抖动不明显。color bar 是芯片内置
 *      的固定纹理发生器，能保证每行/每像素都有跳变，是 Bring-up
 *      最可靠的"信号源"。
 * ============================================================================ */

#include "ov5640.h"

#include <stddef.h>

#include "hardware/gpio.h"
#include "pico/stdlib.h"

/* ---------------------------------------------------------------------------
 * 内部：8-bit value 的 16-bit-addr 寄存器项
 * --------------------------------------------------------------------------- */
typedef struct {
    uint16_t reg;
    uint8_t  value;
} ov5640_reg8_t;

/* 顺序写入一张寄存器表，遇到任意失败立刻返回 false */
static bool ov5640_write_list(const ov5640_reg8_t *regs, size_t count) {
    for (size_t i = 0; i < count; ++i) {
        if (!ov5640_write_reg(regs[i].reg, regs[i].value)) {
            return false;
        }
    }
    return true;
}

/* ===========================================================================
 *  SCCB / I2C 初始化
 * =========================================================================== */
void ov5640_i2c_init(void) {
    i2c_init(OV5640_I2C_PORT, OV5640_I2C_BAUD_HZ);

    gpio_set_function(OV5640_PIN_SDA, GPIO_FUNC_I2C);
    gpio_set_function(OV5640_PIN_SCL, GPIO_FUNC_I2C);

    /* OV5640 模组板通常已经外置 4.7k 上拉，这里再启用 MCU 内部上拉
     * 作为冗余，避免飞线测试时无外部上拉导致挂死。 */
    gpio_pull_up(OV5640_PIN_SDA);
    gpio_pull_up(OV5640_PIN_SCL);
}

/* ===========================================================================
 *  上电时序
 * ---------------------------------------------------------------------------
 *  OV5640 推荐时序 (datasheet 2.7 节)：
 *      DOVDD / AVDD ramp up -> XCLK 稳定 -> PWDN 拉低 -> 等 1ms -> RESETB 拉高
 *
 *  本工程配置：
 *      - PWDN 硬件固定到 GND (10k 电阻)，无需软件控制
 *      - XCLK 由 main.c 在调用本函数之前先用 PWM 拉起来
 *      - 本函数仅控制 RESETB 完成上电时序
 * =========================================================================== */
void ov5640_powerup_sequence(void) {
    /* 只初始化 RESETB，PWDN 已硬件固定到 GND */
    gpio_init(OV5640_PIN_RESETB);
    gpio_set_dir(OV5640_PIN_RESETB, GPIO_OUT);

    /* 1) 进入复位 (RESETB 拉低) */
    gpio_put(OV5640_PIN_RESETB, 0);
    sleep_ms(5);

    /* 2) 释放复位，等 PLL/振荡器稳定 */
    gpio_put(OV5640_PIN_RESETB, 1);
    sleep_ms(20);
}

/* ===========================================================================
 *  SCCB 读写
 * ---------------------------------------------------------------------------
 *  OV5640 SCCB:
 *      - 7-bit 设备地址 (0x3C)
 *      - 16-bit 寄存器地址 (高字节先发)
 *      - 8-bit 数据
 * =========================================================================== */
bool ov5640_write_reg(uint16_t reg, uint8_t value) {
    uint8_t buf[3] = {
        (uint8_t)(reg >> 8),
        (uint8_t)(reg & 0xFFu),
        value,
    };

    return i2c_write_blocking(OV5640_I2C_PORT, OV5640_SCCB_ADDR,
                              buf, 3, false) == 3;
}

bool ov5640_read_reg(uint16_t reg, uint8_t *value) {
    if (value == NULL) {
        return false;
    }

    uint8_t addr[2] = {
        (uint8_t)(reg >> 8),
        (uint8_t)(reg & 0xFFu),
    };

    /* 先发 16-bit 地址 (重复起始, 不释放总线) */
    if (i2c_write_blocking(OV5640_I2C_PORT, OV5640_SCCB_ADDR,
                           addr, 2, true) != 2) {
        return false;
    }

    /* 再读 1 字节 */
    return i2c_read_blocking(OV5640_I2C_PORT, OV5640_SCCB_ADDR,
                             value, 1, false) == 1;
}

bool ov5640_read_id(ov5640_id_t *id) {
    if (id == NULL) {
        return false;
    }
    return ov5640_read_reg(OV5640_REG_CHIP_ID_HIGH, &id->high) &&
           ov5640_read_reg(OV5640_REG_CHIP_ID_LOW,  &id->low);
}

/* ===========================================================================
 *  RGB565 + DVP + color bar 最小化配置
 * =========================================================================== */
bool ov5640_init_rgb565_dvp(void) {
    /* --- 第一步：软复位 ----------------------------------------------------
     *   0x3103 = 0x11   : 系统输入时钟来自焊盘 (即外部 XCLK)
     *   0x3008 = 0x82   : bit7=1 软复位
     */
    static const ov5640_reg8_t reset_regs[] = {
        {0x3103u, 0x11u},
        {0x3008u, 0x82u},
    };
    if (!ov5640_write_list(reset_regs,
                           sizeof(reset_regs) / sizeof(reset_regs[0]))) {
        return false;
    }
    sleep_ms(10);

    /* --- 第二步：唤醒 + PLL + 输出格式 + 测试图样 ---------------------------
     *   0x3008=0x42  : 退出软复位, 但仍处于 software power-down (供后续配置)
     *   0x3035=0x21  : 系统时钟分频器, 保守值
     *   0x3036=0x46  : PLL multiplier
     *   0x4300=0x6F  : 输出格式 = RGB565
     *   0x501F=0x01  : ISP 输出选择 -> RGB
     *   0x3820=0x40  : 行/帧极性、镜像、翻转 (保持默认 + bit6 必置位)
     *   0x3821=0x06  : 同上，bit1 用于 binning
     *   0x503D=0x80  : 启用内置 color bar 测试图样 (关键!)
     *   0x3008=0x02  : 启动 streaming -> PCLK / HREF / VSYNC / D[0..7] 输出
     */
    static const ov5640_reg8_t dvp_rgb565_regs[] = {
        {0x3008u, 0x42u},
        {0x3035u, 0x21u},
        {0x3036u, 0x46u},
        {0x4300u, 0x6Fu},
        {0x501Fu, 0x01u},
        {0x3820u, 0x40u},
        {0x3821u, 0x06u},
        {0x503Du, 0x80u},
        {0x3008u, 0x02u},
    };
    if (!ov5640_write_list(dvp_rgb565_regs,
                           sizeof(dvp_rgb565_regs) / sizeof(dvp_rgb565_regs[0]))) {
        return false;
    }

    /* 留时间让传感器开始输出有效帧 */
    sleep_ms(20);
    return true;
}

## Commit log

2025-11-30 connector PCB added
    [Connector_board.kicad_pcb, Connector_board.kicad_sch, FPSP Camera.kicad_pcb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]
2025-11-30 clean up
    [Connector_board.kicad_pcb, Connector_board.kicad_sch]
2025-11-30 Sch cleanup
    [FPSP Camera.kicad_sch]
2025-11-30 Connector board tweaked
    [Connector_board.kicad_sch]
2025-11-30 routing updates
    [FPSP Camera.kicad_pcb, FPSP Camera.kicad_sch]
2025-11-30 pin assignment done
    [FPSP Camera.kicad_pcb, FPSP Camera.kicad_sch]
2025-11-30 finished connecting all data pins
    [FPSP Camera.kicad_pcb, FPSP Camera.kicad_sch]
2025-12-01 layout finalized (?)
    [Connector_board.kicad_pcb, Connector_board.kicad_sch, FPSP Camera.kicad_pcb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]
2025-12-01 connector board updated
    [Connector_board.kicad_pcb, Connector_board.kicad_sch]
2025-12-01 minor changes
    [FPSP Camera.kicad_pcb, FPSP Camera.kicad_sch]
2025-12-04 minor fixes
    [FPSP Camera.kicad_pcb]
2025-12-08 doc -> pdf updated
    [FPSP Camera.kicad_pcb]
2025-12-10 minor changes in stiffener layers
    [FPSP Camera.kicad_pcb]
2025-12-10 change default clearance, add fabrication files
    [FPSP Camera-B_Cu.gbr, FPSP Camera-B_Mask.gbr, FPSP Camera-B_Paste.gbr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]
2025-12-10 tweak gitignore, add BoM and CPL
    [BoM.csv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]
2025-12-11 manufacturing file for PCB added
    [BoM.csv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]
2025-12-11 update gerber
    [FPSP Camera-B_Cu.gbr, FPSP Camera-B_Mask.gbr, FPSP Camera-B_Paste.gbr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]
2025-12-12 update FR4 version
    [FPSP Camera-B_Cu.gbr, FPSP Camera-B_Mask.gbr, FPSP Camera-B_Paste.gbr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]
2025-12-12 FPC socket foorprint replaced
    [FPSP Camera-B_Cu.gbr, FPSP Camera-B_Mask.gbr, FPSP Camera-B_Paste.gbr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]
2026-06-19 test PCB version 2 completed
    [BoM_overall.xlsx, Connector_board.kicad_pcb, Connector_board.kicad_sch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]
2026-06-19 refined 5V net isolation
    [Connector_board.kicad_pcb, Connector_board.kicad_sch, FPSP Camera.kicad_pcb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]
2026-06-19 Initial commit: FPSP camera FPC bring-up (RP2350/pico2)
    [FPSP Camera.kicad_sch]

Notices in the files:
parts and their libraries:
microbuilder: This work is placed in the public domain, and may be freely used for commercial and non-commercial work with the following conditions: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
